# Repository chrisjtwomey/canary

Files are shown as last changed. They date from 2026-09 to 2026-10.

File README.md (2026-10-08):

# CANARY

CANARY shows the air in a room on a 5.2" e-paper display. It measures CO₂, particulates, gas (VOC),
temperature, humidity and pressure.

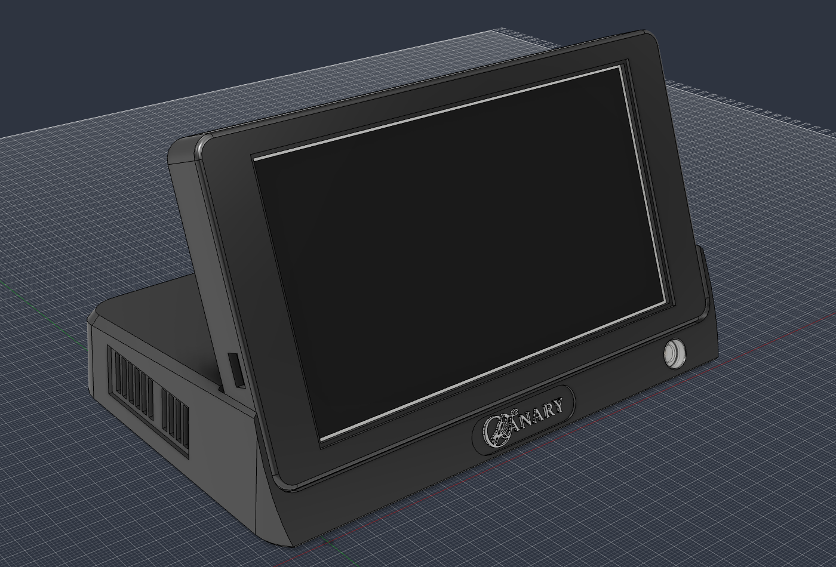
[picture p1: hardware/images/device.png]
CANARY on a desk


It has two halves and a server:

- The **dock** holds the sensors. It takes a reading every 5 minutes, and every 30 minutes from 01:00 to 07:00,
  and sends it to the server.
- The **display** stands on the dock. Every 5 minutes it shows the next page that the server draws from the
  readings.
- The **server** runs on a computer of yours. It keeps the readings, draws the pages, and can update the firmware
  on both boards. Its config sets the times above.

One USB-C cable powers the dock and the display.

| What | Part |
|---|---|
| CO₂ | Sensirion SCD41 (Adafruit breakout) |
| Particulates: PM1.0, PM2.5, PM10 | Plantower PMSA003I (Adafruit breakout) |
| Gas (VOC) and pressure | Bosch BME688 (Soldered breakout) |
| Temperature and humidity | Sensirion SHTC3 (Soldered breakout) |
| Display | Soldered Inkplate 5 Gen2 |
| Dock controller | Unexpected Maker TinyS3 |

## Build one

**You build the firmware yourself.** The dock uses Bosch's BSEC2 library to calculate the air quality index.
BSEC2 is closed source, and Bosch's licence does not let this project give out firmware that contains it. The
build downloads BSEC2 from Bosch, and Bosch's terms then apply to you. Read them first: the
[library's LICENSE.md](https://github.com/boschsensortec/Bosch-BSEC2-Library) links to them.

You need:

- The parts in [hardware/bom.md](hardware/bom.md). They cost about €220.
- A 3D printer with a 0.4 mm and a 0.2 mm nozzle, and a soldering iron.
- A computer that is always on, with Docker, on the same network as the device.
- A computer with a USB port and Chrome, Edge, Opera or Firefox, for the first install on each board.

### 1. Run the server

On the computer that is always on:

```sh
git clone https://github.com/chrisjtwomey/canary.git
cd canary
./setup.sh
```

- `setup.sh` writes `server/config.yaml` for a real install: the pages show your readings, the boards take new
  firmware from the server, and the time zone and the server's address are this computer's. It asks nothing, and
  it keeps a config that exists, so you can run it again at any time. Then it starts the containers.
- The second container builds the firmware for both boards. Its first build takes some minutes.
  To build again, restart the server with `docker compose restart`. `docker compose logs -f firmware-builder`
  shows the build.
- `http://<server>:8080/web/` shows the pages, and `/web/config` is the Settings page. Set your altitude there, in
  the Server tab, so that the pages show the pressure at sea level. **It has no login: anyone on your network can
  change the settings.**
- The readings, board reports, board logs, calibration copies and the HTTPS certificate go in the `canary-data`
  volume. They stay when Docker recreates the container.
- The images follow this repo's `main` branch. Your boards take each new version.

### 2. Install each board's firmware

The first install puts the firmware and your network settings on a board, over USB. After that, each board takes
its firmware from the server.

Install both boards before you build the device. The dock's USB-C socket carries power only. To install the dock
later, you must open it and lift the TinyS3 off its strips.

1. On a computer with a USB port, open `https://<server>:8443/web/install` in Chrome, Edge, Opera or Firefox.
   `setup.sh` prints the address. Your browser warns about the certificate first: select Advanced, then continue.
2. Enter your Wi-Fi name and password. Each saves when you leave its field. Change the server address if the
   boards reach the server by another name.
3. Connect a board with a USB cable, then select Install beside it. After the install the page checks that the
   board joins your Wi-Fi and reaches the server.

- A board's Install button appears once the server has built its firmware.
- Firefox asks to install an add-on for the site first, and it cannot install from an IP address: open the page by
  the server's name.
- Safari cannot install firmware. From a terminal on macOS or Linux, the same install is
  `curl -O http://<server>:8080/install-firmware.sh`, then `sh install-firmware.sh dock` or
  `sh install-firmware.sh display`.
- Behind a reverse proxy that has its own certificate, set the HTTPS port to 0 in Settings and open the page
  through the proxy.

To build and flash the boards with PlatformIO instead, as for development, see [docs/boards.md](docs/boards.md).

### 3. Build it

[hardware/assembly.md](hardware/assembly.md) builds the device in 12 steps, with a picture for each. Set aside a
day. The last step is the first power-up.

## Documentation

| Doc | What it tells you |
|---|---|
| [hardware/](hardware/README.md) | What is in the hardware folder. |
| [hardware/bom.md](hardware/bom.md) | The parts to buy, and what else would do. |
| [hardware/assembly.md](hardware/assembly.md) | How to build the device, step by step. |
| [hardware/enclosure.md](hardware/enclosure.md) | The design of the printed parts, for changes to the model. |
| [docs/architecture.md](docs/architecture.md) | How the firmware and the server work. |
| [docs/readings.md](docs/readings.md) | The data that each board sends. |
| [CONTRIBUTING.md](CONTRIBUTING.md) | For developers: the setup, the tests, and where the other developer docs are. |

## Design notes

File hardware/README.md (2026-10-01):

# Hardware

CANARY has two halves in one desk enclosure:

- The **display** is an Inkplate 5 Gen2: a 5.2" e-paper panel, tilted 20° back. It shows the pages that the server
  draws.
- The **dock** is a TinyS3 with four sensors: CO₂, particulates, temperature and humidity, and gas. It reads the
  room and sends the readings to the server.

The display stands in the dock. An 8-pin magnetic connector carries 5 V up to it, and it is the only connection
between the two halves. One USB-C cable into the dock powers both.

On the desk, it is 150.7 mm wide, 87.3 mm deep and 89.8 mm tall.

The finished device

| Doc | What it tells you |
|---|---|
| [bom.md](bom.md) | The parts to buy, what else would do, and the cost. |
| [parts.md](parts.md) | The datasheet facts for each part, and the power and the I²C bus. For developers. |
| [assembly.md](assembly.md) | How to build it, step by step, with a picture for each step. |
| [enclosure.md](enclosure.md) | The design of the printed parts, for a person who changes the model. |

| In this folder | What it holds |
|---|---|
| `stl/`, `3mf/` | The five printed parts, in print orientation. |
| `step/` | The same parts as STEP, each upright in its own frame. |
| `enclosure.py` | The design: a Fusion script that places each board and builds each part from the numbers in `enclosure.md`. |
| `canary-logo.svg` | The logo's outline in millimetres. The script imports it. |
| `images/` | Views of the model, and the wiring drawings, for the guides. |
| `wiring/` | The circuit as YAML, one file for each run of wire ([wiring/README.md](wiring/README.md)). |
| `logo/` | The source picture, and the script that traced it. |

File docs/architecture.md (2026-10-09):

# Architecture

How CANARY's firmware and server work. This page is the overview, and each topic has a doc of its own. The
hardware is in [hardware/README.md](../hardware/README.md).

## The parts

- **The dock** (TinyS3, `src/dock/main.cpp`) reads the four sensors at the server's slots, queues each reading in
  PSRAM, and posts the queue to the server. It stays online, and light-sleeps between passes of its loop.
- **The display** (Inkplate 5 Gen2, `src/main.cpp`) wakes for each page. It fetches the page, draws it, posts its
  own status, and deep-sleeps. E-paper keeps its image with no power.
- **The server** (`server/`) keeps the readings, draws the pages, holds the schedules and the dock's settings, and
  offers firmware to both boards.

| | Dock | Display |
|---|---|---|
| Board | TinyS3 (ESP32-S3) | Inkplate 5 Gen2 (ESP32-WROVER-E) |
| Between tasks | Light sleep, with Wi-Fi kept | Deep sleep |
| By default | A reading every 5 minutes, and every 30 minutes from 01:00 to 07:00 | A page every 5 minutes, and a sync every 30 minutes |
| Asks the server | `POST /sensor-readings`, `GET /board-settings`, `POST` and `GET /calibration`, `GET /about` | `GET /<page>.png`, `POST /sensor-readings` |
| Power | 5 V from the USB-C socket | 5 V from the dock, through the pogo connector |

## Why two boards

The panel and the sensors are on two boards, in two halves of one enclosure. The display is the Inkplate and
nothing else: its I²C bus carries only its own expander, RTC and panel PMIC, and its regulator carries only itself.
The dock has the four sensors, on a regulator of their own. Three facts forced this
([hardware/parts.md](../hardware/parts.md)):

- **The bus.** With the sensors on the Inkplate's bus, a jammed sensor also stopped the panel refreshes and the
  panel's temperature read, because the expander, the RTC and the PMIC share that bus.
- **The rail.** The Inkplate's regulator gives 500 mA, and it also carries the ESP32 and the panel PMIC. The sensors
  alone peak at about 470 mA.
- **Heat and noise.** The SCD41 needs a supply free of Wi-Fi bursts, and the TinyS3's own regulator would reach
  thermal shutdown if it carried the sensors.

The only connection between the two halves is the pogo connector, which carries 5 V and ground to the display.

## What comes from epd

CANARY uses [epd](https://github.com/chrisjtwomey/epd) for the generic parts, and adds its sensors and its pages.
The kit is a library, not a framework: it does not need to know what a sensor is.

- **Firmware:** epd's Wi-Fi, time, download, `postJson`, back-off and log helpers. The display also uses the image
  helpers and `IBoard` (`EpdBoardInkplate`, built with `-DARDUINO_INKPLATE5V2`). The dock needs no board.
- **Not `run_app()`:** that is epd's deep-sleep program for a board that only draws pages. Each board here does
  more, so each has its own program.
- **Server:** `DisplayServer`, `Page`, `regenerate()`, `DataSource`, the config loader, the readings store and the
  MQTT log relay.
- **Rendering:** `GreyscaleQuantiser` at eight levels, for the panel's eight greys.
- **The wire contract:** `GET /<page>.png`, with the headers that say when to fetch next and what
  ([versions.md](versions.md)).

## Topics

| Doc | What it covers |
|---|---|
| [dock.md](dock.md) | The dock's loop, its clock, the readings queue, and the sensor code |
| [display.md](display.md) | The display's wakes, its notices and its splash screen |
| [schedules.md](schedules.md) | When the page changes, when the dock takes a reading, and when the display syncs |
| [led.md](led.md) | The dock's status LED |
| [versions.md](versions.md) | The headers, `/about`, which versions work together, and firmware updates |
| [dock-settings.md](dock-settings.md) | The dock's settings, which the server holds |
| [readings.md](readings.md) | The JSON that each board posts |
| [simulator.md](simulator.md) | The simulated room and the mock sensors |

## The repo

```
platformio.ini                 envs: esp32 (the display), dock (the TinyS3), dock-mock (-DUSE_MOCK_SENSORS), dock-validate, native, sim;
                               a -dev twin of each board env builds against an epd checkout
partitions.csv
src/main.cpp                   the display: fetch, draw, post its own state
src/dock/main.cpp              the dock's loop (dock.md)
src/defaults.example.cpp       copy to defaults.cpp: Wi-Fi, server URL, MQTT logging
include/sensors/  src/sensors/
  Readings.h  ReadingsJson.cpp                  what the sensors return, and the wire format in readings.md
  IShtc3.h  IScd41.h  IPmsa003i.h  IBme688.h    one interface per part, shaped by its datasheet
  IClock.h  II2cBus.h                           the clock and bus seams
  SensorSuite  SensorHealth                     the four sensors as one begin() and one sample(), and how they fare
  Shtc3Driver  Scd41Driver  Pmsa003iDriver  Bme688Driver  SensirionI2c  Pmsa003iFrame
  IBsec.h  BsecRunner  BsecLibrary              BSEC, in a task of its own
  SensorValidation                              the bench routine's checks
  mock/                                         EnvModel, LaggedValue and the four mocks
include/net/  src/net/         Backlog, BoardSettings, Calibration, ClientStatus, ResetReason, ServerClock, Stamp, Url
include/dock/                  StatusLed (led.md), FanWindow and PostTimer: when the fan runs and the next reading falls;
                               Trial: when a new image is rolled back (versions.md)
include/display/               when the display wakes, what it does after a fetch, and the notices it draws (display.md)
src/notice.cpp                 the notices, with the facts only the display knows at run time
src/splash.cpp                 the splash screen, and the update's progress bar under it
include/display/notices/       the notices, rendered by scripts/notices.py from server/pages/notice.py
include/display/splash.png     the splash screen, rendered by scripts/notices.py from server/pages/splash.py
include/display/fonts/         the pages' face as one-bit fonts, from scripts/gfxfont.py, for the lines the display writes
src/sim/main.cpp               the sensor loop as a host binary
src/validate/main.cpp          the bench routine
lib/bme68x/                    Bosch's BME68x API
scripts/                       bsec.py, dock_core.py, gfxfont.py, notices.py, version.py
test/                          host tests, native env
setup.sh                       the first start: runs docker-compose.yml's setup service, then starts the stack
server/
  server.py                    config, sources, pages, DisplayServer(...).run()
  setup.py                     the setup service: config.yaml from the example, set for a real install, and firmware/
  about.py  version.py         GET /about, and what this server calls itself
  web.py  html_doc.py          /web/: the pages in a browser, the explorer, and GET /history
  install_page.py              /web/install: epd's install page in this site's layout, with the boards' network
                               settings above the boards
  config_page.py               /web/config: config.yaml as a form in tabs and as text, checked, saved, and restarted on;
                               whether each board runs the saved settings
  config_form.py               the form's fields, and how a filled-in form edits config.yaml
  transfer.py                  a store out to a file and back in, and what it holds, for the Storage tab
  board_logs.py                what each board logs over MQTT, for the Logs view
  schedule.py                  the dock's reading slots (schedules.md)
  broker.py                    the MQTT broker the boards get when config.yaml names none for them
  off_hours.py                 the splash screen while the page schedule is off (schedules.md)
  after_reading.py             each page made after the dock's reading at its slot, and the display's wake after
                               that (schedules.md)
  dock_settings.py             the dock block and GET /board-settings (dock-settings.md)
  display_settings.py          whether the display runs the saved display and image blocks (schedules.md)
  sources/                     the mock room, readings ingest, calibration store, device status, the corrections
                               the pages see: sea-level pressure, and no IAQ below accuracy 2
  pages/                       Breathe, Comfort, Dust, Air, Day, the Diagnostics pages, the trace and delta pages, and
                               the splash screen with its logo
  metrics.py                   derived values and wording; the comfort edges, ISO 7730's PMV, and their words
  static/                      CSS, fonts, charts.js; web.css, browse.js, explore.js, config.js, sheet.js,
                               install-form.js and install-sketch.js for /web/
  config.example.yaml
hardware/                      the boards, the desk enclosure and how to build it (hardware/README.md)
docs/                          these docs, and the developer guides that CONTRIBUTING points to
```

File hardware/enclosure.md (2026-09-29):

# The enclosure

The design of the printed parts, for a person who changes the model. To print and build the enclosure, you need
only [bom.md](bom.md) and [assembly.md](assembly.md).

The enclosure holds the Inkplate 5 Gen2 and the four sensor boards: a thin display, tilted 20° back, stands in a
low sensor dock that extends behind it. It has rounded plan corners, drafted walls, a continuous shadow gap in
place of grilles, and no fixings that show from a normal angle.

The design is in Fusion (project **CANARY**, design **CANARY**). `enclosure.py` makes every part, every board
placement and the wiring layers again from the numbers in this file.

The four enclosure parts print in **PLA+ with a 0.4 mm nozzle**. The logo needs the **0.2 mm nozzle**, and prints
in white on its own plate.

On the desk: **150.7 wide × 87.3 deep × 89.8 tall mm**. The dock's top is one plane, 33.9 mm tall at the front
edge and 25 mm at the rear, 5.15°. The rear is set by the TinyS3's USB-C under the skin; over the PMSA003I's
header the Dupont housings and the wires arcing over them have 1.4 mm to spare, see
[assembly.md](assembly.md#8-wire-the-dock).

## Working on the model

`enclosure.py` is the design. The Fusion document is not in this repository: the script builds the whole thing in
an empty design, and downloads the Inkplate, Adafruit and pogo STEP models it places. Fusion's own copy holds the
saved milestones.

- Run it from **Fusion's script editor**: Utilities → Scripts and Add-Ins → the green **+** beside "My Scripts",
  pick the file, then Run. A full run takes a few minutes and needs a network connection the first time, for the
  STEP downloads.
- It is **re-runnable**. Every part is rebuilt from scratch each time, and components are reused by name, so
  nothing is duplicated. Edges rounded by Fusion features are found geometrically, not by index.
- The report it prints at the end is the check: `lumps_must_all_be_1` (each printed part is one solid),
  `inkplate_insertion_blocked_mm3` (the board can still go in), `cover_pullout_blocked_mm3` (the cover cannot
  drop out of the tray), `interference`, `printability` and `wiring`. The pull-out figure must be more than 0.
  All the others must be empty or 0: a part that touches another lands on it, it does not overlap it.
- **Exports** are made in a second step, never in the same run as the build: the transformed bodies first, the
  export calls after, or Fusion writes empty files.

## Shape

It is meant to sit on a desk without announcing itself, which drove the architecture:

- **The sensors live in the dock, not behind the display.** That keeps the centre of mass low (below) and lets the
  display be only 14 mm thick.
- **The dock is a chassis inside a shell.** The shell is one uninterrupted skin; all four of its screws come up
  from underneath through the chassis, so nothing breaks the top or the sides.
- **The front is one continuous 20° slab.** The display's bezel and the dock's front face lie in the same plane
  with only a parting line between them. At the sides the dock's walls frame the display, 1.3 mm outside it at the
  top. Two other shapes would work: side walls that stop behind the display, with a 2 mm shoulder round its bottom
  corners; or no side draft, so the display is flush with the dock's sides the full height, which looks boxier.
- **Nothing is square.** 10 mm plan radii on the dock and 5 mm on the display, a 1.5 mm chamfer round the top edge and
  a 1.2 mm round on the bezel, and 4.3° of draft on the side and rear walls so the dock reads as a foot, not a box.
- **The vents are hidden.** A 1.5 mm shadow gap under the whole shell replaces every grille; the only visible
  openings are the PMSA003I's, sunk in a recessed strip on the left wall.

## Stability

- Mass ≈ 280 g: 92 g Inkplate, 52 g display shells, 145 g dock and boards (PLA+ or PETG at ~1.24 g/cm³, printed
  near solid).
- The centre of mass is **≈ 27 mm above the desk and 32 mm back**. That was worked out for a dock 3.5 mm lower,
  and the difference moves it by less than a millimetre.
- Only the chassis touches the desk (X −7.1…132.4, D 3.5…82.5). So the device tips only at ≈ 46° forward, 62°
  backward or 68° sideways.
- The sensors in the dock give that margin. In the display, they would be 40 mm higher.

## Parts

| Part | Print orientation | Fixings |
|---|---|---|
| **Display tray** | face down | Bezel (2.4 mm lip) and four walls, 14.1 mm deep, 5 mm plan radii, 1.2 mm round on the bezel edge. Right wall 7.3 mm thick, carrying the USB-C, power-button and microSD pockets; left wall 2 mm with the wake-button hole. The rear edge of the walls carries what holds the cover: a 1 mm step all round as its seat, two tongue slots in the thin wall, and two ear pockets with heat-set inserts in the thick wall's corners. No vents. |
| **Display back cover** | flat, outside down | 2 mm plate resting on the Inkplate's four 7.2 mm SMT standoffs and screwed to them: 4 × M3 through clearance holes, counterbored 0.7 mm so the heads sit near flush in a 2 mm plate. It holds the tray with two 12 mm tongues on one side edge and two ears on the other, each ear screwed to an insert in the thick wall. It goes on tilted, tongues first, and swings down. One grille band over the ESP32 (8 capsule slots, X 74–94, Y 14–40) — the display's only opening, facing up and back. |
| **Dock chassis** | upright (desk face down) | Floor, the solid 20° cradle block with the display pocket, and every bay feature: board bosses, the SCD41 compartment, the SHTC3 baffle, the AMS1117 pocket. It also carries the pogo plinth standing in the trench. Nothing fastens the display: the connector's two Ø5 magnets hold it down and the cradle pocket locates it. It also carries the TinyS3's cradle, whose channel is the dock's wiring duct, the USB-C socket's holder by the rear wall, and the status LED's access pit. |
| **Dock shell** | upside down (top skin on the bed) | The visible skin: rounded, drafted walls, the sloped top and a 2 mm front wall under the display, in one piece with no top-side fixings. 4 × M3×8 countersunk up from underneath into heat-set inserts in its internal pillars, which stand on 1 mm bosses on the chassis floor (×10 bottoms out — the insert ends at 8.7 mm). A Ø4 post holds the AMS1117 module down, and the PMSA003I's seal rib is part of this wall. |

0.4 mm nozzle, 2 mm walls and skin, 2.2 mm slots on a 3.4 mm pitch where slots remain. The shell prints upside
down so its whole outer surface is either on the bed or a drafted wall — no supports; the STL is rotated 5.15° past
the flip so the whole skin lies flat on the bed. Everything is printed in **PLA+**: the only heat in the dock
is the AMS1117's few hundred milliwatts, so PETG is the fallback if its pocket or the shell post over it ever
softens.

**Nothing stands inside the display's cavity, and nothing may.** The Inkplate is 130.59 × 75.23 in a 134.6 × 77.2
opening: 2 mm a side in X, because SW2 and the wake switch stand 0.85 mm past the board's left and right edges,
and 1 mm at the top and bottom. The board goes in from the back, so its footprint sweeps the whole cavity on the
way to its seat. A boss in the cavity would stop it, however far behind the seated board the boss is. So the
cover screws to the Inkplate's own standoffs, and magnets hold the display.

SW2 and the wake switch sit 1.15 mm behind the walls' inner faces, so a finger cannot reach them. Press them
with a pin. If a switch must take a finger, fit a printed plunger in its hole before the Inkplate goes in, with a
flange inside the wall to hold it. SW2 is bypassed (R34 bridged), so the wake switch would get a plunger first.

The cover goes in from the back in a straight line. So only a feature that engages after the cover is in can
hold it:

- Two tongues on its thin-wall edge go into slots in that wall.
- Two ears at the other end sit in pockets in the thick wall, and screw into inserts.

All of it is cut into the walls, so the board still passes. With the panel facing up, the tongues and the two ear
screws carry the Inkplate. `enclosure.py` reports what stops the cover from dropping straight out as
`cover_pullout_blocked_mm3`, which must be **more than 0**.

- A step for the cover's edge alone holds nothing: it stops the cover in the same direction as the bezel lip.
- Clips are not used: PLA+ ridges wear.

The bezel lip stands 0.15 mm clear of the panel, and the tongues have the same play in their slots. A wall that
prints that much short therefore cannot make the ear screws press the lip on to the glass.

## Fasteners

Six brass heat-set inserts carry the screwed joints between printed parts: four hold the shell on the chassis,
and two hold the back cover's ears on the tray. The back cover also screws into the Inkplate's own standoffs. The
pogo connector's two magnets hold the display down. All other screws go straight into printed plastic.
[bom.md](bom.md) gives the quantities to buy.

| Fastener | Qty | Where | Hole |
|---|---|---|---|
| M3 heat-set insert (≈ 5.7 long, 4.6 OD) | 6 | Dock shell, internal pillars (4); display tray, thick wall corners (2) | Ø 4.0 × 6.0 deep |
| M3 × 8 countersunk, 90° | 4 | Shell → chassis, up from underneath | Ø 3.4 clearance, Ø 6.2 × 1.4 cone |
| M3 × 6 machine screw | 6 | Display back cover → the Inkplate's four SMT standoffs (4) and the tray's two inserts (2) | Ø 3.4 clearance; Ø 6.2 × 0.7 counterbore over the standoffs only |
| M2 × 4 self-tapping, pan head | 8 | PMSA003I and SCD41, 4 each | Ø 2.1 pilot, 3 mm deep |
| M2.5 × 4 self-tapping | 8 | BME688 and SHTC3, 4 each | Ø 2.6 pilot, 3 mm deep |

- Board pilots are blind, in 2 mm bosses on the chassis floor: 3 mm of engagement with 1 mm of floor left under
  them, so no screw breaks the desk face. Two screws per sensor board carry a few grams comfortably; all four holes
  are there if wanted.
- **Board screws are one nominal size under their pilot** *(measured on a PLA+ print)*, for two separate
  reasons. The PMSA003I's board holes are 2.5 mm, so an M2.5 screw cannot pass through one — M2 is the only option
  there, and the SCD41 takes the same screw for consistency though its 3.0 mm holes would also accept M2.5. The
  Soldered boards' 3.2 mm holes would pass M3 happily; what rules M3 out is the printed pilot, since Ø 2.6 nominal
  finishes nearer 2.4 on an FDM print and a thread-former that tight in PLA+ splits the boss. Do not re-cut the
  pilots to suit the smaller screws: they are sized for how the hole prints, not for how it reads in CAD.
- Every self-tapper is sized to stop **short of the blind end of its pilot**, not to fill the material: a tapered
  tip driven into the last millimetre wedges the boss open. A 1.57 mm board plus 3 mm of pilot leaves 4.6 mm,
  hence 4 mm screws and 2.4 mm of engagement — short of the usual 2 × diameter, but these are five-gram boards.
- The shell screw stops at 8 mm: it passes 3 mm of floor and boss and holds 5 mm of the insert, which ends at 8.7, so an M3 × 10 bottoms out.
- The cover's counterbore leaves 1.3 mm of plate under each screw head, so an M3 × 6 puts about 4.7 mm of thread
  into the 7.2 mm standoff.
- Self-tapping into PLA or PETG holds fine for a one-time build. If boards will come in and out repeatedly, those
  pilots strip after a handful of cycles and want inserts instead — which means taller, wider bosses.

## Frames

**Display frame**: X left → right seen from the front (the Inkplate PCB spans 0…130.59), Y up (PCB 0…75.23), Z
toward the viewer with Z = 0 at the panel's front face. In Fusion, X_f = X, Y_f = −Z, Z_f = Y. Z levels: bezel
front +2.4 · panel 0 · PCB back −2.45 · standoff tops / cover inner −9.67 · cover outer −11.67.

**Dock frame**: X as the display, D = depth from the front-bottom edge (0…86 nominal, 87.9 including the draft),
H = height above the desk. This is Fusion's world frame; the `Dock` component is untilted and the `Display`
component carries the 20° tilt. Bay interior X −8.6…133.9, D 25…84, H 2 up to the skin's underside (28.5 at D 25,
sloping to 23 at the rear). Board component faces at H 5.6 (Adafruit / Soldered) and 6.0 (AMS1117, raised so the
regulator on its underside hangs in free air).

Inside `Dock`, only the chassis and the shell sit at the top level. Every board, the pogo female and **Dock wiring
(toggle)** sit in **Dock electronics (toggle)**; switch its light bulb off to see the bare printed parts.

The display's front-bottom edge lands at D 4.91 / H 13.5, chosen so the **bezel plane passes through (D 0, H 0)** —
that is what makes the dock's front face and the bezel one plane. Change `DISPLAY_FRONT_H` and the front slab
follows automatically.

## Surfacing rules

- **Plan corners** are built into the solid, not filleted: the shell's outer prism is four truncated cones
  (r 10 mm at the top, growing with the draft) plus two tilted-plane slabs. The cavity uses r 8 and the chassis
  r 6.5 about *the same centres*, so the wall stays 2 mm and the chassis-to-shell gap stays 1.5 mm all the way
  round the corner.
- **Draft** 4.3° on the sides and rear, referenced to the top of the walls: 2.0 mm wider at the desk than at the
  top, where the shell stands 1.3 mm outside the display's sides. The front (bezel) plane and the cavity are not
  drafted. Flush with the display, the draft would carry the side walls out past its vertical sides to a knife edge;
  1.3 mm out, the wall beside the display is 0.8 mm at the top of the walls and thickens down the draft.
- **The top chamfer is also solid geometry.** A 2 mm skin cannot carry a fillet larger than 1.17 mm — the arc
  breaks through into the cavity at the corner — whereas a 45° chamfer of leg *c* only eats (4 − c)/√2, so 1.5 mm
  is comfortable. It is made by intersecting the shell with a 45°-drafted prism whose reference plane is rotated
  onto the sloped top, which also wraps it around the rounded corners. Fusion's own chamfer feature fails here
  (`ASM_BL_UNFIN_SHEET`) because the chain runs out onto the display opening's curved wall.
- Only two rounds are real features: the bezel's outer edge (1.2 mm, limited the same way by the 2 mm wall and
  2.4 mm lip) and the shell's bottom rim (0.8 mm chamfer). Both are picked geometrically, so the script re-runs.

## Ventilation

There are no grilles on the top, the right side, the rear or the display.

- **Shadow gap.** The shell's bottom rim floats 1.5 mm above the desk and the chassis is inset 1.5 mm from the
  shell's inner wall, so the gap is not decorative: room air passes under the rim, up the slot between chassis
  and shell, and into the bay. Open area ≈ 390 mm² along the bay's sides and rear.
- **PMSA003I.** The fan needs its own path and cannot use the gap: its inlet and outlet are both on the face
  against the left wall, 8 mm above the gap and up to 40 mm away. So that wall keeps two real slot groups
  (D 41.4–54.5 for the outlet, D 58.4–78 for the inlet), sunk in a 1 mm recessed strip so they read as one
  detail rather than a grille. A 4.6 mm rib on the shell's inner wall (D 54.8–58.1, H 1.5–19) crosses the 4.8 mm
  gap between that wall and the module's face, between the two slot groups, so exhaust cannot run along it into
  the inlet. It is on the shell, not the chassis: the chassis is inset 1.5 mm from this wall and could only reach
  it as a detached island. The 3.1 mm of rib that reaches over the chassis floor starts 0.2 mm above it, so the
  shell still drops on freely.
- **SCD41** breathes through its compartment's open front (≈ 500 mm² facing the bay) rather than a lid grille.
  If its response turns out sluggish, the fix is a slot row low in the compartment's left wall.
- **Display.** Sealed except for one grille band in the back cover: 8 stadium slots, 2.2 × 20 mm on the usual 3.4 mm
  pitch, X 74–94 and Y 14–40, ≈ 344 mm². They sit over the **ESP32-WROVER** (X 75–93, Y −0.2–31.8). It is the display's only real heat source, at
  80–150 mA while it is awake with Wi-Fi, and it sits directly behind the panel. It deep-sleeps between pages. The slots run
  **along X**: everything else about this object is horizontal — the shadow gap, the PM's vent strip — and vertical
  ticks cut across all of it. One band spanning low to high also vents better than two discrete ones, since the 20°
  tilt makes the bottom rows the intake and the top rows the exhaust. Y 14 is the lower limit: the display's five wires
  cross the board at Y 3–11 and would otherwise show through.

### Heat

| Source | Dissipation | Note |
|---|---|---|
| Whole dock, averaged | ~0.25 W | 48.9 mA at 5 V with light sleep and a reading every 5 minutes *(measured, [parts.md](parts.md#tinys3--the-dock))* |
| AMS1117, while the PM fan runs | ~0.19 W at 110 mA | 1.7 V dropped. A SOT-223 on the module's copper runs ~70 °C/W, so the tab sits about 13 °C above the room. Rated 125 °C. |
| PMSA003I, while its fan runs | ~0.3 W | 95 mA at 3.3 V *(measured)*. It vents straight out through the left wall. |
| Sensors | < 0.1 W | |

The PM fan runs only for the 35 s before each reading, so its rows are peaks, not averages.

There is no fan. Under a watt in a vented dock warms the air near the parts by a degree or two, and the far
corner not at all. A fan would blow over the SHTC3, stir the SCD41's compartment, and move the BME688's heat
about. So both heaters sit on the PM side, as far from the SHTC3 as the layout allows.

---

## Bay layout

Each board's place follows the placement rules in its section of [parts.md](parts.md):

- **SHTC3**: at a corner or edge, in the incoming airflow, slit-isolated from any mounting plate, nowhere near the
  Inkplate's LDO, PMIC or ESP32 or the PM fan's exhaust. It sets the reading everyone sees.
- **PMSA003I**: inlet and outlet against an enclosure wall or separated by a baffle; enclosure vent no smaller than
  the inlet; ≥ 20 cm off the floor; its exhaust pointed away from the SHTC3 and SCD41.
- **SCD41**: its own compartment with a large opening, small dead volume, out of the direct airflow, lowest point
  of the device, away from the fan and the Inkplate's warm parts. Membrane untouched.
- **BME688**: anywhere with air access; its heater is a heat source for the others, so not adjacent to the SHTC3.
- **Inkplate**: the ESP32, LDO and panel PMIC are the warmest parts; the sensors go on the opposite side or in a
  ventilated bay.
- Vent the sensor bay on two sides so air moves through rather than pooling.

| Board | X × D (mm) | Placement |
|---|---|---|
| PMSA003I | −3.8…31.8 × 27…77.8 | Left end, module face 4.8 mm from the left wall and its vents. X −3.8 puts the board edge and its two left bosses 3.3 mm inside the edge of the chassis floor (which is inset 1.5 mm from the wall). Header row along its **front** edge, so the tall Dupont housings stand behind the display where the dock is deepest. D 27 (not 30) keeps its rear corner clear of the cavity's 10 mm rounded corner. |
| SCD41 | 49.9…72.8 × 35…60.4, sockets facing front and rear | Middle, in its own compartment (walls X 47.3–48.8 and 74.3–75.8 from D 30, rear wall D 72–73.5, all to the skin). Both sockets in use; nothing else is connected to it. |
| SHTC3 | 82.8…120.8 × 26.5…48.5 | Front-right: coolest corner, against the solid cradle block, farthest from the fan and the LDO, behind a full-height baffle at D 50–51.5. End of the chain, only its right socket used. |
| BME688 | 82.8…120.8 × 53.5…75.5 | Rear-right, behind the baffle. Both sockets in use. |
| AMS1117-3.3 | 8…20.5 × 80.5…89, **across the bay, pins to the right** | Behind the PM board, its header end towards the TinyS3's channel. No mounting holes: it sits in a pocket 0.5 mm clear of the board on every side (0.3 mm a side would give a 9.1 mm slot, too tight to trust an FDM print with), with 1 mm locating walls and 2.5 mm corner tabs, so the underside is open. The board rests on a pad under its header's solder domes (they stand 1.2 mm proud) and on two solid corners at the far end either side of the SOT-223 (to H 6.0, the PCB's underside), so the regulator hangs in a 2.3 mm air passage — no floor slots, nothing to bridge. A Ø4 shell post at (15.5, 84.75), on the board's centreline, lands on it and stops it lifting (until the shell is on, the module is loose); a 3 mm cone at the post's root keeps it printable upside down. Dupont housings on its three pins run **right**, to X 35.8. |

The four shell pillars sit at (68, 30), (125, 30), (50, 77.5) and (125, 76) — plan positions clear of every board,
plug, ribbon and wire lane, **and far enough in from the chassis edge for the countersink on the underside to keep
a full wall outside it**. The corner is the trap: the chassis corner is r 6.5, so out there the edge curves away
on two sides at once and the *further into the corner the hole goes, the worse it gets*. The useful position is
near the corner arc's centre (125.9, 76), not near the corner itself. Each hole keeps **≥ 1.7 mm** of wall, and
each is limited by the thing it sits beside: 0.7 mm of drop-on clearance to the SHTC3, 0.5 mm to the SCD41
compartment's rear wall, 0.7 mm to the BME688. The countersink is Ø6.2 × 1.4 deep at 90°: an ISO 7046 M3 head is
5.5 across (5.6 max), so a Ø6.6 cone would give away 0.4 mm of wall for nothing, and the smaller cone leaves
0.6 mm rather than 0.4 of floor above it.

The left third of the shell has no pillar (the PM board leaves 6 mm at the rear and 2 mm at the front, and a
pillar needs 9); it is held by the skin and located by the cradle block.

### Cable lanes

The three Qwiic ribbons stay at board height (H 7.1), lie flat, and bend as a ribbon does, their conductors
1.1 mm apart and concentric round every corner. The PM ribbon runs down the lane at X 44.3 and along the bay's
front into the SCD41 compartment. The SCD41 → BME688 ribbon runs back to D 69.5, across, and slants through a
notch in the compartment's right wall (D 60.1–68.9). The BME688 → SHTC3 ribbon runs up the right-hand lane at
X 126, through a notch in the baffle (X 119.7–128.5); it has 3.2 mm to turn out of each plug, so its bends are
3.2 rather than 4.

Both notches are **8.8 × 6 mm**. A JST-SH plug is 6.8 × 2.7 and has to be threaded through them, so each notch
is the plug plus a millimetre a side. **Size them from the plug, not the ribbon.**

The right-hand lane sits at X 126, not hard against the chassis edge, with a **guide rib at X 128.5–132.4, 7 mm
tall, from D 35 to 67**. At 129.1 the ribbon would overhang the chassis edge with only the shell's inner wall to
hold it in: it would have to be stuffed in as the lid came down, and would spring out every time the lid came
off. The rib is that wall, and the shell drops on without touching the cable.

### Wire routes

The TinyS3's cradle channel is the dock's duct: it runs the length of the cradle, is open at both ends under the
board, and carries every wire that crosses behind the sensors. Wires stack in it by height, so they never cross —
the joints on the 5V row's legs lowest at **H 4.6**, then the pogo pair at **H 8.5**, the AMS1117 pair at **H 11.6**, and
the LED pair just under the board at **H 15.8**. The two splices sit in the channel's middle, X 60–68.

- **The strips.** One 12-way for the 9-8-7-6 row and one 11-way for the 5V row, cut from standard 20-way
  single-row female strips.
  They measure 11.6 mm from leg tip to socket face, 8.4 mm of it plastic, and 2.4 mm wide *(measured,
  calipers)*. The model uses 8.5 mm of plastic, 3 mm legs and 2.5 mm width. The TinyS3's own headers are
  soldered long pins down, and their plastic spacer is 2.5 mm *(measured)*.
- **The cradle.** Each strip sits in a pocket, its outer edge on a ledge along the pocket's outer wall and its
  two ends on end blocks. The ledge stops 0.6 mm from the row's centre and its underside is 1.2 mm below the
  strip, so a joint on the lower half of a leg passes under it. Nothing stands between the two strips, down to
  the floor. A rib inside the shell stands 1 mm above the TinyS3's USB-C, so with the shell on the board cannot
  lift off its strips.
- **The pogo pair.** Each wire meets its tail's tip end-on from below, in a chamber under the plinth, drops to
  the chamber's floor, runs back along it, and leaves under the plinth's back wall at **H 3.9** into the trench.
  In the trench the two become a bundle: left along it, up the strip between the PM board and the SCD41
  compartment — under the Qwiic ribbon, over the PM group — and along the channel to the splices' left ends.
- **The AMS1117 pair.** VBUS and GND leave the splices' left ends straight along the channel into the IN (rear)
  and GND (front) housings at pin height. **AMS OUT → PM VIN** leaves the middle housing over the GND wire, runs
  forward at **H 13.3** over the PM group's lanes, up to a lane under the skin, across the PM module and down
  into its VIN housing.
- **The PM group.** Cable 1's three conductors and SET leave their legs pointing into the channel, turn onto
  their lanes, and run as one bundle left along the channel, up the strip, over the ribbon at **H 10** and left
  along the front of the bay.
- **The LED pair.** Rearward over the SHTC3's right end, left of the shell pillar at (125, 30), onto the ribbon
  lane at X 126, up past the BME688 and across the bay behind it. At X 86 they part: IO6 into the channel's
  right end and down onto the TinyS3's pin 6; GND onto the GND splice's right end.

**Clearance above the PM header.** The PM board's **straight** 7-pin header is on its front edge at D 29.5, with
five housings on it whose tops reach **H 22.1**. A housing is entered from the top, and the display's back cover
leans over the row from the front, so wires must come over the housings from behind: SCL, SDA and GND climb
between the SET housing and the PM's socket B to lanes at **H 26.8**, 1.4 mm under the skin. A housing is 14 mm
tall and a wire needs about 3.7 mm above it to turn without strain, so the design keeps **17.7 mm clear above
the header block** *(measured on the real parts)*.

**In the display**, the back cover sits on the Inkplate's own 7.2 mm standoffs, and each of the two wires takes one
lane in that space.

**The AMS1117's pins** sit at D 87.3 (GND), 84.8 (OUT) and 82.2 (VIN), with their housings running right to
X 35.8 at H 11.6.

**The USB-C holder.** The left ear's seat stops 0.3 mm behind the B5 resistor, to leave room for it.

### The pogo junction

The pair is centred on the device at X 62.65. Both halves are panel-mount parts fixed by their lips, each fitted
from inside its own shell.

- **Male, in the display.** Its nose fills the 2 mm bottom wall and stands 0.30 mm proud of the underside. Its lip
  is glued to the cavity floor between two locating ribs; its back band and tails are in open cavity.
- **Female, in the dock.** It drops into a plinth standing in the trench, its lip landing on a ledge with a glue
  relief inside the rim. Only its 1 mm boss stands above the plinth's rim. The plinth is open at the front above
  the ledge, and the shell's front wall closes it, 0.9 mm off the lip.

The boss enters the male's pocket, so the halves nest: the mated bodies come to 9.3 mm, not 10.3. The key is the
contact block's own outline — a rounded rectangle with one semicircle cut into the middle of its S-end wall — so
a half turned end for end fouls it and will not close.

The trench is X 42–84, D 9.5–26, floor at H 3, open at the top once the display is off.

## Display window

The ED052TC4 STEP model carries the active area as a 0.04 mm recess on its front face: 114.56 × 64.44 mm, in the
rotated frame at X 5.35–119.91, Y 5.39–69.84. The window is that plus 0.8 mm, with a 1 × 1 mm step outside. The
Inkplate is mounted rotated 180° from the STEP model's own orientation so USB-C, the power button and microSD exit
the **left** wall; the thick wall is on that side, keeping the visible bezel symmetric (13.9 mm each side, 7.6 mm
top and bottom).

## Sensor board models

`enclosure.py` downloads three vendor models:

| Model | Source |
|---|---|
| Inkplate 5 Gen2 board | [Soldered's hardware repo](https://github.com/SolderedElectronics/Soldered-Inkplate-5-Gen2-hardware-design), `OUTPUTS/V1.1.0/Soldered Inkplate 5 Gen2 3D.step` (31 MB). In the export the panel model sits at the origin; move it after a manual import. |
| Adafruit PMSA003I (4632), with the Plantower module | [Adafruit_CAD_Parts, `4632 PMSA003I`](https://github.com/adafruit/Adafruit_CAD_Parts/tree/main/4632%20PMSA003I) |
| Adafruit SCD41 (5190) | [Adafruit_CAD_Parts, `5187 SCD-40 C02 Sensor`](https://github.com/adafruit/Adafruit_CAD_Parts/tree/main/5187%20SCD-40%20C02%20Sensor). The 5187 and 5190 share one PCB. |

Soldered publishes no model for its two boards, so the SHTC3 (333032) and BME688 (333203) are built from the
docs.soldered.com pinout drawings and checked with calipers: 38.0 × 22.0 mm, 2 mm corner
radius, four Ø3.2 holes inset 3.05 mm (32 × 16 mm pitch), JST-SH sockets 0.5–5.5 mm in from each short edge and
centred on it, a 4-pin 2.54 mm header 1.6 mm from one long edge, 1.6 mm PCB, 3.0 mm sockets, 1.1 mm regulator.
The AMS1117-3.3 module is from caliper measurements: PCB 12.5 × 8.5 × 1.4 mm, no mounting holes, SOT-223 on the
underside 1.7 mm tall, a 3-pin right-angle header on the other face with a 6.9 mm overall stack and pins reaching
7 mm past the short edge.

## Printing check

Every part is one connected solid — verified in Fusion (`lumps == 1`) and again from the exported STLs. This is
worth re-checking after any edit to `enclosure.py`: because the parts are built by unioning primitives, a boss or
rib whose position drifts clear of the body it should touch silently becomes a second lump in the same body, and
the slicer will just plate it as a loose part with no indication of where it goes.

The display has a second check for the same reason. `enclosure.py` sweeps the Inkplate's footprint from the cavity
mouth to its seated position, intersects that with the tray, and reports the result as
`inkplate_insertion_blocked_mm3`. It must be **0**.

`enclosure.py` also reports `printability` for the four printed parts, for a 0.4 mm nozzle:

- `knives`: edges where two faces meet at less than 30°. It must be empty.
- `fail`: walls or gaps under 0.45 mm, about one extruded line. It must be empty.
- `warn`: walls or gaps from 0.45 to 0.8 mm, under two lines. It is empty on all four parts, so anything there is new.

Each entry is the thinnest point in a 3 mm cell, in the part's own frame (see Frames).

It also reports `wiring`, for the two wiring layers:

- `overlaps`: every pair of wires that pass through each other, with the volume shared. It must be empty.
- `under_floor`: bends under 3 mm that are not at a solder joint. It must be empty.
- `forced`: bends that got at least 3 mm but less than four diameters, because the straights either side had no
  room for more. Each is a place a wire has to be bent harder than it would like.
- `joints`: the bends at the solder tails, which are made tight on purpose.

Positions are in the layer's own frame (see Frames).

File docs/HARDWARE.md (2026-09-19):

# Hardware reference — CANARY

Working shorthand for development, distilled from the datasheets. Every
section links its sources. Facts are from the datasheet unless marked
*(product page)*, *(schematic)*, *(derived)*, *(measured)*, *(bench)* or
*(unverified)*. Dates, and the history behind the text, are in the
[Decision Log](#decision-log).

- [0. At a glance](#0-at-a-glance)
- [1. Inkplate 5 Gen2](#1-inkplate-5-gen2)
- [2. SCD41 — CO₂](#2-scd41--co)
- [3. PMSA003I — particulates](#3-pmsa003i--particulates)
- [4. BME688 — VOC / gas, pressure](#4-bme688--voc--gas-pressure)
- [5. SHTC3 — temperature and humidity](#5-shtc3--temperature-and-humidity)
- [6. The I²C bus](#6-the-ic-bus)
- [7. Power](#7-power)
- [8. Wiring](#8-wiring)
- [9. The enclosure](#9-the-enclosure)
- [10. Open questions](#10-open-questions)
- [Decision Log](#decision-log)

---

## 0. At a glance

| Device | Board | I²C addr | Supply | Current, typical | Current, peak | Library |
|---|---|---|---|---|---|---|
| Inkplate 5 Gen2 | Soldered | head; 0x20 0x48 0x51 on its own bus | 5 V through the pogo connector | 18 µA deep sleep *(product page)* | not published | Inkplate-Arduino-library ≥ 11.1 |
| TinyS3 | Unexpected Maker | the sensors' host | 5 V on its 5V pin | ~100 mA awake *(typical ESP32-S3 figure)* | ~350 mA TX bursts | Arduino-ESP32 |
| SCD41 CO₂ | Adafruit 5190 | 0x62 | 2.4–5.5 V | 15 mA @ 5 s periodic; 0.45 mA single-shot every 5 min | **175 mA typ, 205 mA max** (3.3 V) | Sensirion I2C SCD4x |
| PMSA003I PM | Adafruit 4632 | 0x12 | 5 V module; board makes its own 5 V from 3–5 V | ≤ 100 mA @ 5 V → **~200 mA from 3.3 V** *(derived)* | 250 mA / 100 ms fan start *(charge pump rating)* | Adafruit PM25AQI |
| BME688 gas | Soldered 333203 | 0x76 (JP1 → 0x77) | 1.7–3.6 V (board takes 3.3–5 V) | 0.9 mA (BSEC LP), 0.09 mA (ULP) | 17 mA heater | Bosch BME68x + BSEC2 |
| SHTC3 T/RH | Soldered 333032 | 0x70 fixed | 1.62–3.6 V (board takes 3.3–5 V) | 430 µA measuring, 0.3 µA sleep | 0.9 mA | Adafruit_SHTC3 |

**Bus:** no address conflicts. The four sensor boards' 10 kΩ pull-ups in parallel
are 2.5 kΩ, within spec at 100 kHz. All four connector systems (easyC, Qwiic,
STEMMA QT) are the same JST-SH 4-pin in the same order.

**Power:** the sensors run from an AMS1117-3.3 module on the dock's 5 V rail,
and each processor board's own regulator carries only that board. Sensor peaks
alone reach ~470 mA, against 500 mA for the Inkplate's regulator and a 1 × 1 mm
package for the TinyS3's. Details in §7.

---

## 1. Inkplate 5 Gen2

Sources: [product page](https://soldered.com/products/inkplate-5-gen2) ·
[docs](https://docs.soldered.com/inkplate/5v2/overview/) ·
[hardware repo (KiCad, schematic PDF, BOM, STEP, STL)](https://github.com/SolderedElectronics/Soldered-Inkplate-5-Gen2-hardware-design) ·
[Arduino library](https://github.com/SolderedElectronics/Inkplate-Arduino-library) ·
[board definitions](https://github.com/SolderedElectronics/Inkplate-Board-Definitions-for-Arduino-IDE) ·
[free GPIO](https://docs.soldered.com/inkplate/5v2/hardware/free-gpio/) ·
[deep sleep](https://docs.soldered.com/inkplate/5v2/low-power/deep-sleep/) ·
[RTC alarm](https://docs.soldered.com/inkplate/5v2/rtc/alarm/)

### Core

| | |
|---|---|
| Panel | E Ink ED052TC4, 5.17", **1280 × 720**, **3-bit grey (8 levels)**. Full refresh 0.99 s, partial 0.22 s. |
| MCU | ESP32-WROVER-E. **8 MB PSRAM** *(derived)*: the board reports 4.0 MB, the most an ESP32 maps at a time, and a WROVER-E carries either 8 MB or 2 MB. Flash **at least 4 MB** *(unverified)*: the variant sets 4, 8 or 16 MB, the shield prints no suffix, and `partitions.csv` uses 4 MB. Library allocates ~921 kB PSRAM for framebuffers. |
| Radio | Wi-Fi, BT 4.0 BLE |
| USB | USB-C, CH340C UART, 500 mA fuse on VBUS *(schematic)* |
| Battery | 2-pin JST-PH 2.0 mm, 3.7 V Li-ion, MCP73831 charger at ~400 mA *(schematic, R32 = 2.49 k)* |
| RTC | PCF85063A, CR2032 backup holder |
| Storage | microSD (SPI on IO12–15, switched rail) |
| PMIC | TPS65186 (panel rails), TPS7A2633 3.3 V LDO |
| IO expander | PCAL6416A |
| No | touchscreen, frontlight, 5 V boost converter |

Gen2 vs Gen1: 960×540 → 1280×720 panel, I²S DMA panel driver, same 130.6 × 75.2 mm board.

### I²C and easyC

- SDA **GPIO21**, SCL **GPIO22** *(schematic)*. `Inkplate::begin()` calls `Wire.begin()` at the default 100 kHz.
- One easyC connector, K3. Pads 1 = SCL, 2 = SDA, 3 = 3V3, 4 = GND *(schematic)*. The same four signals are on the bottom header.
- Soldered states easyC is pin-compatible with Qwiic and STEMMA QT: black GND, red 3V3, blue SDA, yellow SCL.
- Host pull-ups: R1/R4 **10 kΩ** to 3V3 on SCL/SDA. No jumper to remove them *(schematic)*.
- easyC 3V3 is the main 3V3 net straight from the LDO. No current limit is stated.

### Onboard I²C addresses

| Device | Addr |
|---|---|
| PCAL6416A IO expander (ADDR = GND) | 0x20 |
| TPS65186 PMIC | 0x48 |
| PCF85063A RTC | 0x51 |

No conflict with 0x12, 0x62, 0x70, 0x76/0x77.

### Power

- Inputs: USB-C 5 V or battery, both at once allowed; USB takes over via a P-MOSFET when present *(schematic)*.
- **No 5 V boost.** The VIN pad is ≈5 V only with USB plugged in (VUSB through a Schottky), otherwise VBAT *(schematic)*.
- 3V3: TPS7A2633, **500 mA**, 2 µA quiescent, from VIN. Feeds ESP32, expander, RTC, panel PMIC 3.3 V input, microSD, and the easyC connector.
- Deep sleep 18 µA *(product page)*; 20–30 µA with peripherals asleep *(docs)*. Awake, Wi-Fi and refresh currents: not published.
- `readBattery()`: expander P1_1 enables a MOSFET, 100k/100k divider, `analogReadMilliVolts(35) × 2`.

### Deep sleep and wake

- RTC INT → JP2 (default INT) → **GPIO39** with 10 k pull-up *(schematic)*. Library example: `setAlarmEpoch(..., RTC_ALARM_MATCH_DHHMMSS); esp_sleep_enable_ext0_wakeup(GPIO_NUM_39, 0);` — the example carries the comment "GPIO39 is NOT guaranteed for Inkplate 5v2". Matches what `EpdBoardInkplate::enableWakeOnRtcAlarm()` does. **It works on this board** *(measured)*: the validation build sets a 10 s alarm and every wake logs `ESP_SLEEP_WAKEUP_EXT0` on time. Soldered's warning stands for the family, not for this unit.
- Wake button SW3 → GPIO36, active low. Expander INT → GPIO34.
- **easyC 3V3 stays on in deep sleep.** It is the unswitched LDO output the ESP32 itself runs from. Only microSD and RTC rails are switched.
- Free GPIO: expander P1_3–P1_7 on the bottom header; `gpioInit()` sets them OUTPUT LOW. Use `display.expander1.pinMode/digitalWrite(IO_PIN_B3..B7, ...)`. Do not use P0_x.

### Arduino / PlatformIO

- Board define **`ARDUINO_INKPLATE5V2`** (Arduino core `INKPLATE5V2`). Selects `Inkplate5V2Driver.h`, `MULTIPLE_DISPLAY_MODES`, `USES_I2S`.
- No PlatformIO board JSON exists. Community config: `board = esp32dev`, `build_flags = -DARDUINO_INKPLATE5V2 -DBOARD_HAS_PSRAM -mfix-esp32-psram-cache-issue`, `board_build.f_cpu = 240000000L` — the same shape as weather-cal's `platformio.ini`.
- `INKPLATE_1BIT 0`, `INKPLATE_3BIT 1`; `E_INK_WIDTH 1280`, `E_INK_HEIGHT 720`.
- RTC API as used by the kit: `setEpoch`, `getEpoch`, `getRtcData`, `setAlarmEpoch(epoch, match)`, `clearAlarmFlag`. Match modes `_SS`, `_MMSS`, `_HHMMSS`, `_DHHMMSS`, `_WHHMMSS`.
- Do a full update after a run of partial updates *(docs FAQ)*; `setFullUpdateThreshold(n)`.

### Physical *(KiCad PCB, component side, origin top-left, mm)*

- Outline **130.59 × 75.23**, 2.5 mm corner radius, 1.6 mm PCB.
- Mounting: 4 × SMT M3 standoffs at (3.40, 3.40), (127.19, 3.40), (3.40, 71.83), (127.19, 71.83) — pitch **123.79 × 68.43**.
- USB-C (3.00, 60.23) left edge · power button (2.00, 49.23) left · wake button (128.59, 49.23) right · battery JST (28.00, 15.23) · microSD (10.00, 31.23) · **easyC (100.00, 41.23)** · CR2032 (114.00, 41.23) · ESP32 (80.83, 15.80) · panel FPC (27.50, 46.43).
- Header: 1×1 pads on 2.54 mm along the bottom edge (y = 73.73), x = 19.57–111.01: panel group, ESP32 group (GND, 3V3, TXD, RXD, IO12–15, IO34, V_BAT, IO36, IO39), I²C group (GND, 3V3, SDA, SCL), expander group (GND, 3V3, P1_1–P1_7). The pads are 0.8 mm drills, so a header needs round machined pins.
- Panel 124.59 × 69.14 mm centred on the far side; active area 114.56 × 64.44 mm.
- Soldered enclosure: 145.24 × 84.23 × 13.5 mm, sold assembled (€19.95) and published as STL/STEP.

---

## 2. SCD41 — CO₂

Sources: [SCD4x datasheet v1.7](https://sensirion.com/media/documents/48C4B7FB/67FE0194/CD_DS_SCD4x_Datasheet_D1.pdf) ·
[low-power app note](https://sensirion.com/media/documents/077BC86F/62BF01B9/CD_AN_SCD4x_Low_Power_Operation_D1.pdf) ·
[design-in guide](https://sensirion.com/media/documents/0D0C9129/623B1183/Sensirion_CO2_Sensors_SCD4x_design-in_guide.pdf) ·
[Adafruit 5190](https://www.adafruit.com/product/5190) · [learn guide](https://learn.adafruit.com/adafruit-scd-40-and-scd-41) ·
[Sensirion library](https://github.com/Sensirion/arduino-i2c-scd4x) ·
[module STEP](https://sensirion.com/media/documents/260AFF2D/616531AE/Sensirion_CO2_Sensors_SCD4x_STEP_file.step)

### Measures

| | Range | Accuracy | τ63 |
|---|---|---|---|
| CO₂ | 400–5000 ppm (output 0–40 000) | ±(50 ppm + 2.5 %) to 1000; ±(50 + 3 %) to 2000; ±(40 + 5 %) to 5000 | 60 s |
| RH | 0–100 % | ±6 % (15–35 °C) | 90 s |
| T | −10–60 °C | ±0.8 °C (15–35 °C) | 120 s |

Repeatability ±10 ppm. Drift ±(5 ppm + 0.5 %)/year. RH/T specs hold only with the temperature offset set for the enclosure.

### Electrical

- VDD 2.4–5.5 V. **Peak 175 mA typ / 205 mA max at 3.3 V** (115/137 at 5 V), "sustained" during the measurement pulse. Supply ripple must be < 30 mV p-p unloaded; **Sensirion recommends a separate LDO.**
- Average: 15 mA (periodic 5 s), 3.2 mA (low-power periodic 30 s), 0.45 mA (single-shot every 5 min). Idle < 200 µA. Single shot costs 77 mC at 3.3 V.
- I²C 0x62, not changeable. 0–400 kHz. Power-up to idle 30 ms.

### Commands we will use

All words 16-bit MSB-first; each data word followed by CRC-8 (poly 0x31, init 0xFF, no reflect, no final XOR; CRC(0xBEEF) = 0x92).

| Command | Code | Wait | Notes |
|---|---|---|---|
| start_periodic_measurement | 0x21B1 | — | 5 s interval. Only read/data-ready/stop/pressure allowed while running. |
| start_low_power_periodic_measurement | 0x21AC | — | 30 s interval. |
| stop_periodic_measurement | 0x3F86 | 500 ms | |
| measure_single_shot | 0x219D | 5000 ms | Fastest interval 5 s. Datasheet v1.6 dropped the "discard first shot after power-up" note; the 2022 app note still says discard it. |
| read_measurement | 0xEC05 | 1 ms | 9 bytes: CO₂, T, RH words + CRCs. **NACKs if no data** — poll data-ready first. |
| get_data_ready_status | 0xE4B8 | 1 ms | low 11 bits == 0 → not ready |
| set_temperature_offset | 0x241D | 1 ms | word = °C × 65535/175. Default 4 °C. Idle only. |
| set_ambient_pressure | 0xE000 | 1 ms | word = Pa/100, 70 000–120 000 Pa. **Allowed during periodic measurement. Feed the BME688's pressure in.** |
| set_automatic_self_calibration_enabled | 0x2416 | 1 ms | default on |
| perform_forced_recalibration | 0x362F | 400 ms | run ≥ 3 min first, stop, wait 500 ms |
| persist_settings | 0x3615 | 800 ms | EEPROM, ≥ 2000 cycles |
| power_down / wake_up | 0x36E0 / 0x36F6 | 1 / 30 ms | wake_up is never ACKed; verify with get_serial_number |
| get_serial_number | 0x3682 | 1 ms | 48-bit |
| perform_self_test | 0x3639 | 10 000 ms | word 0 → OK |

T = −45 + 175 × word/65535; RH = 100 × word/65535.

### Operating mode for this device (mains)

Run **periodic measurement (5 s)**, or low-power periodic (30 s) if 15 mA average matters. ASC works in both and needs ≥ 3 min of ~400 ppm fresh air weekly. Set `set_ambient_pressure` from the BME688 each cycle. Determine the temperature offset in the finished enclosure after 15 min of thermal equilibrium: `offset_new = T_scd − T_shtc3 + offset_prev`. ASC is **not** available in power-cycled single-shot mode.

### Gotchas

- Self-heating: the default 4 °C offset is a guess; measure it in situ. Design-in guide sanity check: > 0.5 °C from the reference after 15 min, or > 20 ppm between consecutive readings, means the design-in is poor.
- Placement: large opening near the sensor, small dead volume, away from CPU, display, Wi-Fi, regulators, battery; lowest part of the device; out of sunlight and vibration.
- Do not touch or wet the white membrane.
- Settings are RAM-only until `persist_settings`.

### Library

`Sensirion I2C SCD4x` (class `SensirionI2cScd4x`, `begin(Wire, 0x62)`): `startPeriodicMeasurement()`, `getDataReadyStatus()`, `readMeasurement(co2, T, RH)`, `setAmbientPressure(Pa)`, `setTemperatureOffset()`, `persistSettings()`.

### Adafruit 5190 board

- 25.4 × 22.86 mm. Four 3.0 mm holes at (2.54, 2.54), (22.86, 2.54), (2.54, 20.32), (22.86, 20.32) — pitch 20.32 × 17.78.
- Two STEMMA QT connectors, one per side edge, plus a 5-pin header (VIN, 3Vo, GND, SCL, SDA).
- VIN 3–5 V; AP2112K regulator; BSS138 level shifter; **10 kΩ pull-ups on SDA/SCL, no jumper to disable**. Sensor is powered straight from VIN by default ("Sensor Power" jumper). Rev A silkscreen for the two back jumpers is reversed.

---

## 3. PMSA003I — particulates

Sources: [Plantower PMSA003I manual V2.6](https://cdn-shop.adafruit.com/product-files/4632/4505_PMSA003I_series_data_manual_English_V2.6.pdf) ·
[Adafruit 4632](https://www.adafruit.com/product/4632) · [learn guide](https://learn.adafruit.com/pmsa003i) ·
[schematic](https://cdn-learn.adafruit.com/assets/assets/000/092/990/original/sensors_PMSA300I_sch.png) ·
[Eagle files](https://github.com/adafruit/Adafruit-PMSA003I-PCB) ·
[Adafruit_PM25AQI](https://github.com/adafruit/Adafruit_PM25AQI) ·
[AP3602A charge pump](https://cdn-shop.adafruit.com/product-files/3661/AP3602A_B.pdf)

### Measures

- PM1.0 / PM2.5 / PM10 in µg/m³, two flavours: "CF=1, standard particle" (factory) and "atmospheric environment". Use the **atmospheric** ("env") values for indoor readings; the library's AQI uses them.
- Particle counts per 0.1 L for > 0.3 / 0.5 / 1.0 / 2.5 / 5.0 / 10 µm.
- Range 0–500 µg/m³ effective, ≥ 1000 max. Resolution 1 µg/m³. Consistency ±10 % (100–500) / ±10 µg/m³ (0–100). Counting efficiency 50 % @ 0.3 µm, 98 % @ ≥ 0.5 µm.
- Internal update every 2.3 s (stable) to 200–800 ms (fast). Total response ≤ 10 s.

### Electrical — the 5 V question

- Module: **DC 5.0 V (4.5–5.5)**, "needed because the FAN should be driven by 5V". Data pins are 3.3 V logic (L < 0.8 V, H > 2.7 V). Active ≤ 100 mA, standby ≤ 200 µA.
- Adafruit board: **makes its own 5 V** with an AP3602A charge pump from VIN 3–5 V, so it runs from a 3.3 V Qwiic chain. AP3602A: 100 mA continuous, 250 mA for 100 ms, input current ≈ 2 × output → **~200 mA from 3.3 V while the fan runs** *(derived)*.
- Board also has an AP2112K 3.3 V LDO (pull-ups, LED, level shifter) and a BSS138 level shifter. **10 kΩ pull-ups on both sides of the shifter; the connector side is pulled to VIN.** ⇒ a 5 V VIN pulls the shared bus to 5 V, past the SCD41's VDD + 0.3 V absolute maximum. **Keep VIN at 3.3 V**, though the module itself wants 5 V: the charge pump makes that.
- I²C **0x12**, fixed. 100 kHz-class timing. No UART on this variant (pins 6 and 8 NC).

### Interface

One plain 32-byte I²C read, big-endian words:

| Bytes | Field |
|---|---|
| 0–1 | 0x42 0x4D start |
| 2–3 | frame length = 28 |
| 4–9 | PM1.0 / PM2.5 / PM10, CF=1 |
| 10–15 | PM1.0 / PM2.5 / PM10, atmospheric |
| 16–27 | counts > 0.3 / 0.5 / 1.0 / 2.5 / 5.0 / 10 µm per 0.1 L |
| 28 | version |
| 29 | error code |
| 30–31 | checksum = sum of bytes 0–29 |

The sensor updates its registers itself; the host polls. **No I²C commands** for sleep/wake or passive mode. Fan control is the **SET pin** (high = run, low = sleep ≤ 200 µA; on the breakout SET low also shuts the charge pump). RST low resets. Both have 100 k pull-ups on the breakout; drive from a GPIO.

### Warm-up

- **≥ 30 s after wake** for stable data (fan spin-up). Library waits 3 s after power before `begin_I2C()`.
- Intermittent use reported to read high; 2–3 min to settle *(unverified, PMSA003 UART sibling)*.
- Endurance test: SET toggled at 0.5 Hz for 72 h — frequent duty-cycling is within spec.

### Operating mode for this device (mains)

The fan runs for the 35 s before each reading and stops after it: Plantower's 30 s warm-up and a margin. Each reading records how long the fan had run (`pm_warmup_s`), so the stored readings can show whether that is enough given the field reports above. SET is optional: the breakout's 100 k pull-up holds it high, so with no wire the fan runs from power-on and all the time. Wired to the TinyS3's J4 pin 7 (§8), it lets the firmware stop and start the fan.

### Gotchas

- Metal shell is GND. Inlet/outlet against the enclosure wall, or a baffle between them; enclosure vent ≥ inlet size; ≥ 20 cm above the floor; not in an air purifier's flow; indoor only; kitchen/bathroom mist needs protection.
- Overreads above ~80 % RH *(studies, unverified)*.
- Module screw holes Ø1.7 mm, thread depth max 3.4 / 1.9 mm.

### Library

`Adafruit_PM25AQI`: `begin_I2C(&Wire)`; `read(&data)` does the 32-byte read and checksum, returns false on a bad frame — retry. Fields `pm25_env`, `pm100_env`, `particles_03um` … plus US/China AQI.

### Adafruit 4632 board

- **35.56 × 50.80 mm**, 13.6 mm tall with the module, 28 g.
- Holes 2.5 mm at (2.54, 2.54), (33.02, 2.54), (2.754, 48.3), (32.754, 15.3).
- Two STEMMA QT connectors on the left/right edges near the bottom (y = 8.89). 7-pin header along the bottom: VIN, 3Vo, GND, SCL, SDA, RST, SET.
- Module 38 × 35 × 12 mm sits on top; fan face away from the PCB; inlet slots on the 12 mm side faces.

---

## 4. BME688 — VOC / gas, pressure

Sources: [Bosch datasheet rev 1.3](https://www.bosch-sensortec.com/media/boschsensortec/downloads/datasheets/bst-bme688-ds000.pdf) ·
[BSEC software](https://www.bosch-sensortec.com/software-tools/software/bme688-and-bme690-software/) ·
[BSEC2 Arduino](https://github.com/boschsensortec/Bosch-BSEC2-Library) ·
[BME68x API](https://github.com/boschsensortec/BME68x_SensorAPI) ·
[Soldered 333203](https://soldered.com/products/bme688-environmental-sensor) · [docs](https://docs.soldered.com/bme688/hardware/) ·
[Soldered library](https://github.com/SolderedElectronics/Soldered-BME688-Sensor-Arduino-Library)

### Measures

- **Gas resistance (Ω)** from a heated metal-oxide layer: lower = more reducing VOCs. Also moved by humidity. Sums VOCs; blind to CO₂.
- With **BSEC** (closed-source Bosch binary): IAQ 0–500 (auto-trimmed to recent history; ~50 good, ~200 polluted), **static IAQ** (recommended for a stationary device), CO₂-equivalent, breath-VOC-equivalent, accuracy 0–3.
- Pressure 300–1100 hPa, ±0.6 hPa absolute, ±0.12 relative. Humidity ±3 % (20–80 %). Temperature ±0.5 °C **"typically above ambient"** — self-heating, see below.
- BME688 over BME680: gas-scanner mode (10-step heater profile, AI-Studio classification). Not needed here.

### Electrical

- VDD 1.71–3.6 V, optimised for 1.8 V (the Soldered board runs it at 3.3 V; heat scales with supply).
- Sleep 0.15 µA. Forced T/P/H ~3.7 µA at 1 Hz. **Heater 12 mA typ, 17 mA peak.** BSEC averages: ULP 0.09 mA, LP 0.9 mA.
- I²C **0x76** (SDO low) default on Soldered; JP1 → 0x77. Up to 3.4 MHz.
- Soldered board: onboard regulator, VCC 3.3–5 V; JP3 regulator enable (NC); JP2 (NO) is not a bypass: Soldered's docs say "when connected, the voltage regulator is powered by 5V". What JP2 joins is unverified, because no schematic is published; check it with a meter before bridging it. **JP5 (NC) 3.3 V pull-ups, JP4 (NC) 5 V pull-ups — cut to disable.** 10 k, from the `103` marking on the board.

### Interface (forced mode, the sequence we need)

Chip ID 0xD0 = 0x61; variant 0xF0 = 0x01. Set osrs_h (0x72), then osrs_t/osrs_p (0x74), gas_wait_0 (0x64, e.g. 100 ms), res_heat_0 (0x5A, computed from calibration), run_gas (0x71 bit 5), then mode = forced (0x74 bits 1:0). Poll new_data (0x1D bit 7). Read P 0x1F–21, T 0x22–24, H 0x25–26, gas 0x2C–2D with **gas_valid (bit 5) and heat_stab (bit 4)** — both must be set. Heater reaches target in 20–30 ms; typical indoor profile **300–320 °C for 100–150 ms**. Rely on the Bosch API for compensation maths.

### BSEC on ESP32

- Runs on ESP32 Arduino (`boschsensortec/bsec2` on PlatformIO, precompiled `libalgobsec`). ROM ~37 kB, RAM ~4 kB. Clickthrough licence.
- Sample rates: **LP 3 s** (0.9 mA) or **ULP 300 s** (0.09 mA). Calibration: accuracy 0 for ~5 min (LP) / ~20 min (ULP), then hours to reach 3; needs both clean and polluted air exposure.
- **State blob 238 bytes** must be saved and restored or calibration restarts. Config blob (~1.9 kB, pick the 3.3 V / 3 s or 300 s / 4 d or 28 d variant) is re-applied each boot. BSEC needs a monotonic clock (`Bsec2::begin` takes a millis function).
- Mains-powered and always awake, LP mode with the state kept in RAM and checkpointed to NVS every few hours is the well-trodden path. Deep-sleep BSEC setups are where the forum failures live.
- The firmware links BSEC2 1.10.2610's `libalgobsec` without Bosch's Arduino wrapper, whose sources need a second copy of the BME68x API; `scripts/bsec.py` adds the headers, the config blobs and the binary. It uses `bme688_sel_33v_3s_4d`, subscribes to the IAQ outputs and to raw pressure at the LP rate, and runs in a FreeRTOS task of its own. Without an output that needs pressure, BSEC asks for no pressure conversion, the BME688 skips it, and the reading comes out near 659 hPa. The Arduino package has no BME688 configuration named for IAQ, but `sel` gives an index from the first sample and reached accuracy 1 in about 4 minutes and 3 in about 40 *(bench)*. Restarted from the state in NVS, it is back at accuracy 3 within 3 minutes *(bench)*.
- BSEC's header gives its pressure input in Pa, but Bosch's own BSEC2 wrapper passes hPa, and so does the firmware. BSEC took 1019 hPa without an error and kept giving an index *(bench)*.

### Self-heating

Die runs above ambient; heater 200–400 °C after the T/P/H read. Bosch offsets 1.33 °C (LP) / 0.47 °C (ULP); users report 1–3 °C. **Use the SHTC3 for T/RH; treat BME688 T/RH as BSEC-internal.**

### Library

Bosch `BME68x Sensor library` (`setTPH(2x,16x,1x)`, `setHeaterProf(300,100)`, `setOpMode(FORCED)`, `fetchData`, `getData`) plus `Bosch-BSEC2-Library` for IAQ. Soldered's library is a thin GPL wrapper of the Bosch one, `begin(0x76)`, no BSEC. Adafruit_BME680 also drives it (default 0x77 — pass 0x76).

### Soldered 333203 board

- **38.0 × 22.0 mm** *(measured)*, four M3 (3.2 mm) corner holes, 1.5 mm header holes. Two easyC connectors, one per short edge; 4-pin header GND/VCC/SDA/SCL on the long edge. Sensor near centre.
- No public hardware repo: Soldered's docs call it "not available yet" and send the files on request.

---

## 5. SHTC3 — temperature and humidity

Sources: [SHTC3 datasheet v4](https://sensirion.com/media/documents/643F9C8E/63A5A436/Datasheet_SHTC3.pdf) ·
[low-power app note](https://sensirion.com/media/documents/00887EF5/6164030A/Sensirion_AppNotes_Humidity_Sensors_SHTC3_Low_Power_Measurement_Mode.pdf) ·
[SHTxx design guide](https://media.digikey.com/pdf/Data%20Sheets/Sensirion%20PDFs/HT_AN_SHTxx_STSxx_Design%20Guide_V1.1_D1.pdf) ·
[Soldered 333032](https://soldered.com/products/temperature-and-humidity-sensor-shtc3-breakout) · [docs](https://docs.soldered.com/shtc3/hardware/) ·
[Adafruit_SHTC3](https://github.com/adafruit/Adafruit_SHTC3) · [Soldered library](https://github.com/SolderedElectronics/Soldered-SHTC3-Temperature-Humidity-Sensor-Arduino-Library)

### Measures (normal mode)

| | Range | Typ accuracy | Max | τ63 | Drift |
|---|---|---|---|---|---|
| RH | 0–100 % | ±2 % (20–80 %, 25 °C) | ±3.5 % | 8 s | < 0.25 %/yr |
| T | −40–125 °C | **±0.2 °C** (5–60 °C) | ±0.4 °C | 5–30 s | < 0.02 °C/yr |

Recommended operating range 5–60 °C, 20–80 % RH; long exposure > 80 % gives a temporary offset that self-recovers.

### Electrical

- VDD 1.62–3.6 V. Sleep **0.3 µA**, idle 45 µA, measuring 430 µA (normal) / 270 µA (low-power). 15.4 µJ per normal reading.
- I²C **0x70, fixed**. Up to 1 MHz. Clock stretching supported; prefer the no-stretch commands on ESP32.
- Soldered board: regulator, VCC 3.3–5 V; **JP2 (NC) 3.3 V pull-ups, JP1 (NC) 5 V pull-ups — cut to disable.** 10 kΩ, from the `103` marking on the board. Level shifter between the header and the easyC side. JP3 (NC) feeds the regulator and JP4 (NO) bypasses it; Soldered's docs say "Ensure JP3 is disconnected if JP4 is connected". The component side carries JP1–JP4 and no JP5.

### Commands

| | Code |
|---|---|
| Wakeup | 0x3517 |
| Sleep | 0xB098 |
| Soft reset | 0x805D |
| Read ID | 0xEFC8 (ID & 0x083F == 0x0807) |
| **Normal, no stretch, T first** | **0x7866** |
| Normal, stretch, T first | 0x7CA2 |
| Low-power, no stretch, T first | 0x609C |

Sequence from sleep: wakeup → ≥ 240 µs → measure → ≥ 12.1 ms (0.8 ms low-power) → read 6 bytes (T MSB, LSB, CRC, RH MSB, LSB, CRC) → sleep. ~13 ms total. CRC-8 poly 0x31 init 0xFF. T = −45 + 175 × S/2¹⁶; RH = 100 × S/2¹⁶. First reading after wakeup is valid.

**Trap:** the Soldered library's `sample()` defaults to **low-power mode** (±0.8 °C). Use `sample(SHTC3_READ)` or Adafruit_SHTC3, which defaults to normal mode and sleeps the part after each read.

### Placement (Sensirion design guide)

"External heat sources close to the sensor will cause increased temperature (and thus decreased RH) readings" — 1 °C error ≈ 5 % RH at 90 %. Conduction from "power electronics, microprocessors, displays" is the most common cause. Put it at the enclosure edge or corner, with airflow across it, isolated from the board by slits, shielded from heated air, out of sunlight. The Soldered board already has the sensor on a slotted thermal island. No polyamide near it; at most one membrane per aperture.

### Soldered 333032 board

- **38.0 × 22.0 mm** *(measured)*, 2 mm corner radius, four Ø3.2 mm (M3) holes inset 3.05 mm on a 32 × 16 mm pitch. Soldered's product page and docs give 22 × 22 mm with two holes, which does not match the board. Two easyC connectors on the short ends; unpopulated 4-pin header on one long edge.
- No public hardware repo: Soldered's docs call it "not available yet" and send the files on request.

---

## 6. The I²C bus

Sources: [NXP UM10204](https://www.nxp.com/docs/en/user-guide/UM10204.pdf) ·
[SparkFun Qwiic](https://www.sparkfun.com/qwiic) · [Adafruit STEMMA QT](https://learn.adafruit.com/introducing-adafruit-stemma-qt/technical-specs) ·
[Soldered Qwiic/easyC](https://docs.soldered.com/qwiic/) · [JST SH](https://www.jst-mfg.com/product/detail_e.php?series=231)

### Connectors

easyC, Qwiic and STEMMA QT are all **JST SH 1.0 mm 4-pin, same order: black GND, red 3V3, blue SDA, yellow SCL**. A stock cable chains a Soldered board to an Adafruit board. Every sensor board here has two connectors in parallel (pass-through); the Inkplate has one. Cable 28 AWG; SparkFun's conservative cable limit **226 mA**, JST contact rating 1 A. The 226 mA is a bundled, long-run derating for 28 AWG — a single short conductor in free air is good to ~1 A, which is also the contact limit. §8's cable 1 carries the whole chain's ground return, up to ~470 mA at peak, on that basis; it is the most heavily loaded Qwiic conductor in the build and the reason the second return (step 9) exists. STEMMA (non-QT, JST PH 2 mm) is a different thing.

### Addresses

0x12 PMSA003I · 0x62 SCD41 · 0x70 SHTC3 · 0x76 BME688 · plus 0x20 / 0x48 / 0x51 on the Inkplate. **No conflicts.**

### Pull-ups

| Where | Value | Removable? |
|---|---|---|
| TinyS3 host | none *(unverified: the board has no Qwiic socket and its schematic shows no pull-ups)* | — |
| Adafruit SCD41 | 10 k | no jumper |
| Adafruit PMSA003I | 10 k (connector side) | no jumper |
| Soldered BME688 | 10 k *(marked 103)* | JP5 |
| Soldered SHTC3 | 10 k *(marked 103)* | JP2 |

Parallel total **2.5 kΩ** per line; sink 1.3 mA at 3.3 V. Spec minimum 967 Ω (3 mA sink) — **within spec**. At 100 kHz the rise-time budget is comfortable. At 400 kHz, 2.5 kΩ allows only ~140 pF of bus, marginal with four cables. Recommendation: **stay at 100 kHz and cut nothing.** Cutting JP5 (BME688) and JP2 (SHTC3) would give 5 kΩ, which buys headroom only at 400 kHz.

### Length

400 pF bus limit; ~40–100 pF per metre of cable *(unverified)* plus ~10 pF per device pin. Four cables of 50–200 mm keep the chain under 0.8 m — fine.

---

## 7. Power

One 5 V rail enters the dock at its USB-C socket and feeds three loads. A 5 V / 2 A adaptor covers them.

| Load | Typical | Peak | Fed by |
|---|---|---|---|
| Head: Inkplate, no sensors | ≤ 170 mA *(measured: 162 mA mean was Inkplate **plus** sensors at 4.2 V)* | 525 mA for 10 ms per refresh; 1.66 A sub-millisecond at power-on *(measured)* | the pogo connector, into the VIN pads |
| Sensors, through the AMS1117 | ~215 mA | ~470 mA | the regulator's 3.3 V |
| TinyS3, awake with Wi-Fi | ~100 mA *(typical ESP32-S3 figure, not measured)* | ~350 mA TX bursts | its 5V header pin |
| **Total** | **~500 mA** | **~1.3 A** | |

### Budget on the sensors' 3.3 V rail

| Load | Typical | Peak |
|---|---|---|
| PMSA003I via its charge pump, fan running | ~200 mA *(derived)* | 250 mA / 100 ms |
| SCD41, periodic 5 s | 15 mA | **175–205 mA** during each measurement |
| BME688, BSEC LP | 0.9 mA | 17 mA |
| SHTC3 | 0.4 mA | 0.9 mA |
| **Total** | **~215 mA** | **~470 mA** |

### Why the sensors have a regulator of their own

The sensors run from an **AMS1117-3.3 module**, 800 mA maximum and about 1.1 V of dropout, fed straight from the
dock's 5 V. Neither processor board's own regulator carries them:

- **The Inkplate's TPS7A2633 is 500 mA** and must also carry the ESP32 and the panel PMIC. Sensor peaks plus a
  Wi-Fi burst exceed it, and the SCD41 wants a quiet supply: Sensirion asks for < 30 mV of ripple and recommends
  a regulator of its own.
- **The TinyS3's NCP167 is a 1 × 1 mm XDFN4** with 198 °C/W junction-to-air and thermal shutdown at 160 °C
  *(datasheet)*. On the dock's 5 V it would rise +60 °C at the sensors' typical load and +130 °C at their peak,
  which is the shutdown threshold. It carries the TinyS3 alone.

SparkFun's guidance for a high-current Qwiic chain is the same: inject power from a separate supply and cut the
chain's 3V3 wire, which is what cable 1 does (§8).

### Heat in the dock

| Source | Dissipation | Note |
|---|---|---|
| TinyS3, awake with Wi-Fi | ~0.5 W | ~100 mA at 5 V. The dock's largest heater. |
| AMS1117 | 0.37 W at 215 mA, ~0.2 W at 120 mA | 1.7 V dropped. A SOT-223 on the module's copper runs ~70 °C/W, so the tab sits 25–30 °C above the room, about 55 °C. Rated 125 °C. |
| PMSA003I | ≤ 0.5 W | vents straight out through the left wall |
| Sensors | < 0.1 W | |

There is no fan. Under a watt in a vented dock lifts the air near the parts by a degree or two and the far corner
by nothing. A fan would blow over the SHTC3, stir the SCD41's compartment and pull the BME688's heater about, so
both heaters instead sit on the PM side, as far from the SHTC3 as the layout allows.

---

## 8. Wiring

### Circuit

```
 USB-C socket (dock, rear wall)
    │
    ├─ VBUS ─┬─ splice ─┬─────────► TinyS3 5V        J3 pin 3
    │        │          ├─────────► AMS1117 IN
    │        │          └─────────► pogo, two contacts ──► Inkplate VIN pads   5 V for the head
    │        │                      AMS1117 OUT ─────────► PMSA003I header VIN   3.3 V for the whole chain
    │        │
    └─ GND ──┴─ splice ─┬─────────► TinyS3 GND       J3 pin 2
                        ├─────────► AMS1117 GND
                        ├─────────► pogo, two contacts ──► Inkplate GND pad
                        └─────────► status LED, through its resistor

 TinyS3
    ├─ J4 pins 5, 6, 10 ── cable 1: SCL · SDA · GND ─────► PMSA003I header SCL · SDA · GND   bus in, chain's ground return out
    ├─ J4 pin 7 ─────────────────────────────────────────► PMSA003I header SET   fan control
    └─ J4 pin 8 (IO6) ── 1 kΩ ───────────────────────────► status LED

   ┌─ PMSA003I  (Adafruit 4632)   0x12   heaviest load first: power enters at its header, ground leaves by cable 1
   │     cable 2: stock, from socket B
   │     ▼
   ├─ SCD41     (Adafruit 5190)   0x62   second heaviest; gets BME688 pressure each cycle
   │     cable 3: stock
   │     ▼
   ├─ BME688    (Soldered)        0x76   JP1 moves it to 0x77 if 0x76 is ever taken
   │     cable 4: stock
   │     ▼
   └─ SHTC3     (Soldered)        0x70   LAST — at the enclosure edge, upstream of the fan,
                                         away from the heater and the TinyS3. Second socket unused.
```

### What connects to what

| # | From | To | Wire |
|---|---|---|---|
| 1 | USB-C socket **V pad** | VBUS splice | 28 AWG, soldered |
| 2 | USB-C socket **G pad** | GND splice | 28 AWG, soldered |
| 3 | VBUS splice | TinyS3 **5V**, J3 pin 3 | 28 AWG, soldered to the leg |
| 4 | GND splice | TinyS3 **GND**, J3 pin 2 | 28 AWG, soldered to the leg |
| 5 | VBUS splice | AMS1117 **IN** | 28 AWG, Dupont at the AMS1117 |
| 6 | GND splice | AMS1117 **GND** | 28 AWG, Dupont at the AMS1117 |
| 7 | VBUS splice | pogo female, two contacts | 28 AWG, soldered; a bare bridge joins the pair |
| 8 | GND splice | pogo female, two contacts | 28 AWG, soldered; a bare bridge joins the pair |
| 9 | AMS1117 **OUT** | PMSA003I header **VIN** | 28 AWG, Dupont both ends |
| 10 | TinyS3 **J4 pins 5, 6, 10** | PMSA003I header **SCL, SDA, GND** | cable 1: a Qwiic cable with its plug kept at the PM end, the other end cut and soldered to the legs; **3V3 conductor removed** |
| 11 | TinyS3 **J4 pin 7** | PMSA003I header **SET** | 28 AWG, Dupont at the header |
| 12 | TinyS3 **J4 pin 8 (IO6)** | status LED, through a 1 kΩ resistor | 28 AWG, the resistor spliced in |
| 13 | GND splice | status LED, other leg | 28 AWG |
| 14 | PMSA003I **easyC socket B** | SCD41 either socket | cable 2: stock Qwiic |
| 15 | SCD41 other socket | BME688 either socket | cable 3: stock Qwiic |
| 16 | BME688 other socket | SHTC3 either socket | cable 4: stock Qwiic |
| 17 | pogo male, two contacts each net | Inkplate **VIN pad** and **GND pad** | 28 AWG, soldered to the 4 × 4 mm pads above the reset button |

Every sensor board has two easyC sockets wired in parallel, so "either" is literal. The SHTC3 is last, so one of
its sockets stays empty. The PM board's 7-pin header is VIN, 3Vo, GND, SCL, SDA, RST, SET: rows 9, 10 and 11 use
**VIN, GND, SCL, SDA and SET**, and 3Vo and RST stay empty. Cable 1 lands on that header, not on a socket: socket
B carries cable 2, and in the enclosure socket A faces a wall.

The [enclosure README](../hardware/README.md) has the routing: which lane each wire takes, and where the splices
and the resistor sit.

**One wire per joint.** Every pad, leg and Dupont crimp takes a single wire. Where one net feeds several places,
the wires are twisted, soldered end to end and covered with heat-shrink — the two splices in the middle of the
dock's wiring channel. The exceptions are the pogo's bare bridges, which are soldered across a pair of tails in
one go.

**5 V on the Inkplate's VIN pads** is Soldered's own answer for this circuit
([forum thread 1934](https://community.soldered.com/t/externally-powering-the-inkplate-5v2-with-5v/1934)). The
5 V reaches the charger's output through the source-select transistor; Soldered say that is harmless, and the
board's own USB-C is blocked by the dock's side wall while the head is docked.

**The SET wire is optional.** The PM breakout pulls SET high through 100 kΩ (§3), so without it the fan runs from
power-on and every reading is valid. With it, the firmware stops the fan between readings and the 30 s warm-up
counts from when it starts.

**Cable 1** keeps its JST-SH plug at the PM end only. Cut the other plug off, strip GND, SDA and SCL, and solder
each to its TinyS3 leg. The 3V3 conductor is cut back and insulated: leave it in and the chain is fed by both the
AMS1117 and the TinyS3's own regulator at once, which is the fault this section exists to avoid. On a standard
cable 3V3 is the **red** wire (black GND, red 3V3, blue SDA, yellow SCL); on a cable with other colours, find it
by position against the socket's silkscreen, or with a meter, before cutting.

### Ground

The chain has **one ground return**, cable 1's GND conductor. At worst the whole chain returns under 300 mA (the
PM fan about 100 mA, an SCD41 burst about 200 mA) through 28 AWG, which is a few millivolts of shift — below
anything I²C notices. The AMS1117's own GND wire carries only the regulator's few mA, and the head's ground
crosses the pogo on its own pair of contacts.

### Current in each wire

| Wire | typ / peak | Carrier | Margin |
|---|---|---|---|
| 1, 2 · socket to the splices | ~500 mA / ~1.3 A | 28 AWG, soldered | fine — 28 AWG is ~1.4 A in free air; the 1.3 A peak is sub-millisecond |
| 7, 8, 17 · the head's supply | ≤ 170 mA / 1.66 A | 28 AWG over two pogo contacts per net | fine — the pair is rated 1 A *(assumed: the connector is rated 1 A, per pin unstated)*; the spike is sub-millisecond |
| 5, 9 · the sensors' supply | 215 / 470 mA | 28 AWG, Dupont | fine — Dupont ≥ 1 A |
| 10 · cable 1 GND (chain return) | 215 / 470 mA | 28 AWG, JST-SH 1 A/contact | fine |
| 3, 4 · the TinyS3's supply | ~100 / ~350 mA | 28 AWG | fine |
| 11, 12, 13 · SET, IO6, the LED | < 2 mA | — | — |
| 14 · PM → SCD41 | 16 / 225 mA | 28 AWG, JST-SH | fine |
| 15, 16 · onward | 1.3 / 18 mA · 0.4 / 0.9 mA | — | — |

Ampacity is not the constraint anywhere; a Dupont jumper only *looks* heavier than a Qwiic conductor because its
insulation is thicker — the copper is the same 28 AWG.

**Voltage drop is mostly contacts.** The SCD41's own 175 mA measurement pulse goes out AMS OUT → PM header →
socket B → cable 2 → SCD41 and returns the same way to cable 1. Over runs of a few centimetres the copper is a
few tens of mΩ; the crimp and plug contacts at 10–20 mΩ each are what add up, to roughly 130–210 mΩ, or
**25–35 mV** at the sensor during its pulse. That is a ripple figure, not an operating limit — the part runs from
2.4–5.5 V — so it is margin, not a fault, and clean crimps matter more than cable length.

Chain order is chosen for **cable voltage drop** (heavy loads nearest the injection point) and **heat**
(the reference sensor farthest from everything warm).

### Bench bring-up on one board

Every sensor runs at 3.3 V on an ordinary Qwiic cable, so for bring-up the whole chain can hang off any 3.3 V
I²C host, the Inkplate's easyC socket included, with nothing to change on any board. What that arrangement cannot
do is run: the host's rail cannot carry the sensor peaks on top of its own processor and Wi-Fi bursts, and ~200 mA
for the PM board would cross every upstream board's connectors. The symptom is an intermittent brown-out when the
fan, an SCD41 measurement peak and a Wi-Fi transmit coincide, which is the hardest kind of fault to find later.

---

## 9. The enclosure

The desk enclosure is in [`hardware/`](../hardware/README.md): where each board
sits and why, the fasteners, the cable routing, the head-to-dock pogo connector, and the 3D models it is
built from. The placement rules it follows come from each part's section here: §2 (SCD41), §3 (PMSA003I),
§4 (BME688) and §5 (SHTC3).

---

## 10. Open questions

1. **PMSA003I input current at 3.3 V** is derived from the charge-pump datasheet, not measured. Measure; it sets the regulator's rating.
2. **TinyS3 awake current** is a typical ESP32-S3 figure. Measure the dock alone on the Power Profiler once it runs.
3. **5 V on the Inkplate's VIN pads**, on the bench, with no battery connected: measure VIN and the battery connector, and check that the charger chip stays cool through a few refreshes. Soldered say the path is harmless (§8); this confirms it on this board.
4. **Pull-ups on the TinyS3's bus.** §6 assumes the board adds none. Measure SDA and SCL to 3.3 V with the sensors unplugged.
5. **What the BME688 board's JP2 joins** (§4). Soldered's docs say only that it powers the regulator from 5 V, and no schematic is public. A continuity check across JP2, or the hardware files Soldered sends on request, would settle it.
6. **Pogo contact resistance.** The connector's listing gives none, so §8 assumes 30–100 mΩ. Measure across a mated pair with ~200 mA flowing.
7. **Flash size** of the Inkplate's ESP32-WROVER-E: 4, 8 or 16 MB by variant, and the module's shield prints no suffix. `esptool.py flash_id` over USB settles it; it resets the board.

---

## Decision Log

Dated findings and decisions behind the text above, oldest first.

- **2026-09-03**: distilled from the datasheets.
- **2026-09-03**: the first wiring plan chained Inkplate → BME688 → SHTC3 → SCD41 → PMSA003I and fed all four from the Inkplate's 3V3 through the chain. Order, connectors, addresses and pull-ups were fine. Power was not: the Inkplate's 500 mA LDO also carries the ESP32, the SCD41 wants a quiet supply, and the two heavy loads sat at the far end, where the drop is worst. Nor was the SHTC3's place: the reference sat between the BME688's heater and the SCD41. The PM fan's SET pin was unused. §8's circuit replaced the plan.
- **2026-09-09**: the RTC alarm wakes this board on GPIO39, though Soldered does not guarantee it on the 5 Gen2. `pio run -e esp32-validate` sleeps 10 s on the alarm and wakes on `ESP_SLEEP_WAKEUP_EXT0` every cycle; an ESP32 timer armed at 15 s as a backstop has never had to fire.
- **2026-09-09**: the SCD41 board is the Adafruit 5190. Soldered sells no SCD41; their CO₂ board is the SCD43.
- **2026-09-10**: the Soldered BME688 and SHTC3 boards carry `103` resistors beside their pull-up jumpers, so 10 kΩ, and the §6 total of 2.0 kΩ stands.
- **2026-09-12**: on the bench, BSEC with `bme688_sel_33v_3s_4d` reached accuracy 1 in about 4 minutes and 3 in about 40, and took 1019 hPa as its pressure input without an error.
- **2026-09-12**: with calipers, the Soldered SHTC3 and BME688 boards are both 38.0 × 22.0 mm with four Ø3.2 mm holes on a 32 × 16 mm pitch. For the SHTC3 this overrides Soldered's product page and docs, which give 22 × 22 mm and two holes.
- **2026-09-13**: on the bench, BSEC restarted from the state in NVS was back at accuracy 3 within 3 minutes.
- **2026-09-13**: the wiring became one wire per crimp, with ground starred at the Inkplate and cable 1 landing on the PM header. The draft before it chained ground Inkplate → AMS1117 → PM, which put two wires on the regulator's one GND pin.
- **2026-09-14**: Soldered's pages checked again. Neither Soldered sensor board has a public hardware repo, their docs describe the BME688's JP2 only as feeding the regulator from 5 V, and the Inkplate's BOM names its module only as "ESP32-WROVER", so the PSRAM size stays unverified.
- **2026-09-14**: the head-to-dock pogo connector is rated 1 A, with no per-pin figure and no contact resistance. §8 takes 1 A per pin and assumes 30–100 mΩ per contact.
- **2026-09-14**: the module is an ESP32-WROVER-E; its shield prints the name but no variant suffix. The board's Diagnostics report shows 4.0 MB of PSRAM, which rules out the 2 MB variants, so it carries 8 MB. The flash stays 4, 8 or 16 MB.
- **2026-09-15**: the sensors moved off the Inkplate onto a dock of their own, after the full chain jammed the I²C bus on the Inkplate's rail while each board alone was healthy. One bus carried the panel, the expander, the RTC and the chain, and one 500 mA rail carried the ESP32 and the chain; splitting the device gives each half its own bus and its own regulator.
- **2026-09-15**: the TinyS3 runs the sensors, with the AMS1117 for their 3.3 V. Its own NCP167 cannot carry the chain: 198 °C/W in a 1 × 1 mm package is +60 °C at the typical load and +130 °C at the peak, which is thermal shutdown. A ProS3, whose second regulator could be switched off, was the alternative; it would have put the SCD41 back on the processor's rail beside the Wi-Fi bursts, which is the fault this design exists to avoid. A 40 mAh cell in the head was ruled out: the Inkplate charges at ~400 mA (10 C) and draws 2.5–40 C from it.
- **2026-09-15**: no fan in the dock. Under a watt of dissipation does not need one, and moving air would disturb the SHTC3, the SCD41's compartment and the BME688's heater.
- **2026-09-17**: the head takes 5 V at its VIN pads, on Soldered's own advice for this circuit (forum thread 1934). The alternatives were the 0.8 mm VUSB test pad, too small to solder safely, and the battery connector, which is limited to 4.2 V. A Schottky against back-feed was dropped: the dock's side wall covers the head's USB-C socket while it is docked, so nothing can feed it from a computer.
- **2026-09-17**: the chain keeps one ground return, cable 1's GND conductor. A second return existed when seven loose wires crossed the pogo joint; with the sensors in the dock the whole chain returns under 300 mA through 28 AWG, a few millivolts.
- **2026-09-18**: the right-angle pins on the TinyS3's battery pads are not a fit constraint, so nothing in the enclosure accounts for them. They hang in the 2.5 mm between the board's underside and the tops of the female header strips, where the only things that can meet them are wires and resistors. Both flex, so neither stops the board seating. If the pins ever do get in the way, they come off the board.

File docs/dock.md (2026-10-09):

# The dock

How the dock's firmware works: its loop, its clock, the readings queue, and the sensor code. To run it on a board,
read [boards.md](boards.md).

## The loop

`src/dock/main.cpp`:

```
setup:  80 MHz; light sleep on; wifi; the settings from NVS; I2C; BSEC; sensors.begin(); the first reading in 35 s
loop:   once a second, light-sleeping between passes
        until known   GET /about           every 30 s, for the server's time
        before a slot GET /board-settings  the settings, applied (dock-settings.md); a recalibration; a stopped sensor started again
        each slot     queue a reading      the SCD41 and BME688 means, a fresh SHTC3 and PM sample, the dock's own status, into PSRAM
        every pass    the SCD41            its measurement, when one is ready, for the next reading's mean
                      POST /sensor-readings       the oldest 100 in the queue as one batch, once the time is known
                      POST /calibration    BSEC's newest copy of its state, after each batch
        continuous    the PM fan and the status LED
BSEC:   a FreeRTOS task of its own; its state goes to NVS when accuracy first reaches 3, and every six hours after
LED:    a FreeRTOS task of its own, so the booting pattern runs while setup() blocks
```

- **80 MHz, not 240.** Wi-Fi needs 80 MHz. Below it, the APB clock follows the processor, which would move the
  serial baud rate. So 80 MHz is both the floor and the choice.
- **Light sleep.** Power management holds the clock at 80 MHz, and light-sleeps the chip whenever every task waits.
  Between passes of the loop, the Wi-Fi driver wakes it for the access point's beacons, the BSEC task for its
  samples, and the LED task for each step of the pattern ([led.md](led.md)). The LED's PWM runs through the sleep on
  the RC_FAST clock. The chip stays awake while its USB port is connected to a computer.
- **The PM fan.** It runs for the 35 s before each reading, and stops after it: 12% of the time at 5-minute slots,
  and 2% overnight. It is the dock's largest load: about 95 mA of the sensors' 110 mA *(measured)*. The 35 s is Plantower's
  30 s warm-up and a margin, counted back from the next slot. Each reading records in `pm_warmup_s` how long the fan
  ran, so the stored readings can show whether 30 s is enough. `SensorSuite` counts no missed frame while the fan is
  off, so a stopped fan does not make the module look dead. The settings can lengthen the time, or keep the fan on.

## The clock

The dock has no clock, and does not ask NTP.

- Every response from the server carries its time and its time zone ([versions.md](versions.md)). The dock holds
  the time as an offset from its uptime, so the readings it stamps and the slots the server counts always agree.
- Its uptime runs fast while the chip light-sleeps: about +350 ppm against the server, 0.6 s in 30 minutes. Before
  light sleep it was +25 ppm. Each response sets the time again, so only the timer to the next slot sees it
  ([schedules.md](schedules.md#the-docks-schedule)).
- Until the first response, the dock asks `GET /about` every 30 s. It queues its readings with their uptime, and
  stamps them when the time arrives. So a dock that starts while the server is down keeps what it measured, with
  the correct times. The exception is a new image on trial: three asks in a row that bring no time roll it back
  ([versions.md](versions.md)).

## The readings queue

- Each slot puts one reading into the queue, in the layout of [readings.md](readings.md). The reading is kept before
  anything is sent, so one path covers a post that works and an outage.
- Each pass of the loop posts the oldest 100 readings to `/sensor-readings` as one batch. A queue that built up
  while the server was down empties one batch a pass, and no new reading waits for more than one request.
- The queue is 2 MB of PSRAM: about 1,500 readings, or five days at a reading every five minutes. A restart empties
  it.

On the server:

- epd's `DisplayServer(ingest=...)` gives each batch to `ReadingsIngest`. It keeps each document for the
  Diagnostics pages. With `source.kind: store`, it also adds the batch to epd's `ReadingsStore` (SQLite), in one
  transaction.
- The store's key is the device and `ts`. So the same document posted twice is stored once, however the requests
  were batched, and the route is safe to repeat.
- `IngestSource` gives the store to the pages as the datasets `latest`, `history_24h` and `history_72h`, and
  `CorrectedSource` reduces the pressure to sea level and holds back an IAQ below accuracy 2 ([pages.md](pages.md)).
  With `source.kind: mock`, `MockReadingsSource` gives the simulated room under the same names. The Diagnostics
  pages read `status`.
- The fields (`co2_ppm`, `pm2_5`, `iaq`, `temp_c` ...) are CANARY's own. The kit stores a timestamped JSON
  document, and does not read it.
- BSEC's learned state goes to `POST /calibration` after each batch: the newest of the copies that BSEC takes each
  minute. `CalibrationStore` keeps it, and `GET /calibration` gives it back after the dock restarts. The dock then
  uses the more accurate copy, or the newer one ([boards.md](boards.md#bsec)). So a restart costs BSEC at most the
  learning since the last batch, even before its first save to NVS.

## The sensor code

- **One place names the parts.** `src/dock/main.cpp` names a concrete sensor type only in one
  `#if defined(USE_MOCK_SENSORS)` block. That block makes either the mocks or the real drivers, and binds them to
  `IShtc3&`, `IScd41&`, `IPmsa003i&` and `IBme688&`. All other code, the whole sampling sequence included, is written
  against those interfaces in `SensorSuite`. So the mocks run the code that runs on the device, not a copy of it.
  The `dock` and `dock-mock` environments differ only in `-DUSE_MOCK_SENSORS`.
- **`SensorSuite::sample()`** follows the datasheets:
  1. Wake the SHTC3, measure, wait 13 ms, read, and put it back to sleep.
  2. Take the mean of the BME688's cycles since the last reading, then give its pressure to the SCD41, so that the
     CO₂ conversion is correct. With BSEC the cycles are BSEC's own; without it the suite runs one forced cycle.
  3. Take the SCD41's measurement if one is ready, and the mean of those `poll()` took since the last reading. The
     part makes one every 5 s and keeps only the last, so the dock calls `poll()` every second, and the part is never
     asked twice for the same measurement.
  4. Read a PM frame, only after the fan's 30 s warm-up. Read once more after a read that fails or is damaged.
  A failed poll loses no measurement: the part keeps it, and the next poll reads it. The suite keeps why the SCD41
  gave no CO₂, each run of polls that it did not answer, and what each PM read met with its 32 bytes, and the dock
  logs them ([boards.md](boards.md)).
- **A reading holds the means of the SCD41's and the BME688's samples since the last reading**, so that a value covers
  the whole 5 or 30 minutes, not one moment of them. Each value counts only its good samples: the SCD41's
  temperature and humidity after its warm-up, the gas resistance from a heater at its target, each index at accuracy
  3 (`Bme688Mean`). A value with no good sample is the newest one. `samples` in the reading gives the counts
  ([readings.md](readings.md)). The status light judges the newest samples (`SensorSuite::newest()`), so an alert
  does not wait for a mean.
- **A reading has no `scd41` temperature and humidity during the SCD41's warm-up after each start.** The warm-up is
  `dock.scd41.warmup_s`, 3 minutes by default; 0 keeps every value. A start is a dock start, a change to the part's
  settings, or a recalibration. After a start the part's temperature reads high by about half its offset, and its
  humidity reads low to match: 2.6 °C at 40 s with an offset of 4.5, 0.6 °C at 110 s, and nothing at 260 s. These
  figures come from the dock's stored readings, not from the datasheet. The first reading after a dock start comes
  inside the first minute, and a change to the settings restarts the part 35 s before a slot, so each start would
  store one wrong value. The CO₂ stays in the reading: at a start it was within 15 ppm of the readings on each
  side, which is inside the part's accuracy.
- **The clock is injected** (`IClock`), because the waits are real: `ArduinoClock` on the device, a fake in the
  tests. `ArduinoClock` waits until the millisecond clock has moved on, not for one `::delay()`. While the chip
  light-sleeps, a delay can return up to 51 ms early, and a read before a conversion ends fails.
- **A sample takes about 150 ms** without BSEC, nearly all of it the BME688's heater, once a slot. With BSEC the
  suite runs no cycle of its own, and `poll()` adds one short I²C read a second. `::delay()` yields on the ESP32, so
  Wi-Fi keeps running. The interfaces already return false when a part is not ready, so `sample()` can
  become a state machine without a change to the drivers.
- **The bus is injected too** (`II2cBus`). The command sequences, the CRCs and the conversions are where a driver
  goes wrong, and a host test cannot drive `Wire`. `ArduinoI2cBus` wraps the `Wire` instance that the dock starts on
  SDA IO8 and SCL IO9 at 100 kHz. `test/test_drivers` runs the same drivers against fake parts that answer as their
  datasheets say.
- **The BME688 uses Bosch's own code.** Its compensation reads twenty calibration values from the part, and a
  mistake gives a number that looks correct. So Bosch's C API does that arithmetic (`lib/bme68x`, v4.4.8,
  BSD-3-Clause). It reaches the bus through function pointers, so it sits behind `II2cBus` too, and it builds for
  the host tests.
- **BSEC** gives the two indexes, static and not. It drives the BME688 through the same driver, from a task of its
  own. `BsecBme688` gives `SensorSuite` the mean of the cycles that BSEC ran since the last reading, so the sampling
  sequence is the same with BSEC as without it.

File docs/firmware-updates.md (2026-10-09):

# Firmware updates on the bench

How to test the updates over the air with a server on your own computer. First get the boards running
([boards.md](boards.md)).

Each board takes new firmware from the server. The server offers each board the newest image of its product that
works with the server's version: the same major and minor version, while the major is 0. A server that runs from a
checkout reports what `git describe` gives, for example `v0.6.2-5-gab12cd4`, so it offers development builds.

1. Make the folders, and set `client.firmware.enabled: true` in `config.yaml`:

   ```sh
   mkdir -p server/firmware/canary-display server/firmware/canary-dock
   ```

2. Flash each board once over USB, so that it stores your Wi-Fi and the server's address: with PlatformIO and
   `src/defaults.cpp` ([boards.md](boards.md)), or from the server's install page
   ([README.md](../README.md#2-install-each-boards-firmware)).
3. Commit a change. Then build each board, and copy its image into the folder under its version:

   ```sh
   v=$(git describe --tags --match 'v*' --dirty)
   pio run -e esp32 && cp .pio/build/esp32/firmware.bin server/firmware/canary-display/$v.bin
   PLATFORMIO_CORE_DIR=~/.platformio-canary-dock pio run -e dock && cp .pio/build/dock/firmware.bin server/firmware/canary-dock/$v.bin
   ```

- The file name must be the `CLIENT_VERSION` that the build prints.
- The install page offers a version only with its merged image beside it. To install a build from the page, copy
  `.pio/build/<env>/firmware.factory.bin` in as `$v.merged.bin` too, as the firmware builder does.
- Commit before each build. A tree with uncommitted changes builds `...-dirty`. Two builds of one commit have the
  same version, and the server does not offer a board the version that it already has.
- The display takes the image after its next page. The dock takes it after a post that empties its queue, and its
  LED shows the progress.
- The log shows the offer, the progress, the restart and `trial boot of <version>`. Then it shows
  `firmware <version> confirmed`, when the display has drawn a page or the server has taken the dock's readings.
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

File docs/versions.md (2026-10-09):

# Headers and versions

The headers between the boards and the server, which versions work together, and how the server updates the
boards. To test an update on the bench, read [firmware-updates.md](firmware-updates.md).

## Headers

Each header on the wire starts with `Canary-`. The server's responses are CANARY's interface, and a person who
reads the traffic must not need to know which library built it. The kit makes the names from a prefix that each
product sets: the server takes `header_prefix="Canary"`, and the firmware takes `-DEPD_HEADER_PREFIX='"Canary"'`. A
mismatch gives no error, so both come from this repo.
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

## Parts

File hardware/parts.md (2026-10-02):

# Parts reference

The datasheet facts for each part, and the power and the I²C bus. It is for developers. To buy the parts, read
[bom.md](bom.md).

## Inkplate 5 Gen2 — the display

Sources: [product page](https://soldered.com/products/inkplate-5-gen2) ·
[docs](https://docs.soldered.com/inkplate/5v2/overview/) ·
[hardware repo (KiCad, schematic PDF, BOM, STEP, STL)](https://github.com/SolderedElectronics/Soldered-Inkplate-5-Gen2-hardware-design) ·
[Arduino library](https://github.com/SolderedElectronics/Inkplate-Arduino-library) ·
[board definitions](https://github.com/SolderedElectronics/Inkplate-Board-Definitions-for-Arduino-IDE) ·
[free GPIO](https://docs.soldered.com/inkplate/5v2/hardware/free-gpio/) ·
[deep sleep](https://docs.soldered.com/inkplate/5v2/low-power/deep-sleep/) ·
[RTC alarm](https://docs.soldered.com/inkplate/5v2/rtc/alarm/)

### Core

| | |
|---|---|
| Panel | E Ink ED052TC4, 5.17", **1280 × 720**, **3-bit grey (8 levels)**. Full refresh 0.99 s, partial 0.22 s. |
| MCU | ESP32-WROVER-E. **8 MB PSRAM** *(derived)*: the board reports 4.0 MB, the most an ESP32 maps at a time, and a WROVER-E carries either 8 MB or 2 MB. Flash **at least 4 MB** *(unverified)*: the variant sets 4, 8 or 16 MB, the shield prints no suffix, and `partitions.csv` uses 4 MB. Library allocates ~921 kB PSRAM for framebuffers. |
| Radio | Wi-Fi, BT 4.0 BLE |
| USB | USB-C, CH340C UART, 500 mA fuse on VBUS *(schematic)* |
| Battery | 2-pin JST-PH 2.0 mm, 3.7 V Li-ion, MCP73831 charger at ~400 mA *(schematic, R32 = 2.49 k)* |
| RTC | PCF85063A, CR2032 backup holder |
| Storage | microSD (SPI on IO12–15, switched rail) |
| PMIC | TPS65186 (panel rails), TPS7A2633 3.3 V LDO |
| IO expander | PCAL6416A |
| No | touchscreen, frontlight, 5 V boost converter |

Gen2 vs Gen1: 960×540 → 1280×720 panel, I²S DMA panel driver, same 130.6 × 75.2 mm board.

### I²C and easyC

- SDA **GPIO21**, SCL **GPIO22** *(schematic)*. `Inkplate::begin()` calls `Wire.begin()` at the default 100 kHz.
- One easyC connector, K3. Pads 1 = SCL, 2 = SDA, 3 = 3V3, 4 = GND *(schematic)*. The same four signals are on the bottom header.
- Soldered states easyC is pin-compatible with Qwiic and STEMMA QT: black GND, red 3V3, blue SDA, yellow SCL.
- Host pull-ups: R1/R4 **10 kΩ** to 3V3 on SCL/SDA. No jumper to remove them *(schematic)*.
- easyC 3V3 is the main 3V3 net straight from the LDO. No current limit is stated.

### Onboard I²C addresses

| Device | Addr |
|---|---|
| PCAL6416A IO expander (ADDR = GND) | 0x20 |
| TPS65186 PMIC | 0x48 |
| PCF85063A RTC | 0x51 |

No conflict with 0x12, 0x62, 0x70, 0x76/0x77.

### Power

- Inputs: USB-C 5 V or battery, both at once allowed; USB takes over via a P-MOSFET when present *(schematic)*.
- **No 5 V boost.** The VIN pad is ≈5 V only with USB plugged in (VUSB through a Schottky), otherwise VBAT *(schematic)*.
- 3V3: TPS7A2633, **500 mA**, 2 µA quiescent, from VIN. Feeds ESP32, expander, RTC, panel PMIC 3.3 V input, microSD, and the easyC connector.
- Deep sleep 18 µA *(product page)*; 20–30 µA with peripherals asleep *(docs)*. Soldered publish no awake, Wi-Fi or refresh currents. A refresh measured with the dock: see [Measured peaks](#measured-peaks).
- `readBattery()`: expander P1_1 enables a MOSFET, 100k/100k divider, `analogReadMilliVolts(35) × 2`.
- No cell in the display: the charger runs at about 400 mA, which is 10 C for a 40 mAh cell that would fit, and the board draws 2.5–40 C from it.

### Deep sleep and wake

- RTC INT → JP2 (default INT) → **GPIO39** with 10 k pull-up *(schematic)*. Library example: `setAlarmEpoch(..., RTC_ALARM_MATCH_DHHMMSS); esp_sleep_enable_ext0_wakeup(GPIO_NUM_39, 0);`, which is what `EpdBoardInkplate::enableWakeOnRtcAlarm()` does. Measured: every wake from a 10 s alarm logged `ESP_SLEEP_WAKEUP_EXT0` on time. The display's deep sleep uses it.
- Wake button SW3 → GPIO36, active low. Expander INT → GPIO34.
- **easyC 3V3 stays on in deep sleep.** It is the unswitched LDO output the ESP32 itself runs from. Only microSD and RTC rails are switched.
- Free GPIO: expander P1_3–P1_7 on the bottom header; `gpioInit()` sets them OUTPUT LOW. Use `display.expander1.pinMode/digitalWrite(IO_PIN_B3..B7, ...)`. Do not use P0_x.

### Arduino / PlatformIO

- Board define **`ARDUINO_INKPLATE5V2`** (Arduino core `INKPLATE5V2`). Selects `Inkplate5V2Driver.h`, `MULTIPLE_DISPLAY_MODES`, `USES_I2S`.
- No PlatformIO board JSON exists. The `esp32` environment uses `board = esp32dev`, `board_build.f_cpu = 240000000L` and `-DARDUINO_INKPLATE5V2 -DBOARD_HAS_PSRAM -mfix-esp32-psram-cache-issue`.
- `INKPLATE_1BIT 0`, `INKPLATE_3BIT 1`; `E_INK_WIDTH 1280`, `E_INK_HEIGHT 720`.
- RTC API as used by the kit: `setEpoch`, `getEpoch`, `getRtcData`, `setAlarmEpoch(epoch, match)`, `clearAlarmFlag`. Match modes `_SS`, `_MMSS`, `_HHMMSS`, `_DHHMMSS`, `_WHHMMSS`.
- Do a full update after a run of partial updates *(docs FAQ)*; `setFullUpdateThreshold(n)`.

### Physical *(KiCad PCB, component side, origin top-left, mm)*

- Outline **130.59 × 75.23**, 2.5 mm corner radius, 1.6 mm PCB.
- Mounting: 4 × SMT M3 standoffs at (3.40, 3.40), (127.19, 3.40), (3.40, 71.83), (127.19, 71.83) — pitch **123.79 × 68.43**.
- USB-C (3.00, 60.23) left edge · power button (2.00, 49.23) left · wake button (128.59, 49.23) right · battery JST (28.00, 15.23) · microSD (10.00, 31.23) · **easyC (100.00, 41.23)** · CR2032 (114.00, 41.23) · ESP32 (80.83, 15.80) · panel FPC (27.50, 46.43).
- Header: 1×1 pads on 2.54 mm along the bottom edge (y = 73.73), x = 19.57–111.01: panel group, ESP32 group (GND, 3V3, TXD, RXD, IO12–15, IO34, V_BAT, IO36, IO39), I²C group (GND, 3V3, SDA, SCL), expander group (GND, 3V3, P1_1–P1_7). The pads are 0.8 mm drills, so a header needs round machined pins.
- Panel 124.59 × 69.14 mm centred on the far side; active area 114.56 × 64.44 mm.
- Soldered enclosure: 145.24 × 84.23 × 13.5 mm, sold assembled (€19.95) and published as STL/STEP.

---

## TinyS3 — the dock

[Unexpected Maker's board](https://unexpectedmaker.com/tinys3): an ESP32-S3 with 8 MB of flash and 8 MB of
PSRAM, USB-C, and two 12-way header rows. It hosts the four sensors, keeps the reading queue in its PSRAM and
posts to the server.

- **Supply**: 5 V on its 5V pin, from the dock's USB-C socket. The whole dock at 5 V, light-sleeping *(measured,
  PPK2)*: 11.7 mA at its lowest, 36.8 mA idle, 48.9 mA on average at 5-minute readings, 140 mA while the PM fan
  runs. Kept awake, the chip draws about 40 mA more.
- **Pins used**, by the labels printed on the board: **9** SCL, **8** SDA, **7** the PM fan's SET line,
  **6** the status LED, both **GND** pins, and **5V** the 5 V in. Nothing else is wired.
- **Headers**: soldered long pins down, so the board drops into the female strips in its cradle and lifts out
  again for flashing.

## SCD41 — CO₂

Sources: [SCD4x datasheet v1.7](https://sensirion.com/media/documents/48C4B7FB/67FE0194/CD_DS_SCD4x_Datasheet_D1.pdf) ·
[low-power app note](https://sensirion.com/media/documents/077BC86F/62BF01B9/CD_AN_SCD4x_Low_Power_Operation_D1.pdf) ·
[design-in guide](https://sensirion.com/media/documents/0D0C9129/623B1183/Sensirion_CO2_Sensors_SCD4x_design-in_guide.pdf) ·
[Adafruit 5190](https://www.adafruit.com/product/5190) · [learn guide](https://learn.adafruit.com/adafruit-scd-40-and-scd-41) ·
[Sensirion library](https://github.com/Sensirion/arduino-i2c-scd4x) ·
[module STEP](https://sensirion.com/media/documents/260AFF2D/616531AE/Sensirion_CO2_Sensors_SCD4x_STEP_file.step)

### Measures

| | Range | Accuracy | τ63 |
|---|---|---|---|
| CO₂ | 400–5000 ppm (output 0–40 000) | ±(50 ppm + 2.5 %) to 1000; ±(50 + 3 %) to 2000; ±(40 + 5 %) to 5000 | 60 s |
| RH | 0–100 % | ±6 % (15–35 °C) | 90 s |
| T | −10–60 °C | ±0.8 °C (15–35 °C) | 120 s |

Repeatability ±10 ppm. Drift ±(5 ppm + 0.5 %)/year. RH/T specs hold only with the temperature offset set for the enclosure.

### Electrical

- VDD 2.4–5.5 V. **Peak 175 mA typ / 205 mA max at 3.3 V** (115/137 at 5 V), "sustained" during the measurement pulse. Supply ripple must be < 30 mV p-p unloaded; **Sensirion recommends a separate LDO.**
- Average: 15 mA (periodic 5 s), 3.2 mA (low-power periodic 30 s), 0.45 mA (single-shot every 5 min). Idle < 200 µA. Single shot costs 77 mC at 3.3 V.
- I²C 0x62, not changeable. 0–400 kHz. Power-up to idle 30 ms.

### Commands

All words 16-bit MSB-first; each data word followed by CRC-8 (poly 0x31, init 0xFF, no reflect, no final XOR; CRC(0xBEEF) = 0x92).

| Command | Code | Wait | Notes |
|---|---|---|---|
| start_periodic_measurement | 0x21B1 | — | 5 s interval. Only read/data-ready/stop/pressure allowed while running. |
| start_low_power_periodic_measurement | 0x21AC | — | 30 s interval. |
| stop_periodic_measurement | 0x3F86 | 500 ms | |
| measure_single_shot | 0x219D | 5000 ms | Fastest interval 5 s. Datasheet v1.6 dropped the "discard first shot after power-up" note; the 2022 app note still says discard it. |
| read_measurement | 0xEC05 | 1 ms | 9 bytes: CO₂, T, RH words + CRCs. **NACKs if no data** — poll data-ready first. |
| get_data_ready_status | 0xE4B8 | 1 ms | low 11 bits == 0 → not ready |
| set_temperature_offset | 0x241D | 1 ms | word = °C × 65535/175. Default 4 °C. Idle only. |
| set_ambient_pressure | 0xE000 | 1 ms | word = Pa/100, 70 000–120 000 Pa. **Allowed during periodic measurement. Feed the BME688's pressure in.** |
| set_automatic_self_calibration_enabled | 0x2416 | 1 ms | default on |
| perform_forced_recalibration | 0x362F | 400 ms | run ≥ 3 min first, stop, wait 500 ms |
| persist_settings | 0x3615 | 800 ms | EEPROM, ≥ 2000 cycles |
| power_down / wake_up | 0x36E0 / 0x36F6 | 1 / 30 ms | wake_up is never ACKed; verify with get_serial_number |
| get_serial_number | 0x3682 | 1 ms | 48-bit |
| perform_self_test | 0x3639 | 10 000 ms | word 0 → OK |

T = −45 + 175 × word/65535; RH = 100 × word/65535.

### How the dock runs it

- **Periodic measurement (5 s)**, 15 mA on average. The dock takes each measurement as it comes, and a reading holds their mean. Low-power periodic (30 s) would average 3.2 mA.
- ASC works in both periodic modes, and needs ≥ 3 min of ~400 ppm fresh air each week. It does **not** work in power-cycled single-shot mode. `dock.scd41.self_calibration` turns it on or off.
- The dock gives the SCD41 the BME688's pressure (`set_ambient_pressure`) at each reading.
- `dock.scd41.temperature_offset_c` sets the temperature offset. Find it in the finished enclosure after 15 min of thermal equilibrium: `offset_new = T_scd − T_shtc3 + offset_prev`.

### Gotchas

- After each start of the periodic measurement, the temperature reads high by about half the offset and the humidity low to match, for about 2 minutes. Measured on the dock (2.6 °C at 40 s with an offset of 4.5); not in the datasheet. The dock leaves both values out of a reading for its warm-up after a start (`dock.scd41.warmup_s`, 3 minutes by default).
- Self-heating: the default 4 °C offset is a guess; measure it in situ. Design-in guide sanity check: > 0.5 °C from the reference after 15 min, or > 20 ppm between consecutive readings, means the design-in is poor.
- Placement: large opening near the sensor, small dead volume, away from CPU, display, Wi-Fi, regulators, battery; lowest part of the device; out of sunlight and vibration.
- Do not touch or wet the white membrane.
- Settings are RAM-only until `persist_settings`.

### Driver

canary's own: `Scd41Driver` (`src/sensors/Scd41Driver.cpp`).

### Adafruit 5190 board

- 25.4 × 22.86 mm. Four 3.0 mm holes at (2.54, 2.54), (22.86, 2.54), (2.54, 20.32), (22.86, 20.32) — pitch 20.32 × 17.78.
- Two STEMMA QT connectors, one per side edge, plus a 5-pin header (VIN, 3Vo, GND, SCL, SDA).
- VIN 3–5 V; AP2112K regulator; BSS138 level shifter; **10 kΩ pull-ups on SDA/SCL, no jumper to disable**. Sensor is powered straight from VIN by default ("Sensor Power" jumper). Rev A silkscreen for the two back jumpers is reversed.

---

## PMSA003I — particulates

Sources: [Plantower PMSA003I manual V2.6](https://cdn-shop.adafruit.com/product-files/4632/4505_PMSA003I_series_data_manual_English_V2.6.pdf) ·
[Adafruit 4632](https://www.adafruit.com/product/4632) · [learn guide](https://learn.adafruit.com/pmsa003i) ·
[schematic](https://cdn-learn.adafruit.com/assets/assets/000/092/990/original/sensors_PMSA300I_sch.png) ·
[Eagle files](https://github.com/adafruit/Adafruit-PMSA003I-PCB) ·
[Adafruit_PM25AQI](https://github.com/adafruit/Adafruit_PM25AQI) ·
[AP3602A charge pump](https://cdn-shop.adafruit.com/product-files/3661/AP3602A_B.pdf)

### Measures

- PM1.0 / PM2.5 / PM10 in µg/m³, two flavours: "CF=1, standard particle" (factory) and "atmospheric environment". Use the **atmospheric** ("env") values for indoor readings; the library's AQI uses them.
- Particle counts per 0.1 L for > 0.3 / 0.5 / 1.0 / 2.5 / 5.0 / 10 µm.
- Range 0–500 µg/m³ effective, ≥ 1000 max. Resolution 1 µg/m³. Consistency ±10 % (100–500) / ±10 µg/m³ (0–100). Counting efficiency 50 % @ 0.3 µm, 98 % @ ≥ 0.5 µm.
- Internal update every 2.3 s (stable) to 200–800 ms (fast). Total response ≤ 10 s.

### Electrical — the 5 V question

- Module: **DC 5.0 V (4.5–5.5)**, "needed because the FAN should be driven by 5V". Data pins are 3.3 V logic (L < 0.8 V, H > 2.7 V). Active ≤ 100 mA, standby ≤ 200 µA.
- Adafruit board: **makes its own 5 V** with an AP3602A charge pump from VIN 3–5 V, so it runs from a 3.3 V Qwiic chain. AP3602A: 100 mA continuous, 250 mA for 100 ms, input current ≈ 2 × output. Measured: **about 95 mA from 3.3 V while the fan runs** *(PPK2: the dock's current with the fan on, less the current with it off)*.
- Board also has an AP2112K 3.3 V LDO (pull-ups, LED, level shifter) and a BSS138 level shifter. **10 kΩ pull-ups on both sides of the shifter; the connector side is pulled to VIN.** ⇒ a 5 V VIN pulls the shared bus to 5 V, past the SCD41's VDD + 0.3 V absolute maximum. **Keep VIN at 3.3 V**, though the module itself wants 5 V: the charge pump makes that.
- I²C **0x12**, fixed. 100 kHz-class timing. No UART on this variant (pins 6 and 8 NC).

### Interface

One plain 32-byte I²C read, big-endian words:

| Bytes | Field |
|---|---|
| 0–1 | 0x42 0x4D start |
| 2–3 | frame length = 28 |
| 4–9 | PM1.0 / PM2.5 / PM10, CF=1 |
| 10–15 | PM1.0 / PM2.5 / PM10, atmospheric |
| 16–27 | counts > 0.3 / 0.5 / 1.0 / 2.5 / 5.0 / 10 µm per 0.1 L |
| 28 | version |
| 29 | error code |
| 30–31 | checksum = sum of bytes 0–29 |

The sensor updates its registers itself; the host polls. **No I²C commands** for sleep/wake or passive mode. Fan control is the **SET pin** (high = run, low = sleep ≤ 200 µA; on the breakout SET low also shuts the charge pump). RST low resets. Both have 100 k pull-ups on the breakout; drive from a GPIO.

### Warm-up

- **≥ 30 s after wake** for stable data (fan spin-up). After power-on, the module needs 3 s before it answers.
- Intermittent use reported to read high; 2–3 min to settle *(unverified, PMSA003 UART sibling)*.
- Endurance test: SET toggled at 0.5 Hz for 72 h — frequent duty-cycling is within spec.

### How the dock runs it

The fan runs for the 35 s before each reading (`dock.pm.warmup_s`), and stops after it: Plantower's 30 s warm-up and a margin. Each reading records how long the fan had run (`pm_warmup_s`), so the stored readings can show whether that is enough given the field reports above. SET is optional: the breakout's 100 k pull-up holds it high, so with no wire the fan runs from power-on and all the time. Wired to the TinyS3's pin 7 ([assembly.md](assembly.md)), it lets the firmware stop and start the fan.

### Gotchas

- Metal shell is GND. Inlet/outlet against the enclosure wall, or a baffle between them; enclosure vent ≥ inlet size; ≥ 20 cm above the floor; not in an air purifier's flow; indoor only; kitchen/bathroom mist needs protection.
- Overreads above ~80 % RH *(studies, unverified)*.
- Module screw holes Ø1.7 mm, thread depth max 3.4 / 1.9 mm.

### Driver

canary's own: `Pmsa003iDriver` (`src/sensors/Pmsa003iDriver.cpp`). A read that fails, or a damaged frame, is read once more.

### Adafruit 4632 board

- **35.56 × 50.80 mm**, 13.6 mm tall with the module, 28 g.
- Holes 2.5 mm at (2.54, 2.54), (33.02, 2.54), (2.754, 48.3), (32.754, 15.3).
- Two STEMMA QT connectors on the left/right edges near the bottom (y = 8.89). 7-pin header along the bottom: VIN, 3Vo, GND, SCL, SDA, RST, SET.
- Module 38 × 35 × 12 mm sits on top; fan face away from the PCB; inlet slots on the 12 mm side faces.

---

## BME688 — VOC, gas and pressure

Sources: [Bosch datasheet rev 1.3](https://www.bosch-sensortec.com/media/boschsensortec/downloads/datasheets/bst-bme688-ds000.pdf) ·
[BSEC software](https://www.bosch-sensortec.com/software-tools/software/bme688-and-bme690-software/) ·
[BSEC2 Arduino](https://github.com/boschsensortec/Bosch-BSEC2-Library) ·
[BME68x API](https://github.com/boschsensortec/BME68x_SensorAPI) ·
[Soldered 333203](https://soldered.com/products/bme688-environmental-sensor) · [docs](https://docs.soldered.com/bme688/hardware/) ·
[Soldered library](https://github.com/SolderedElectronics/Soldered-BME688-Sensor-Arduino-Library)

### Measures

- **Gas resistance (Ω)** from a heated metal-oxide layer: lower = more reducing VOCs. Also moved by humidity. Sums VOCs; blind to CO₂.
- With **BSEC** (closed-source Bosch binary): IAQ 0–500 (auto-trimmed to recent history; ~50 good, ~200 polluted), **static IAQ** (recommended for a stationary device), CO₂-equivalent, breath-VOC-equivalent, accuracy 0–3.
- Pressure 300–1100 hPa, ±0.6 hPa absolute, ±0.12 relative. Humidity ±3 % (20–80 %). Temperature ±0.5 °C **"typically above ambient"** — self-heating, see below.
- BME688 over BME680: gas-scanner mode (10-step heater profile, AI-Studio classification). Not needed here.

### Electrical

- VDD 1.71–3.6 V, optimised for 1.8 V (the Soldered board runs it at 3.3 V; heat scales with supply).
- Sleep 0.15 µA. Forced T/P/H ~3.7 µA at 1 Hz. **Heater 12 mA typ, 17 mA peak.** BSEC averages: ULP 0.09 mA, LP 0.9 mA.
- I²C **0x76** (SDO low) default on Soldered; JP1 → 0x77. Up to 3.4 MHz.
- Soldered board: onboard regulator, VCC 3.3–5 V; JP3 regulator enable (NC); JP2 (NO) is not a bypass: Soldered's docs say "when connected, the voltage regulator is powered by 5V". What JP2 joins is unverified, because no schematic is published; check it with a meter before bridging it. **JP5 (NC) 3.3 V pull-ups, JP4 (NC) 5 V pull-ups — cut to disable.** 10 k, from the `103` marking on the board.

### Interface (forced mode)

Chip ID 0xD0 = 0x61; variant 0xF0 = 0x01. Set osrs_h (0x72), then osrs_t/osrs_p (0x74), gas_wait_0 (0x64, e.g. 100 ms), res_heat_0 (0x5A, computed from calibration), run_gas (0x71 bit 5), then mode = forced (0x74 bits 1:0). Poll new_data (0x1D bit 7). Read P 0x1F–21, T 0x22–24, H 0x25–26, gas 0x2C–2D with **gas_valid (bit 5) and heat_stab (bit 4)** — both must be set. Heater reaches target in 20–30 ms; typical indoor profile **300–320 °C for 100–150 ms**. Rely on the Bosch API for compensation maths.

### BSEC on ESP32

- Runs on ESP32 Arduino (`boschsensortec/bsec2` on PlatformIO, precompiled `libalgobsec`). ROM ~37 kB, RAM ~4 kB. Clickthrough licence.
- Sample rates: **LP 3 s** (0.9 mA) or **ULP 300 s** (0.09 mA). Calibration: accuracy 0 for ~5 min (LP) / ~20 min (ULP), then hours to reach 3; needs both clean and polluted air exposure.
- **State blob 238 bytes** must be saved and restored or calibration restarts. Config blob (~1.9 kB, pick the 3.3 V / 3 s or 300 s / 4 d or 28 d variant) is re-applied each boot. BSEC needs a monotonic clock (`Bsec2::begin` takes a millis function).
- The dock keeps BSEC's state in RAM, and saves it to NVS every 6 hours ([docs/boards.md](../docs/boards.md#bsec)). Most BSEC failures reported on forums are in deep-sleep setups. The dock uses light sleep, which keeps RAM.
- The firmware links BSEC2 1.10.2610's `libalgobsec` without Bosch's Arduino wrapper, whose sources need a second copy of the BME68x API; `scripts/bsec.py` adds the headers, the config blobs and the binary. It uses `bme688_sel_33v_3s_28d` or `bme688_sel_33v_300s_28d`, to match `dock.bsec.sample_s`, subscribes to the IAQ outputs and to raw pressure at that rate, posts the IAQ and the static IAQ, and runs in a FreeRTOS task of its own. Without an output that needs pressure, BSEC asks for no pressure conversion, the BME688 skips it, and the reading comes out near 659 hPa. The Arduino package has no BME688 configuration named for IAQ, but `sel` gives an index from the first sample. At 3 s with the 4-day configuration, it reached accuracy 1 in about 4 minutes and 3 in about 40 *(bench)*. The 4-day and 28-day blobs differ only in a few time values (86,400 s against 604,800 s; at 3 s also two of 3,600 s against 172,800 s) and their checksum, so the heater profile and the outputs are the same. Restarted from the state in NVS, it is back at accuracy 3 within 3 minutes *(bench)*.
- BSEC's header gives its pressure input in Pa, but Bosch's own BSEC2 wrapper passes hPa, and so does the firmware. BSEC took 1019 hPa without an error and kept giving an index *(bench)*.

### Self-heating

Die runs above ambient; heater 200–400 °C after the T/P/H read. Bosch offsets 1.33 °C (LP) / 0.47 °C (ULP); users report 1–3 °C. **Use the SHTC3 for T/RH; treat BME688 T/RH as BSEC-internal.**

### Driver

`Bme688Driver` (`src/sensors/Bme688Driver.cpp`) over Bosch's BME68x API in `lib/bme68x`, and BSEC for the IAQ.

### Soldered 333203 board

- **38.0 × 22.0 mm** *(measured)*, four M3 (3.2 mm) corner holes, 1.5 mm header holes. Two easyC connectors, one per short edge; 4-pin header GND/VCC/SDA/SCL on the long edge. Sensor near centre.
- No public hardware repo: Soldered's docs call it "not available yet" and send the files on request.

---

## SHTC3 — temperature and humidity

Sources: [SHTC3 datasheet v4](https://sensirion.com/media/documents/643F9C8E/63A5A436/Datasheet_SHTC3.pdf) ·
[low-power app note](https://sensirion.com/media/documents/00887EF5/6164030A/Sensirion_AppNotes_Humidity_Sensors_SHTC3_Low_Power_Measurement_Mode.pdf) ·
[SHTxx design guide](https://media.digikey.com/pdf/Data%20Sheets/Sensirion%20PDFs/HT_AN_SHTxx_STSxx_Design%20Guide_V1.1_D1.pdf) ·
[Soldered 333032](https://soldered.com/products/temperature-and-humidity-sensor-shtc3-breakout) · [docs](https://docs.soldered.com/shtc3/hardware/) ·
[Adafruit_SHTC3](https://github.com/adafruit/Adafruit_SHTC3) · [Soldered library](https://github.com/SolderedElectronics/Soldered-SHTC3-Temperature-Humidity-Sensor-Arduino-Library)

### Measures (normal mode)

| | Range | Typ accuracy | Max | τ63 | Drift |
|---|---|---|---|---|---|
| RH | 0–100 % | ±2 % (20–80 %, 25 °C) | ±3.5 % | 8 s | < 0.25 %/yr |
| T | −40–125 °C | **±0.2 °C** (5–60 °C) | ±0.4 °C | 5–30 s | < 0.02 °C/yr |

Recommended operating range 5–60 °C, 20–80 % RH; long exposure > 80 % gives a temporary offset that self-recovers.

### Electrical

- VDD 1.62–3.6 V. Sleep **0.3 µA**, idle 45 µA, measuring 430 µA (normal) / 270 µA (low-power). 15.4 µJ per normal reading.
- I²C **0x70, fixed**. Up to 1 MHz. Clock stretching supported; prefer the no-stretch commands on ESP32.
- Soldered board: regulator, VCC 3.3–5 V; **JP2 (NC) 3.3 V pull-ups, JP1 (NC) 5 V pull-ups — cut to disable.** 10 kΩ, from the `103` marking on the board. Level shifter between the header and the easyC side. JP3 (NC) feeds the regulator and JP4 (NO) bypasses it; Soldered's docs say "Ensure JP3 is disconnected if JP4 is connected". The component side carries JP1–JP4 and no JP5.

### Commands

| | Code |
|---|---|
| Wakeup | 0x3517 |
| Sleep | 0xB098 |
| Soft reset | 0x805D |
| Read ID | 0xEFC8 (ID & 0x083F == 0x0807) |
| **Normal, no stretch, T first** | **0x7866** |
| Normal, stretch, T first | 0x7CA2 |
| Low-power, no stretch, T first | 0x609C |

Sequence from sleep: wakeup → ≥ 240 µs → measure → ≥ 12.1 ms (0.8 ms low-power) → read 6 bytes (T MSB, LSB, CRC, RH MSB, LSB, CRC) → sleep. ~13 ms total. CRC-8 poly 0x31 init 0xFF. T = −45 + 175 × S/2¹⁶; RH = 100 × S/2¹⁶. First reading after wakeup is valid.

Low-power mode is ±0.8 °C. The dock measures in normal mode unless `dock.shtc3.low_power` is true. Its driver is `Shtc3Driver` (`src/sensors/Shtc3Driver.cpp`).

### Placement (Sensirion design guide)

"External heat sources close to the sensor will cause increased temperature (and thus decreased RH) readings" — 1 °C error ≈ 5 % RH at 90 %. Conduction from "power electronics, microprocessors, displays" is the most common cause. Put it at the enclosure edge or corner, with airflow across it, isolated from the board by slits, shielded from heated air, out of sunlight. The Soldered board already has the sensor on a slotted thermal island. No polyamide near it; at most one membrane per aperture.

### Soldered 333032 board

- **38.0 × 22.0 mm** *(measured)*, 2 mm corner radius, four Ø3.2 mm (M3) holes inset 3.05 mm on a 32 × 16 mm pitch. Soldered's product page and docs give 22 × 22 mm with two holes, which does not match the board. Two easyC connectors on the short ends; unpopulated 4-pin header on one long edge.
- No public hardware repo: Soldered's docs call it "not available yet" and send the files on request.

---

## AMS1117-3.3 — the sensors' 3.3 V

- The sensors' 3.3 V comes from this module, not from the TinyS3's own regulator. That regulator is an NCP167 at
  198 °C/W in a 1 × 1 mm package. At the sensors' peak it would heat by about 130 °C, past its thermal shutdown.
- It is an LDO, so it drops 1.7 V and turns about 0.19 W into heat at 110 mA, while the PM fan runs.
  [enclosure.md](enclosure.md#ventilation) has the air passage under it.
- The plain 3-pin module is 12.5 × 8.5 mm, with its pins in the order GND, OUT, VIN. [bom.md](bom.md#the-small-parts)
  has the pin trap.

## Power and the bus

### Budget on the sensors' 3.3 V rail

| Load | Typical | Peak |
|---|---|---|
| PMSA003I via its charge pump, fan running | ~95 mA *(measured)* | 250 mA / 100 ms (the charge pump's limit) |
| SCD41, periodic 5 s | 15 mA | **175–205 mA** during each measurement |
| BME688, BSEC at 300 s (at 3 s: 0.9 mA) | 0.09 mA | 17 mA |
| SHTC3 | 0.4 mA | 0.9 mA |
| **Total** | **~110 mA** | **~470 mA** |

The dock is fed 5 V over USB-C. The TinyS3 takes it on its 5V pin, the AMS1117 turns it into the sensors'
3.3 V, and two pogo contacts carry it up to the display's VIN pads. [assembly.md](assembly.md) has the circuit
and every joint.

### Measured peaks

PPK2 at 5.0 V into the dock's USB-C socket, the display and the dock together, 2026-09-24:

| When | Peak |
|---|---|
| Power-on inrush | 1.07 A for 0.06 ms |
| Boot | 507 mA over 10 ms, single samples to 751 mA |
| Display refresh, about 1.4 s | 485 mA over 10 ms, single samples to 631 mA |

The dock's own currents with light sleep are under [TinyS3](#tinys3--the-dock).

### One ground return

The chain returns through a single conductor, cable 1's GND. At worst the whole chain returns under 300 mA — the
PM fan about 100 mA, an SCD41 burst about 200 mA — through 28 AWG, which is a few millivolts of shift. That is
below anything I²C notices. The AMS1117's own GND wire carries only the regulator's few mA, and the display's
ground crosses the pogo pair on its own two contacts.

### 5 V on the Inkplate's VIN pads

This is Soldered's own answer for this circuit
([forum thread 1934](https://community.soldered.com/t/externally-powering-the-inkplate-5v2-with-5v/1934)). The
5 V reaches the charger's output through the source-select transistor; Soldered say that is harmless. No diode
guards against back-feed, because the dock's side wall covers the board's own USB-C while the display is docked
([assembly.md §9](assembly.md#9-the-display)).

### Why the sensors do not hang off the display

Every sensor runs at 3.3 V on an ordinary Qwiic cable, so for bring-up the whole chain can hang off any 3.3 V
I²C host, the Inkplate's own easyC socket included, with nothing to change on any board. What that arrangement
cannot do is *run*. The host's rail cannot carry the sensor peaks on top of its own processor and Wi-Fi bursts,
and the PM board's ~100 mA would cross every upstream board's connectors. The symptom is an intermittent
brown-out when the fan, an SCD41 measurement peak and a Wi-Fi transmit coincide — the hardest kind of fault to
find later. That is why the dock has its own regulator.

## The I²C bus

Sources: [NXP UM10204](https://www.nxp.com/docs/en/user-guide/UM10204.pdf) ·
[SparkFun Qwiic](https://www.sparkfun.com/qwiic) · [Adafruit STEMMA QT](https://learn.adafruit.com/introducing-adafruit-stemma-qt/technical-specs) ·
[Soldered Qwiic/easyC](https://docs.soldered.com/qwiic/) · [JST SH](https://www.jst-mfg.com/product/detail_e.php?series=231)

### Connectors

easyC, Qwiic and STEMMA QT are all **JST SH 1.0 mm 4-pin, same order: black GND, red 3V3, blue SDA, yellow SCL**. A stock cable chains a Soldered board to an Adafruit board. Every sensor board here has two connectors in parallel (pass-through); the Inkplate has one. Cable 28 AWG; SparkFun's conservative cable limit **226 mA**, JST contact rating 1 A. The 226 mA is a bundled, long-run derating for 28 AWG — a single short conductor in free air is good to ~1 A, which is also the contact limit. [assembly.md](assembly.md)'s cable 1 carries the whole chain's ground return, up to ~470 mA at peak, on that basis; it is the most heavily loaded Qwiic conductor in the build and the reason the display's ground crosses the pogo pair on its own contacts. STEMMA (non-QT, JST PH 2 mm) is a different thing.

### Addresses

0x12 PMSA003I · 0x62 SCD41 · 0x70 SHTC3 · 0x76 BME688 · plus 0x20 / 0x48 / 0x51 on the Inkplate. **No conflicts.**
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

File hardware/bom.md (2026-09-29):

# Bill of materials

What to buy for one CANARY. The parts cost about €220, and two thirds of that is the panel and the two Adafruit
sensors. The prices are what the makers asked in September 2026, before tax and delivery. Use them to plan, not to
order.

- [enclosure.md](enclosure.md) has the printed parts and the fasteners.
- [assembly.md](assembly.md) builds the device.
- [parts.md](parts.md) has the datasheet facts for each part.

## What to buy

| Part | Qty | Where | Rough cost |
|---|---|---|---|
| Soldered Inkplate 5 Gen2 (333333) | 1 | [soldered.com](https://soldered.com/products/inkplate-5-gen2) | €75 |
| Unexpected Maker TinyS3 (ESP32-S3, 8 MB PSRAM) | 1 | [unexpectedmaker.com](https://unexpectedmaker.com/shop.html), Adafruit 5398, Pimoroni | €20–35 |
| Adafruit PMSA003I (4632) | 1 | [adafruit.com](https://www.adafruit.com/product/4632) | $45 |
| Adafruit SCD-41 (5190) | 1 | [adafruit.com](https://www.adafruit.com/product/5190) | $50 |
| Soldered BME688 (333203) | 1 | [soldered.com](https://soldered.com/products/bme688-environmental-sensor) | €21 |
| Soldered SHTC3 (333032) | 1 | [soldered.com](https://soldered.com/products/temperature-and-humidity-sensor-shtc3-breakout) | €6 |
| AMS1117-3.3 module | 1 | any marketplace, sold in tens | under €1 each |
| USB-C female breakout, 24-pin, 15 × 14.5 mm | 1 | any marketplace, sold in fives or tens | about €1 each |
| 8-pin magnetic pogo pair, 2.3 mm pitch, panel mount | 1 | any marketplace | €3–6 |
| Qwiic / easyC cable: 45 mm, 30 mm, 40–45 mm, plus one to cut up | 4 | Soldered, Adafruit, SparkFun | €1–2 each |
| Single-row female header strip, 20-way, standard height | 2 | any marketplace | pennies |
| Dupont housing, 1-pin, with crimp contact | 8 | any marketplace, sold in kits | pennies |
| 3 mm diffused yellow LED | 1 | any marketplace | pennies |
| Resistor, ¼ W: 1 kΩ ×1, 5.1 kΩ ×2 | 3 | any marketplace | pennies |
| LEGO 1×1 round tile, clear (35380 / 98138) | 1 | BrickLink, or a spare brick | pennies |
| 28 AWG stranded wire, heat-shrink, glue | — | — | — |
| 5 V USB power supply, 2 A, and its cable | 1 | any | €10 |
| M3 brass heat-set insert, about 5.7 mm long, 4.6 mm outside diameter | 6 | any marketplace | pennies |
| M3 × 8 countersunk screw, 90° | 4 | any marketplace | pennies |
| M3 × 6 machine screw | 6 | any marketplace | pennies |
| M2 × 4 self-tapping screw, pan head | 4 (8 fills every hole) | any marketplace | pennies |
| M2.5 × 4 self-tapping screw | 4 (8 fills every hole) | any marketplace | pennies |
| Filament: PLA+, and a little white for the logo | — | — | — |

- **Buy these exact boards.** The printed parts are drawn around them, the pogo pair and the USB-C module. A
  different board needs its pocket, bosses or opening changed in `enclosure.py`. The wire, headers, resistors, LED
  and supply are ordinary stock.
- **Use a 2 A supply.** A computer's USB-A port gives 0.5–0.9 A. At power-on the device takes 1.07 A for 0.06 ms,
  and at boot up to 750 mA.
- **The two 5.1 kΩ resistors** make a USB-C to USB-C cable or a USB-C charger turn on its 5 V. A USB-A to USB-C
  cable does not need them: its plug has the resistor, and a USB-A port always gives 5 V.

## The small parts

- **AMS1117-3.3 module.** It gives the sensors their 3.3 V. The TinyS3's own regulator cannot carry them
  ([parts.md](parts.md#ams1117-33--the-sensors-33-v)).
  - Buy the plain 3-pin module with no mounting holes, 12.5 × 8.5 mm. Its pocket is drawn to that size.
  - Its pins are **GND, OUT, VIN** along the header. OUT is the middle pin on every one of these boards, so the
    silkscreen on the board in your hand tells the two ends apart. Do not trust a drawing.
  - **5 V on the GND pin destroys the part in seconds.** Nothing protects it.
- **USB-C female breakout, 24-pin.** The dock's only power input, and its only opening in the rear wall. The
  dock uses only two pads: V, and the wide end pad as ground. [assembly.md](assembly.md#4-the-usb-c-socket) tells
  you to check the ground pad with a meter.
- **8-pin magnetic pogo pair.** It connects the display to the dock. Four contacts carry power, and four are not
  used. Each 0.5 mm pin carries about 1 A *(measured)*. The magnets hold the display down, and the shape of the
  contact block stops a display that is turned end for end.
- **Status LED.** A 3 mm diffused yellow LED, through a 1 kΩ resistor, behind a clear LEGO 1×1 round tile in the
  front of the shell.
- **Headers, housings and wire.** Two 20-way female strips, cut to 12 and 11 ways, hold the TinyS3 in its cradle.
  Eight 1-pin Dupont housings go on the PM board's 7-pin header and the AMS1117's pins. All other connections are
  28 AWG stranded wire, twisted and soldered into two splices under heat-shrink.

## Alternatives

| Part | What else would do |
|---|---|
| Inkplate 5 Gen2 | No drop-in. A different panel changes the display tray, the window and the frames, and the firmware needs an `IBoard` for it. |
| TinyS3 | An ESP32-S3 board with PSRAM and USB-C. Not the ProS3: its second regulator would put the SCD41 on the processor's rail. A different board changes the cradle and the pin table. |
| SCD41 | A Sensirion SCD4x breakout, or the SCD40, which costs less and is less accurate. Soldered sell an SCD43, which is a drop-in chip and more accurate, but its holes and sockets are in different places, so the chassis must change. |
| PMSA003I | The Plantower PMS5003 is the same sensor with a UART, not I²C, so it needs a serial port and its own driver. The Sensirion SPS30 is a better sensor. |
| BME688 | Adafruit 5046 is the same sensor on a STEMMA QT board. A BME680 fits the sockets and gives the same chip ID, but BSEC's gas index is different, so check the variant byte. |
| SHTC3 | Adafruit 4636, or an SHT4x breakout: a better part, which needs its own driver. |
| AMS1117-3.3 module | A 3.3 V regulator that takes 5 V in and carries 500 mA. A small buck module would not make the 0.19 W of heat that this LDO makes while the fan runs, but it needs its own pocket. |
| Magnetic pogo pair | An 8-pin pair with the same outline and pitch. The tray, the plinth and the key shape are drawn to this one. |
| LEGO tile | A clear 8 mm disc, or a drop of clear resin, sanded on the front. |

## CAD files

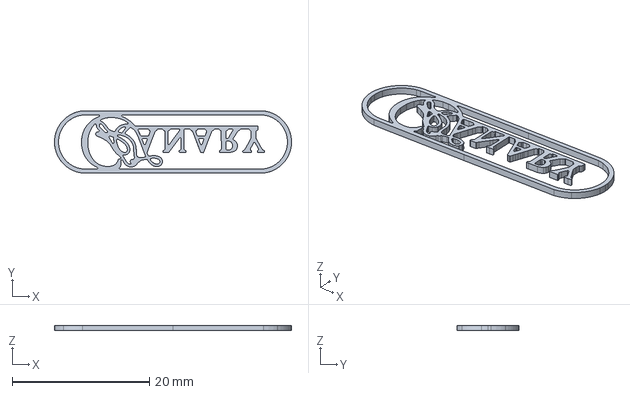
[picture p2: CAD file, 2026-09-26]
hardware/step/logo.step
34.5 x 9.09 x 0.8 mm

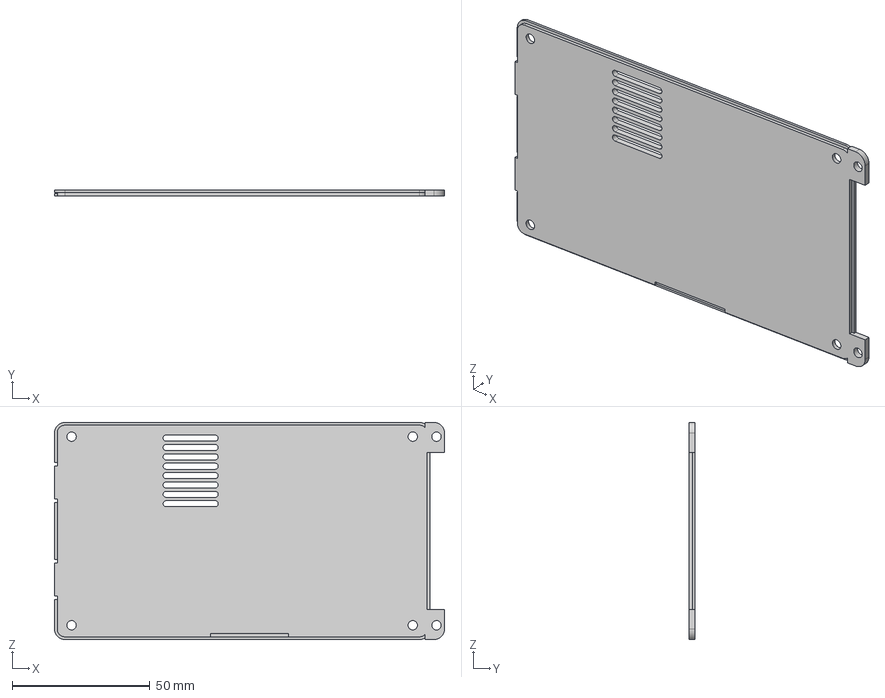
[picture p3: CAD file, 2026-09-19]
hardware/step/display-back-cover.step
141.5 x 2.00 x 78.8 mm

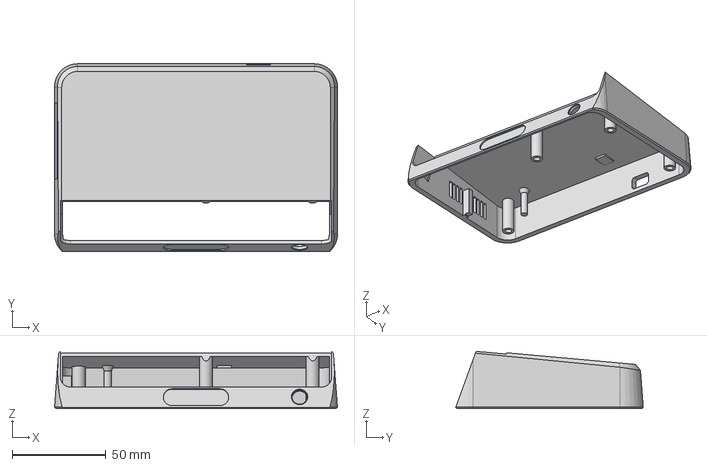
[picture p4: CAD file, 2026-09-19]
hardware/step/dock-shell.step
151.3 x 100.3 x 30.6 mm

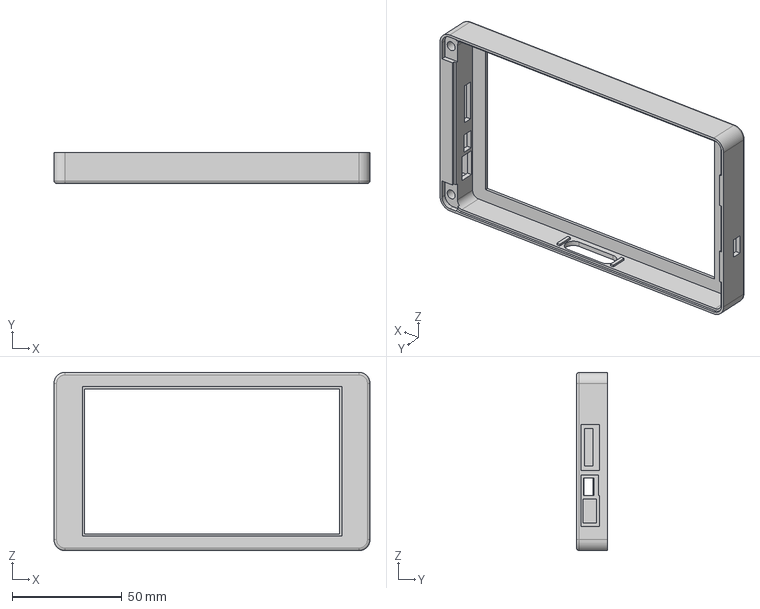
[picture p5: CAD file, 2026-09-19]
hardware/step/display-tray.step
143.9 x 14.1 x 81.2 mm

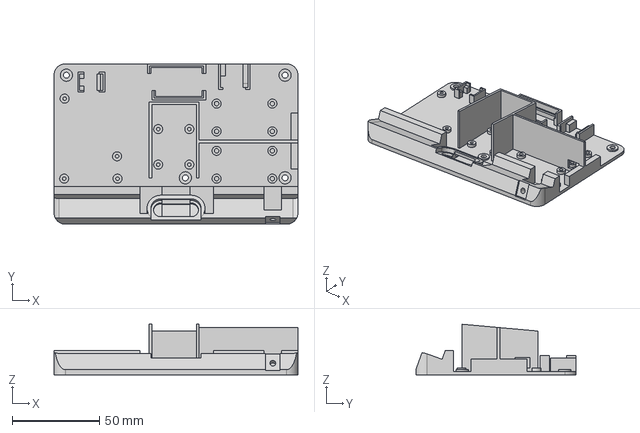
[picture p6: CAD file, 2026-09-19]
hardware/step/dock-chassis.step
139.5 x 91.7 x 28.9 mm

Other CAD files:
hardware/3mf/display-back-cover.3mf
hardware/3mf/display-tray.3mf
hardware/3mf/dock-chassis.3mf
hardware/3mf/dock-shell.3mf
hardware/3mf/logo.3mf
hardware/stl/display-back-cover.stl
hardware/stl/display-tray.stl
hardware/stl/dock-chassis.stl
hardware/stl/dock-shell.stl
hardware/stl/logo.stl

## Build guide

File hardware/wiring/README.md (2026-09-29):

# The wiring diagrams

This folder holds the circuit as YAML, one file for each run of wire. [WireViz](https://github.com/wireviz/WireViz)
makes the drawings in `hardware/images/` from it. Edit the YAML, never the PNG.

```sh
pip install wireviz          # and graphviz: brew install graphviz
hardware/wiring/render.sh    # writes the drawings in hardware/images/ again
```

- `render.sh` turns WireViz's layout top to bottom, and runs `dot` itself. WireViz's own left-to-right layout is too
  wide and too short to read on a page.
- **Keep each drawing near 1200 px.** That size stays legible at page width. One run of wire per file does this. Do
  not draw a chain of identical cables: say it in a sentence.
- **Give every wire a colour, and never `WH`.** A white line on a white page looks like no wire. Red is a supply,
  black is ground, blue is SDA and yellow is SCL. For other wires, use a colour that stands out.
- [assembly.md](../assembly.md) lists the same joints, under "Appendix: every joint". When you change one, change
  the other.

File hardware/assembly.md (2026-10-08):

# Building a CANARY

CANARY is two boards in one desk enclosure: a **dock** that reads the room, and a **display** that shows it. This
guide builds both, in the order the parts go in.

The finished device

## Before you start

[bom.md](bom.md) lists every part and where to buy it. Have them all on the bench, and the printed parts in
front of you, before step 1.

**Tools**

- A soldering iron with a fine tip. It also sets the heat-set inserts.
- Solder, 28 AWG stranded wire and heat-shrink.
- Wire strippers, side cutters and a small flat file.
- A crimp tool and eight 1-pin Dupont housings.
- A multimeter.
- Superglue, fine sandpaper, and screwdrivers for M2, M2.5 and M3.
- A 3D printer with a 0.4 mm and a 0.2 mm nozzle.

Every joint is soldered by hand to a header leg, a 1 mm pad or another wire. Nothing is surface-mount work. Set
aside a full day, and expect step 8 to take half of it.

**Reading the drawings.** Red is 5 V or 3.3 V, and black is ground. Blue is SDA and yellow is SCL, as on a Qwiic
cable. Any other colour only tells two wires apart: use what you have.

**Work in this order.** Each step leaves the next one reachable. Going back means taking the dock apart, and the
TinyS3's strips are glued in. Each step draws its own wires, so the circuit comes together as you do.

1. [Print the parts](#1-print-the-parts)
2. [Set the heat-set inserts](#2-set-the-heat-set-inserts)
3. [The TinyS3 on its strips](#3-the-tinys3-on-its-strips)
4. [The USB-C socket](#4-the-usb-c-socket)
5. [The status LED](#5-the-status-led)
6. [The sensor boards](#6-the-sensor-boards)
7. [The pogo connector](#7-the-pogo-connector)
8. [Wire the dock](#8-wire-the-dock)
9. [The display](#9-the-display)
10. [Close the dock](#10-close-the-dock)
11. [The logo](#11-the-logo)
12. [First power-up](#12-first-power-up)

## 1. Print the parts

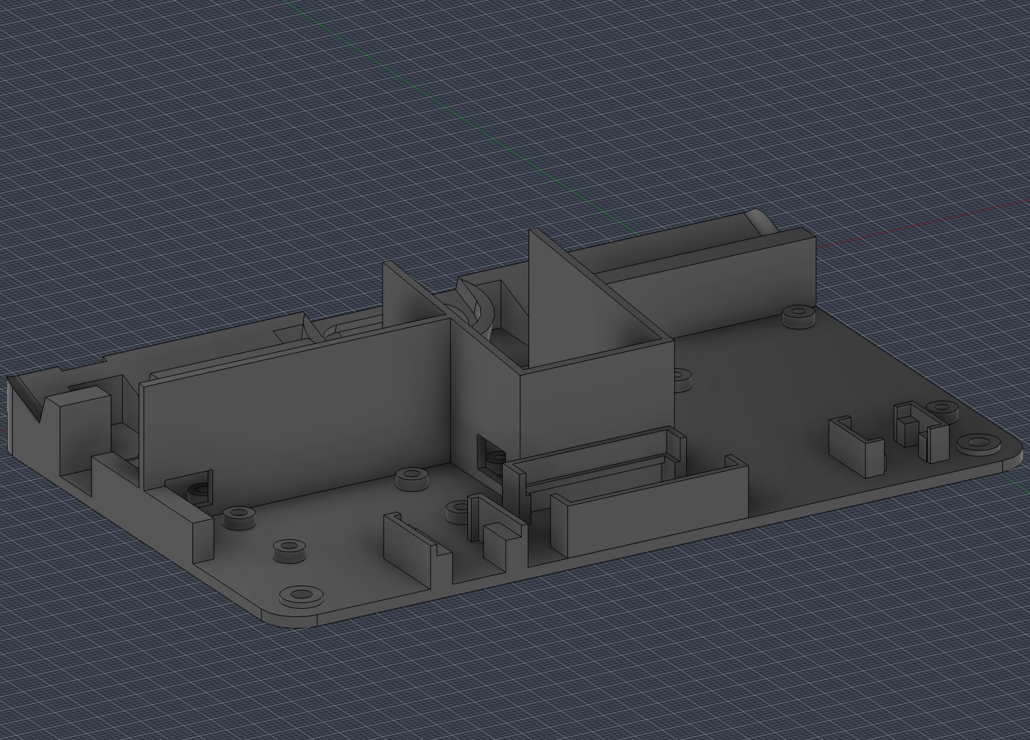
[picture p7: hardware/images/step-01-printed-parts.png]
The dock chassis, straight off the printer


Five parts, in `3mf/` or `stl/`. The files are already in print orientation, and no part needs supports. Print
each part only in that orientation.

1. Print the display tray, the display back cover, the dock chassis and the dock shell in PLA+ with a 0.4 mm nozzle.
2. Print the logo in white with a 0.2 mm nozzle, on its own plate.

## 2. Set the heat-set inserts

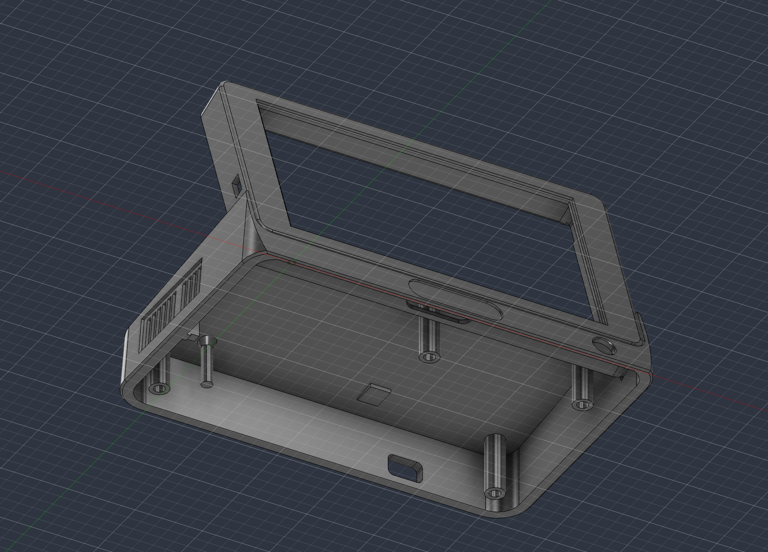
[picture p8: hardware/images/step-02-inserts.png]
The shell from below: the four pillars that take the inserts


Six M3 inserts in Ø 4.0 × 6.0 mm holes: four in the dock shell's internal pillars, two in the display tray's thick
wall at the corners.

1. Push each one in square, with the iron at about 200 °C.
2. Stop when its top is flush.

**Square matters.** A crooked insert pulls its screw out of line and splits the boss.

## 3. The TinyS3 on its strips

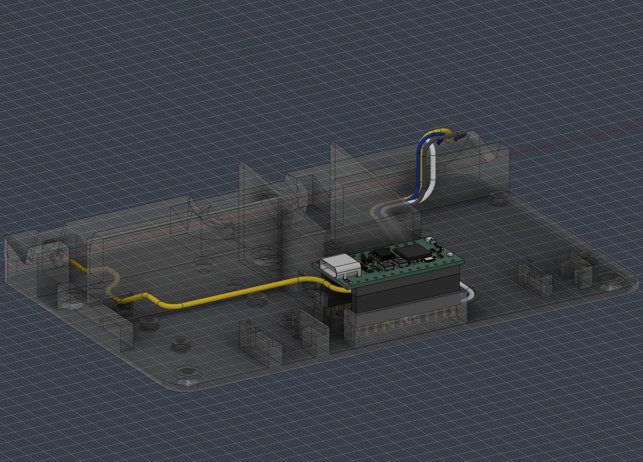
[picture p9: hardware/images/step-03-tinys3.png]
The strips, the TinyS3 and its seven wires, in the empty chassis


*The chassis is drawn see-through, so you can follow the wires. Everything else in the dock hangs off these seven.*

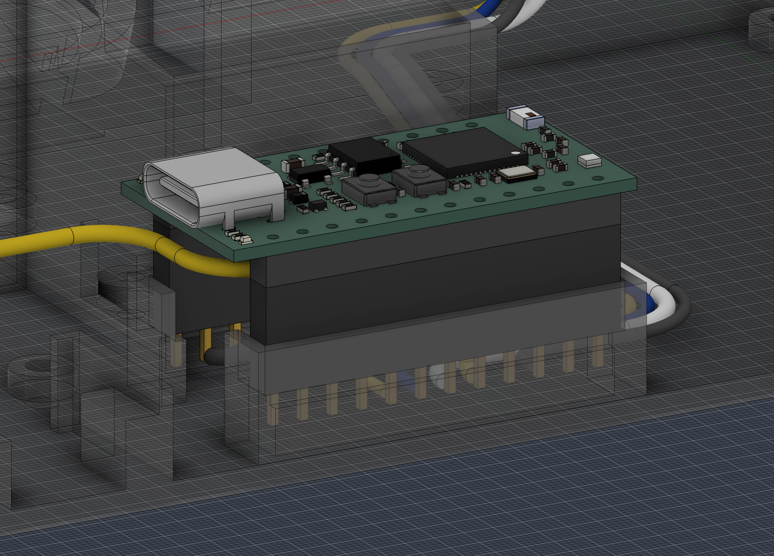
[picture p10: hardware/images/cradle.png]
The cradle close up: the board on its strips, the legs and the channel below


The TinyS3 plugs into two female header strips, and every dock wire is soldered to a leg of a strip. The strips
are then glued into the cradle on the chassis floor. **Solder and test every wire before any glue goes on** — to
change one afterwards, print a new chassis and wire it again.

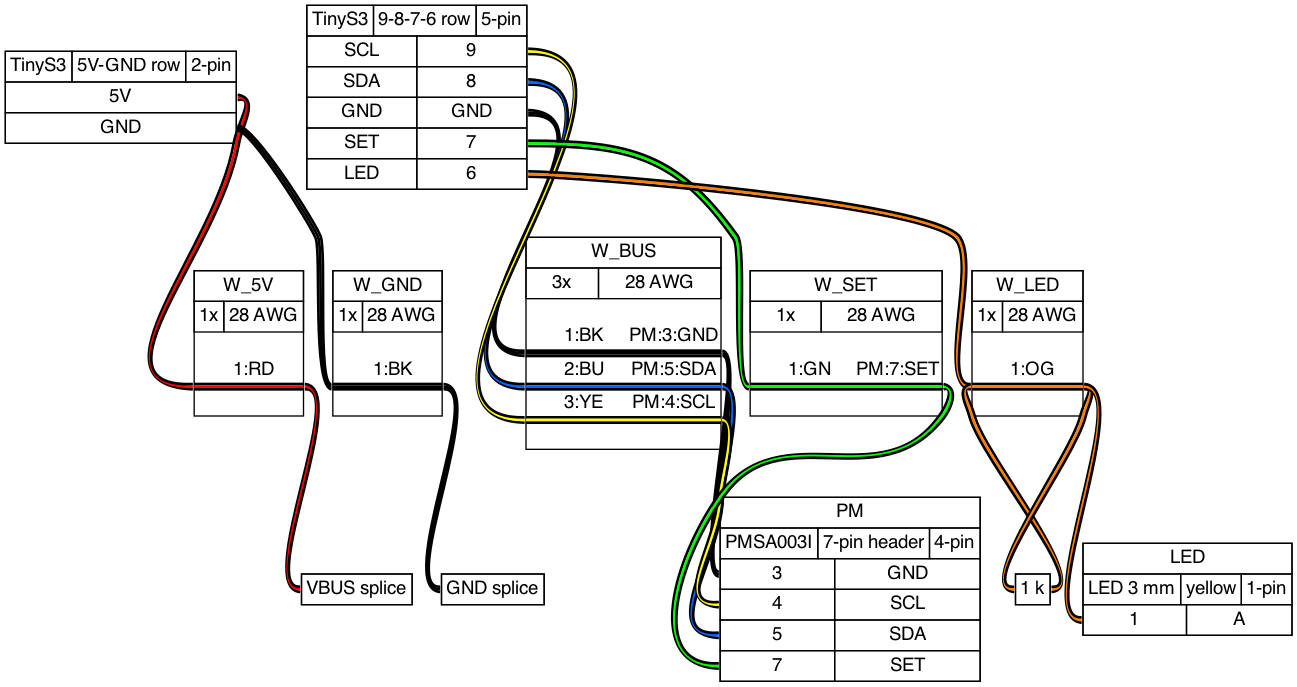
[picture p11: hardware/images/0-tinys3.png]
Every wire on the TinyS3, and where each one ends


Seven wires. Two come off the row marked **BAT · GND · 5V · 3V3**, and five off the row marked **9 · 8 · 7 · 6**.
You solder the TinyS3 end now; the far ends land in steps 4 to 8.

Do all of it on the bench, away from the printed parts.

1. Cut a 12-way strip for the 9-8-7-6 row and an 11-way for the other, from standard 20-way strips. Cut through
   the next way, then file the cut end flat.
2. Push both strips fully onto the TinyS3's pins, and leave the board in them until the glue has set. The board
   is what holds the two strips parallel and the right distance apart.
3. Tin only the seven legs in the drawing, and the ends of the wires.
4. Solder each wire to the **lower half** of its leg, with the wire pointing into the channel between the strips.
5. Bend each wire along the channel, towards the end of the cradle nearer the board it feeds.
6. Look at every joint. No solder may touch the next leg, 2.54 mm away, and nothing may stand past a strip's
   outer face.
7. Meter each wire against its pin on the top of the board.
8. Dry-fit: lower board, strips and wires into the cradle, legs first. Each strip rests on its ledge and its two
   end blocks, with the joints hanging in the channel. Lead the wires out at the cradle's ends.
9. Lift it out, glue the ledges and end blocks — away from the legs — put it back and press it down.
10. Leave slack in every wire, so the board still lifts straight off the strips for an install over USB.

**Leave the four end legs bare.** They clear the cradle's end blocks by 0.28 mm.

## 4. The USB-C socket

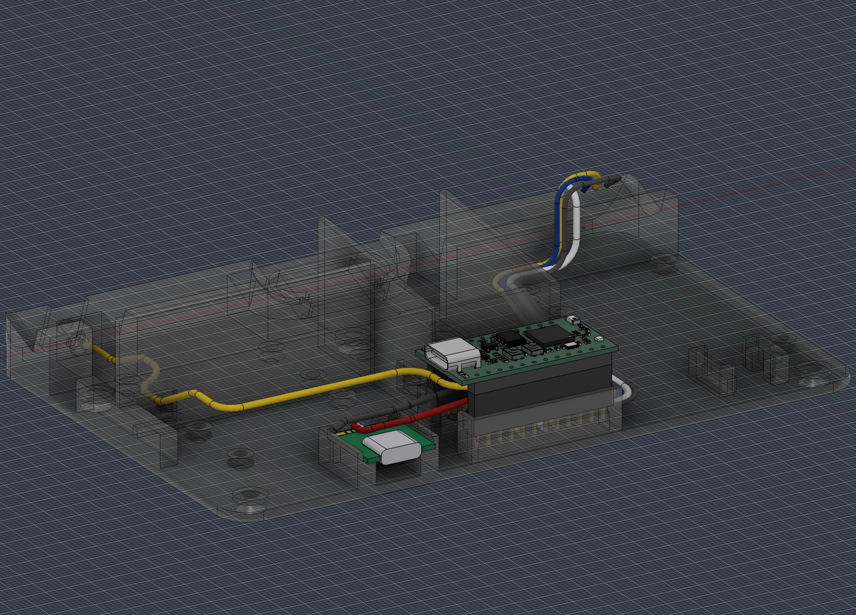
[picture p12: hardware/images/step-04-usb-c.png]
The socket added, with its two stubs reaching the channel


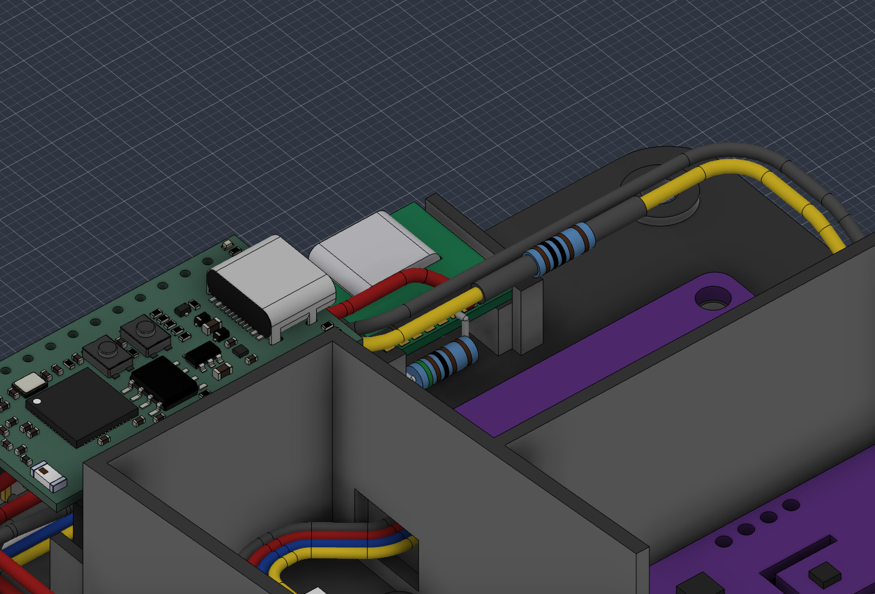
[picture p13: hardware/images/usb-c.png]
The holder close up, with the CC resistors


The breakout lies flat by the rear wall, its receptacle in the wall's only opening. Its two 5.1 kΩ resistors are
what make a USB-C to USB-C cable or charger supply any power at all.

1. Solder the two resistors first, on the bench. B5's lies under the board in front of the left ear's pad, its
   leads bent onto B5 and the underside's G pad. A5's hangs in front of the board's edge: one lead up round the
   edge onto A5, the other back under the board onto that same G pad, soldered with the first in one go.
2. **Meter the wide end pad on the top face before you use it as ground.** If it is not ground, take the GND
   stub to the G pad underneath instead, and cut a slot in the holder for it.
3. Solder the VBUS stub to the V pad and the GND stub to the wide end pad.
4. Lower the module into its holder, ears on their seats between the side guides and against the corner stops.
5. Glue each ear to its seat and its side guide.

## 5. The status LED

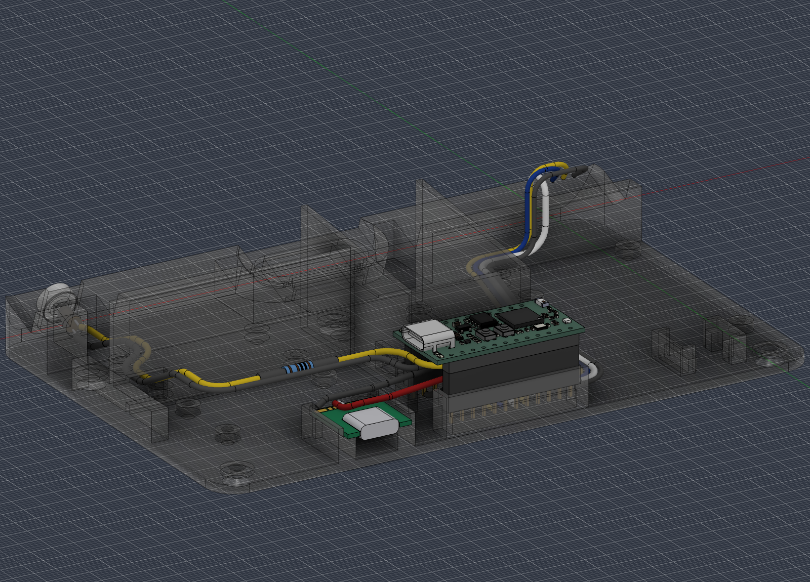
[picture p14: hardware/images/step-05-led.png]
The LED and its tile added, at the front of the shell


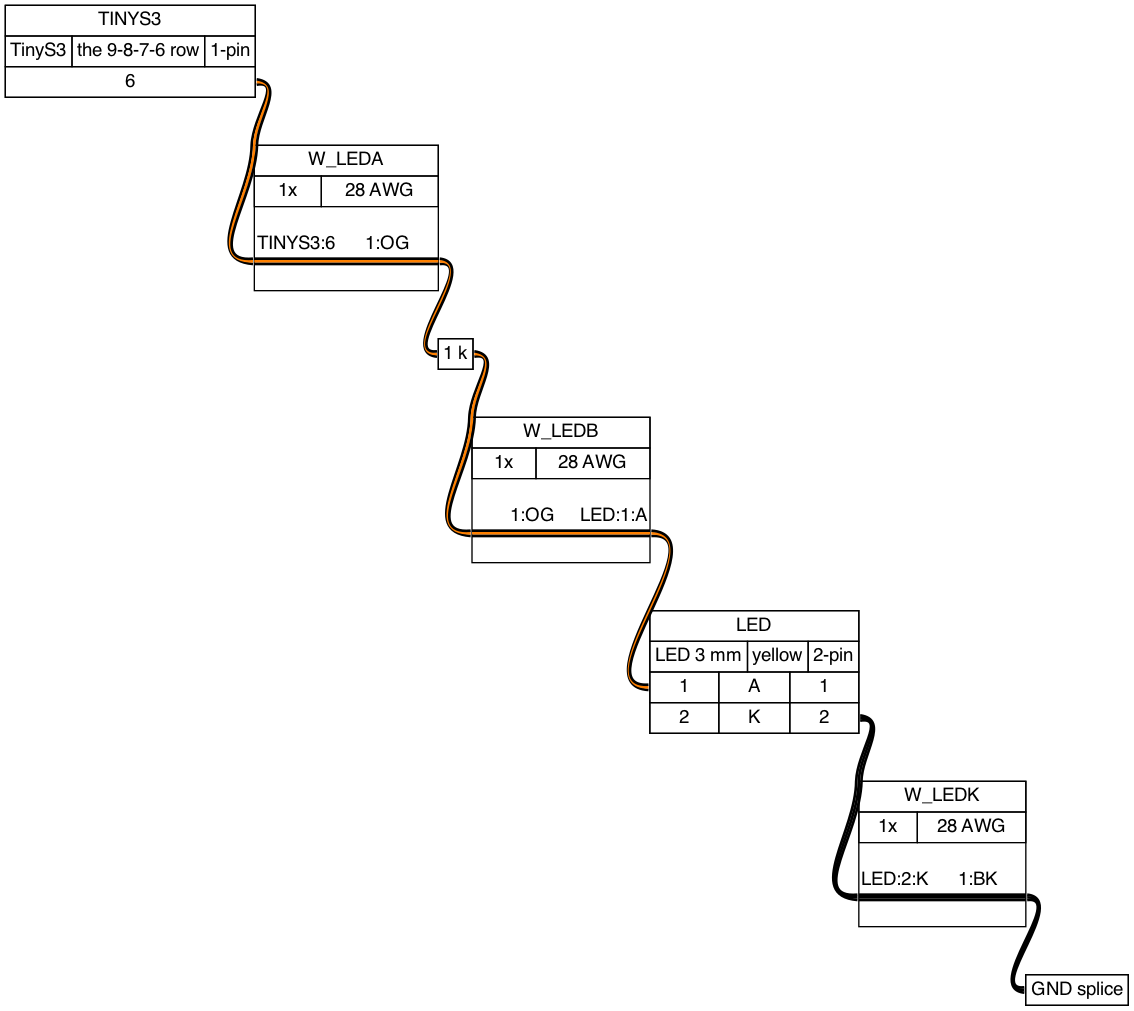
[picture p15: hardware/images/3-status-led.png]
The status LED


It goes in now because it is reached from a pit under the display. Once the display is on, you cannot get at it.

1. Sand the tile's front, so it glows evenly instead of showing the LED as a dot.
2. Press the tile into the shell's front face, flush.
3. Solder the LED's two wires, with the 1 kΩ resistor spliced into the anode's and heat-shrink over each joint.
4. With the display off, lower the LED into the pit, push it forward until its rim stops on the step, and glue it.
5. Run its wires back along the pit's floor into the bay.

## 6. The sensor boards

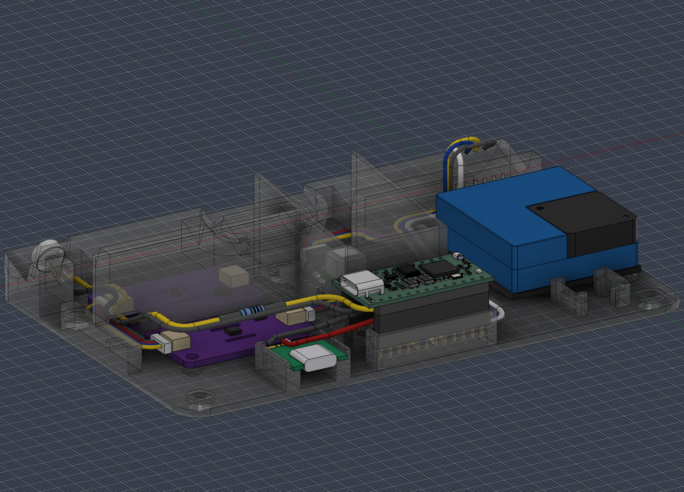
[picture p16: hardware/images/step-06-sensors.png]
All four boards in the bay, chained


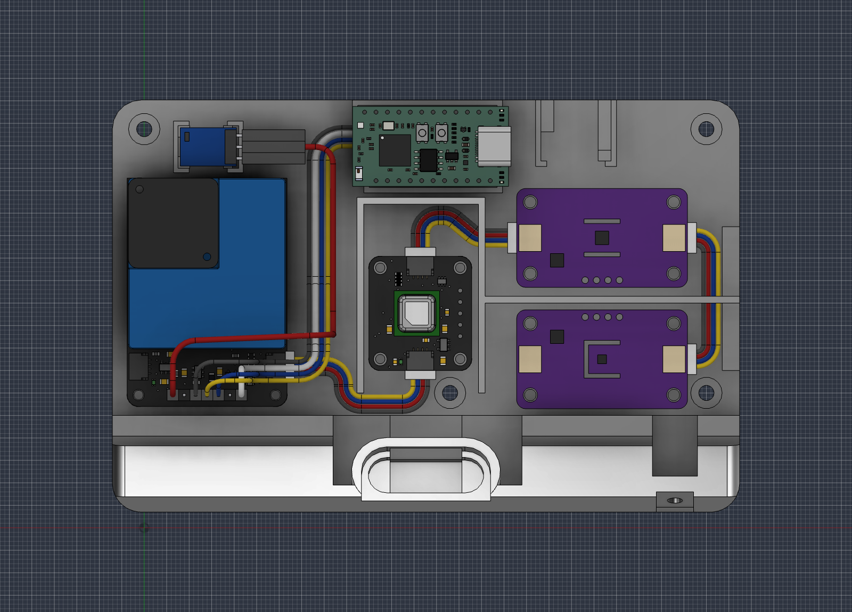
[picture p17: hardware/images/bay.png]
The bay from above: the chain board to board, and the run back to the TinyS3


The PM board comes first in the chain: it draws the most, and the whole chain's ground returns through its
header. The SHTC3 comes last, at the open right-hand corner, farthest from the fan, the BME688's heater and the
TinyS3 — it is the temperature reference.

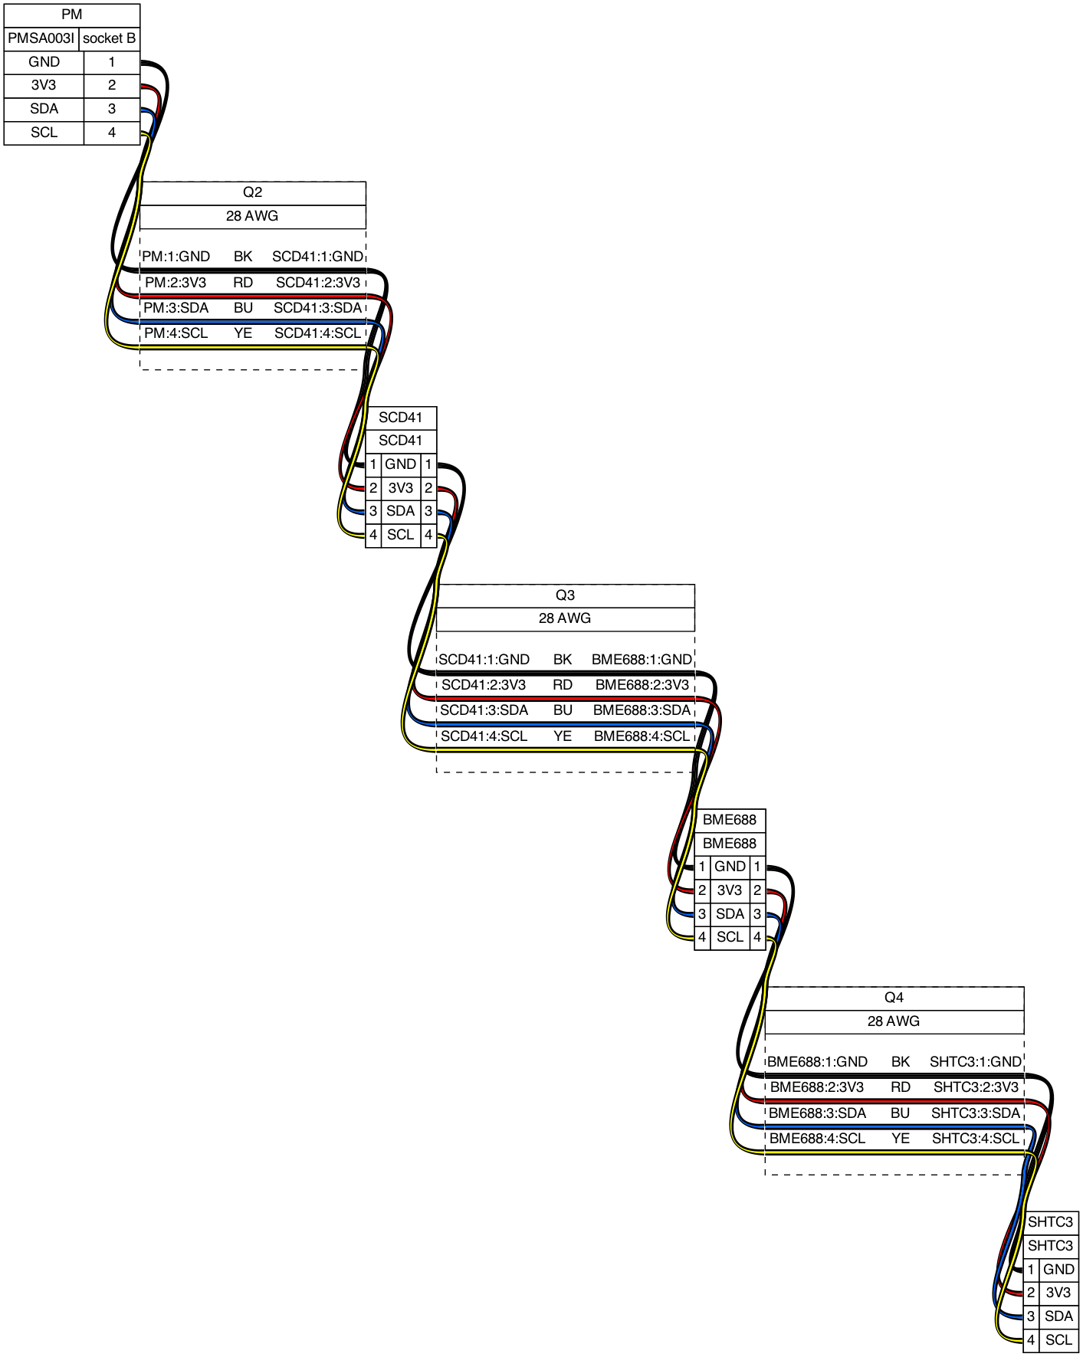
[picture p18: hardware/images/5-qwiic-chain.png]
The Qwiic chain, in order


1. Screw each board to its bosses, two screws each: M2 × 4 for the PMSA003I and the SCD41, M2.5 × 4 for the
   BME688 and the SHTC3. Stop as soon as the board is held; a self-tapper that bottoms out splits its boss.
2. Join the boards with three stock Qwiic cables: **PM socket B → SCD41 → BME688 → SHTC3**. Every board has two
   sockets wired in parallel, so either one will do.
3. Use a 45 mm cable, then a 30 mm, then a 40–45 mm.
4. Lay each ribbon flat in its lane in the chassis floor. Let it bend as a ribbon does, and do not twist it.
5. Thread the last plug down the right-hand lane **inboard of the guide rib**, then let the ribbon settle against
   the rib. The shell then drops on without touching it.

**Leave the PM board's socket A empty.** It faces a wall 5 mm away, where no plug fits. The bus reaches that
board on its header instead, in [step 8](#8-wire-the-dock).

## 7. The pogo connector

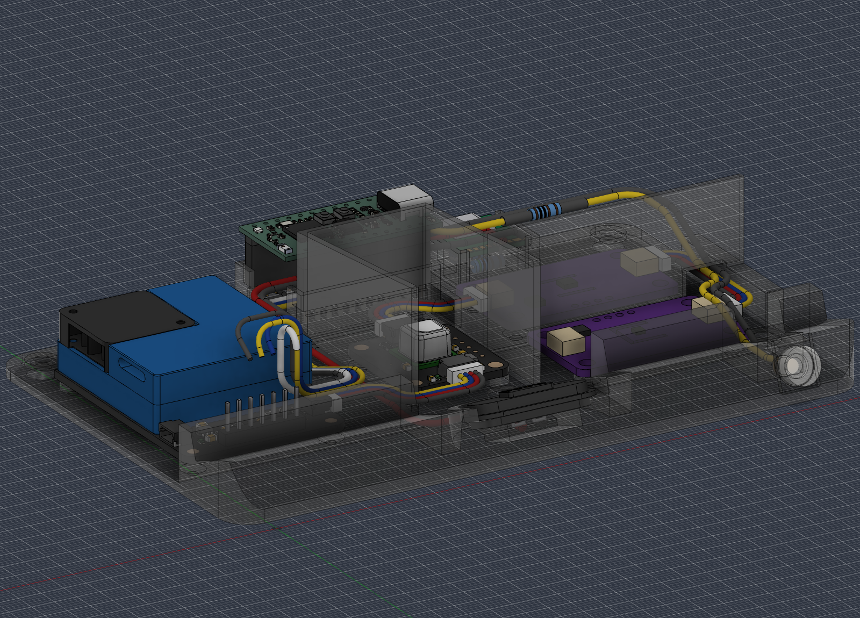
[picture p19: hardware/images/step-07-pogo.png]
The pogo female in its plinth at the front, and its two wires back to the splices


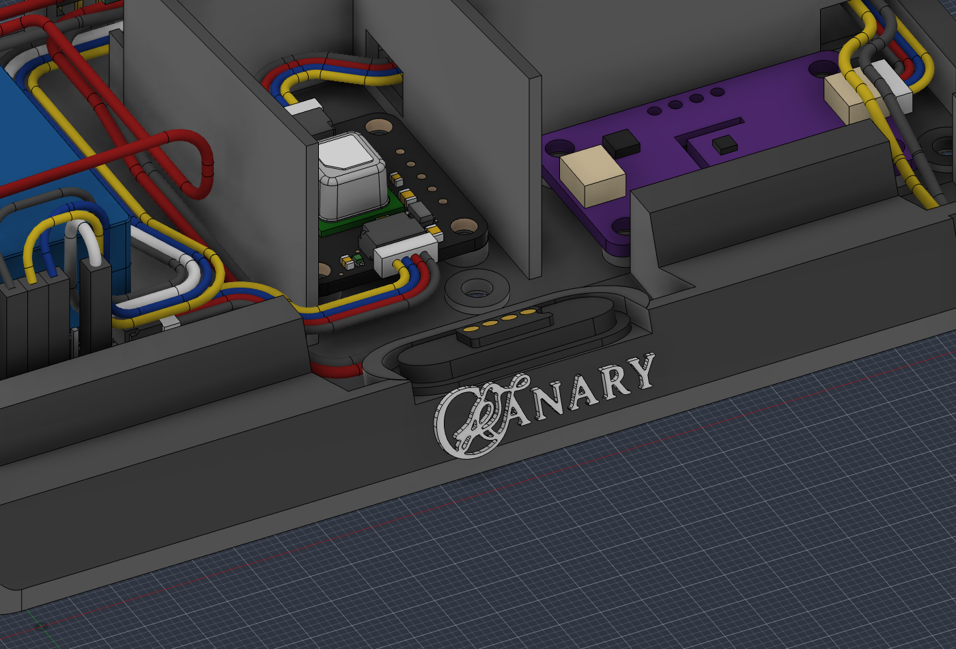
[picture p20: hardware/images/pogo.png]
The trench and the plinth, close up


An 8-pin magnetic pair joins the display to the dock, and carries only power. The pins are 0.5 mm across
*(measured)*, so each carries about 1 A. At power-on the device takes 1.07 A
([parts.md](parts.md#measured-peaks)). So each net crosses on two contacts, joined by a bare bridge, and four
contacts are not used.

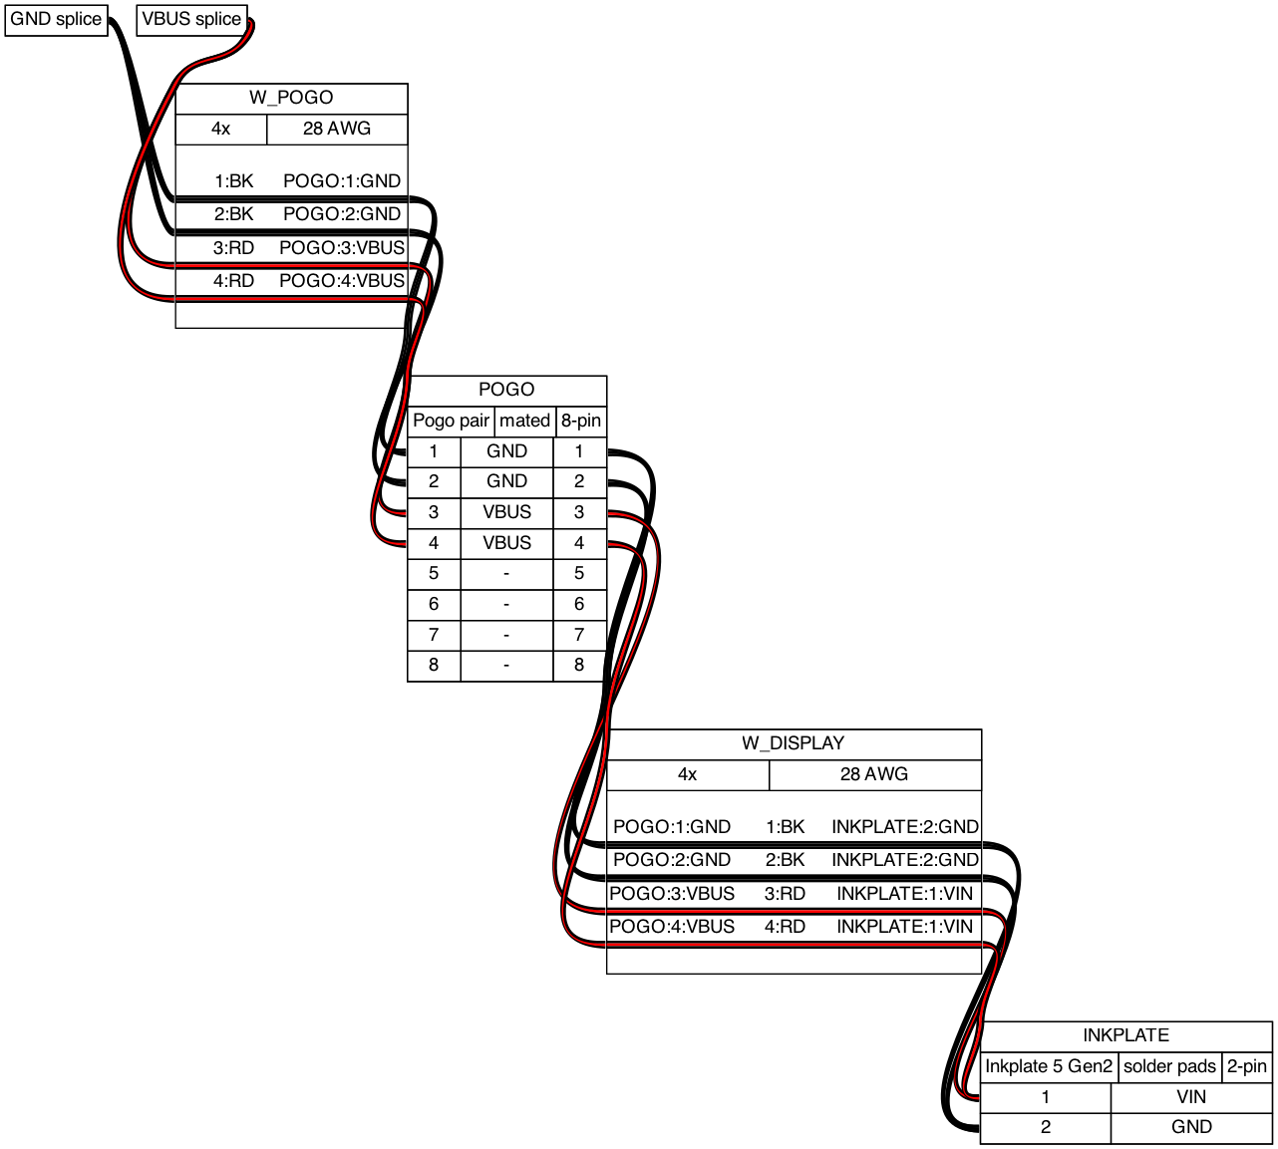
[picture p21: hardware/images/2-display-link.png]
The splices, the pogo pair and the display


1. Solder both halves on the bench, before either goes into its shell. GND goes on the two contacts nearest the
   display's USB-C end, VBUS on the other two.
2. Lay each stripped wire end across its pair of tails, and solder the bridge across the pair in one go.
3. **Fit the Inkplate before the male half.** The male's back band sits at the board's bottom edge, and with the
   connector in place the board cannot pass it.
4. Glue the male's lip to the display's cavity floor, between the two locating ribs.
5. Drop the female into the dock's plinth, its lip on the ledge, and glue it.

The halves nest, and the contact block's outline keys them, so a display turned end for end will not close.

## 8. Wire the dock

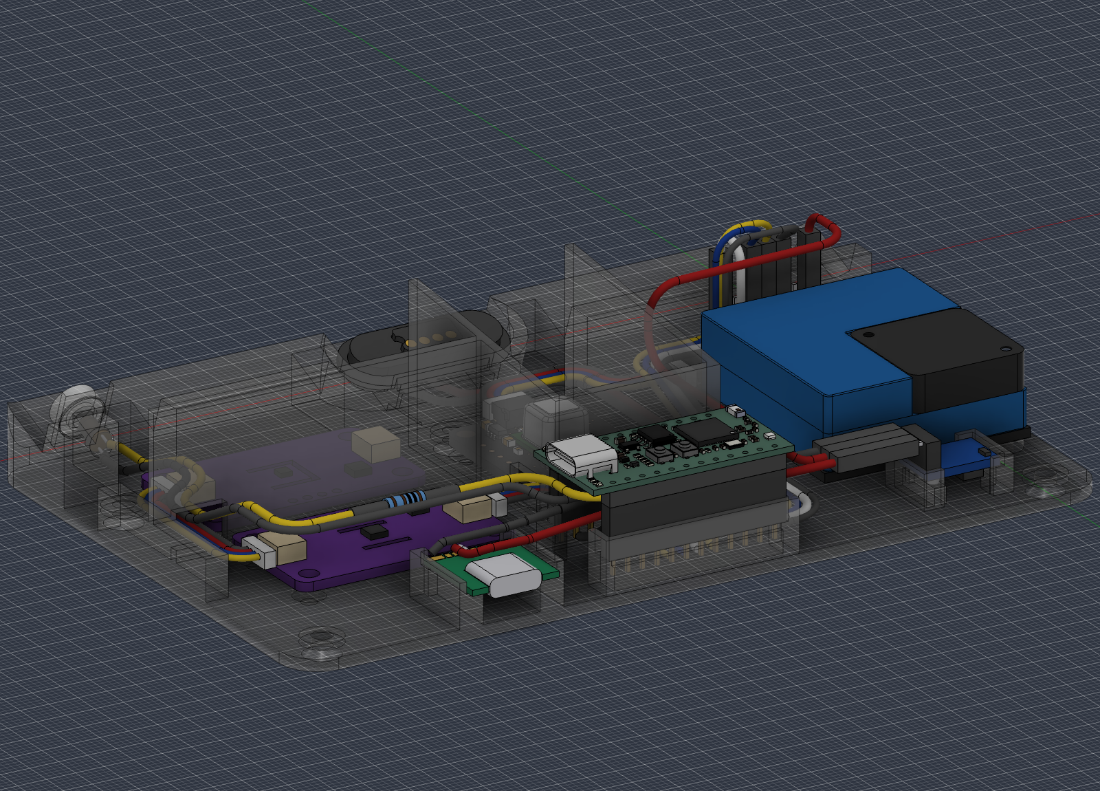
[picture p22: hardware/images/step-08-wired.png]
The dock fully wired: splices, regulator and every remaining wire


*This is what the dock looks like when the step is done.*

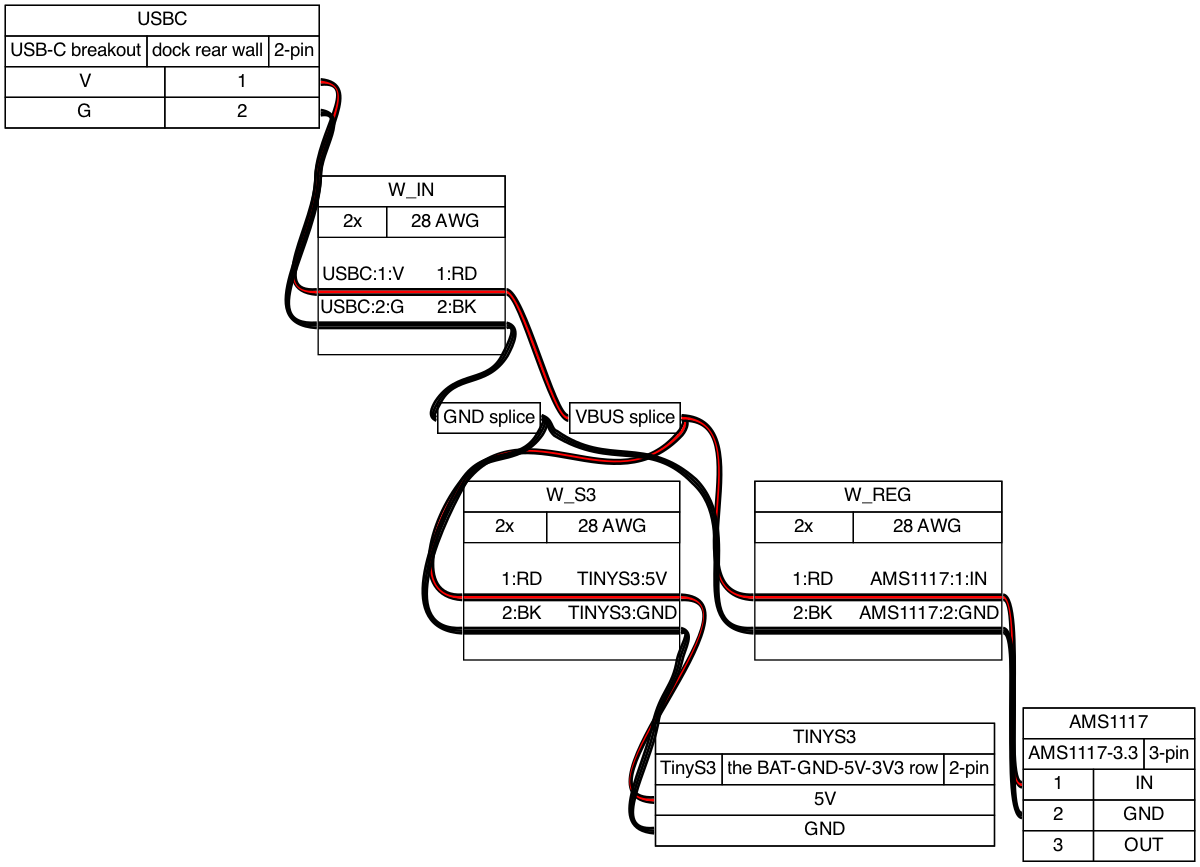
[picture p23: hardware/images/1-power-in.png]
Power in, from the socket to the two splices


5 V comes in at the USB-C socket and goes three ways: to the TinyS3, to the AMS1117 that makes the sensors'
3.3 V, and up two pogo contacts to the display. Each pad, leg and crimp takes only one wire. So each net meets at
**one splice** in the middle of the TinyS3's channel: twisted end to end, soldered and heat-shrunk. The branches
leave from both ends of it.

The channel is the dock's duct. Every wire that crosses behind the sensors runs through it, in layers, so that no
wire crosses another. Wires that go the same way are bundled, so that their bends stay concentric.

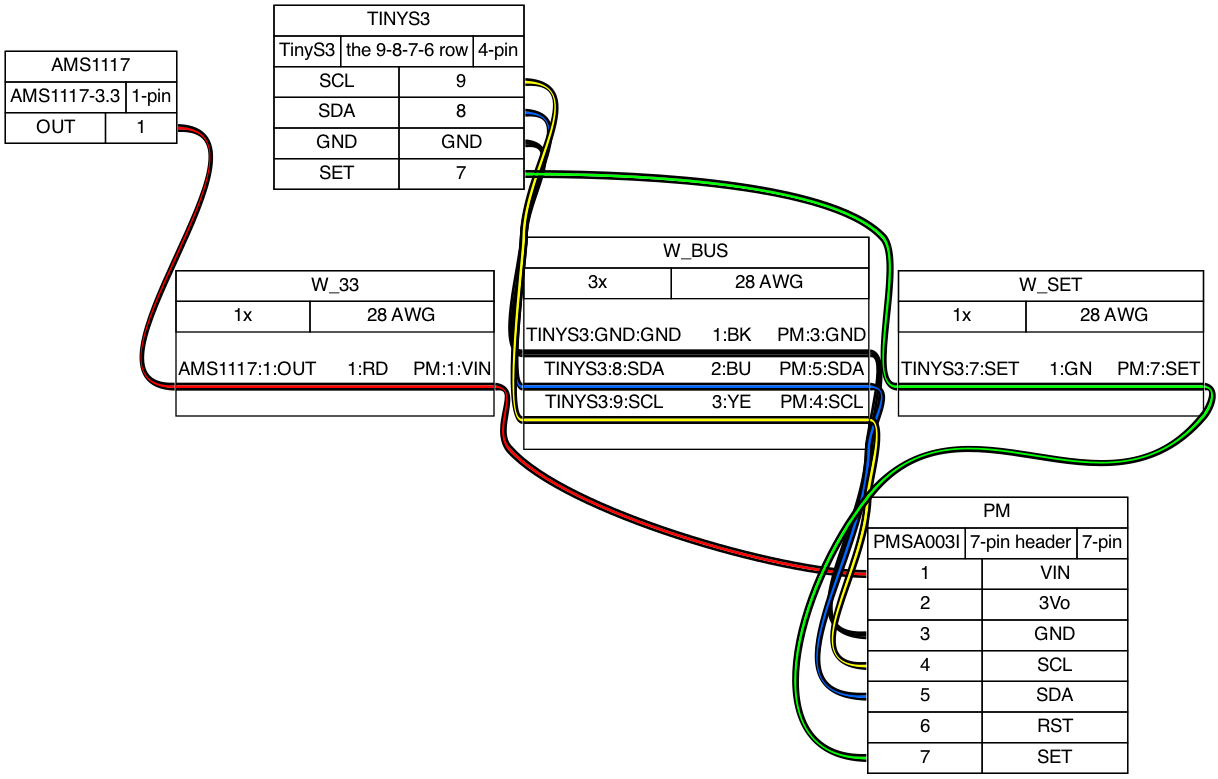
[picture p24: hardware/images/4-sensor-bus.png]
The TinyS3 and the regulator to the PM header


1. **Make the two splices** in the middle of the channel, and bring the USB-C socket's two stubs into the channel
   to reach them.
2. **From the VBUS splice**, run wires to the TinyS3's 5V leg, the AMS1117's VIN and the pogo pair. **From the GND
   splice**, run wires to the TinyS3's GND leg, the AMS1117's GND, the LED and the pogo pair.
3. **The pogo pair.** Each wire meets its tail end-on from below, in the chamber under the plinth, and leaves into
   the trench. There the two become one bundle: left along the trench, up between the PM board and the SCD41
   compartment, and along the channel to the splices.
4. **The AMS1117.** Its silkscreen reads **GND, OUT, VIN** along the header. The middle pin is OUT on every one
   of these modules, so use it to tell the two ends apart, and check each end before you push a wire on. **5 V on
   the GND pin destroys the part.** Its VIN and GND wires run straight along the channel into their housings, the
   shortest wires in the dock. **AMS OUT → PM VIN** leaves the middle housing, crosses the module under the skin,
   and drops into the PM header's VIN housing.
5. **The PM group.** The three conductors of cable 1, and SET, leave their legs, become one bundle along the
   channel, and run up and along the front of the bay.
6. **Enter every housing from the top, coming over the row from behind.** The display's back cover leans over the
   header from the front, so no wire can turn into a housing from that side. SET's housing is last in the row, so
   its wire hairpins over it — the tightest bends in the dock.
7. **The LED pair.** Back over the SHTC3, up the right-hand ribbon lane, past the BME688 and across the bay. At
   the far side they part: the signal into the channel and onto the TinyS3's leg, the ground onto the GND splice.

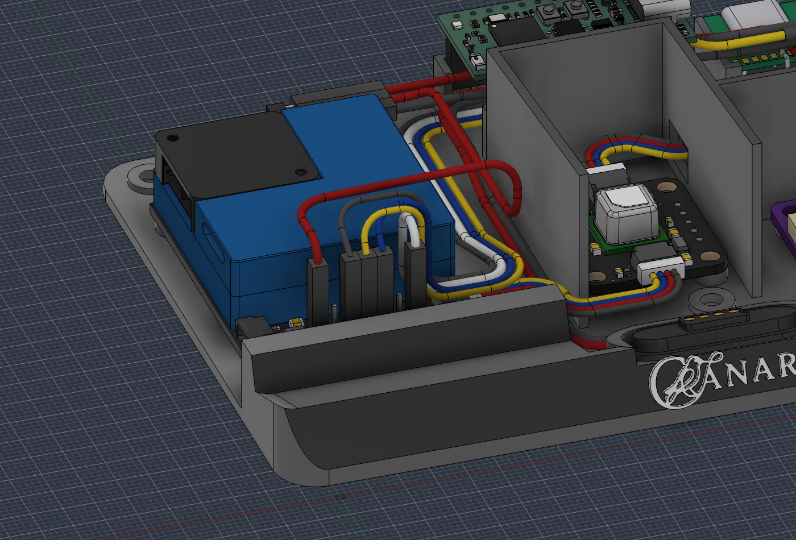
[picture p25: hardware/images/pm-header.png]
The PM board's header, where four wires arrive over the housings


**Cable 1 is a Qwiic cable used for its conductors.** Cut both plugs off, solder GND, SDA and SCL to their TinyS3
legs at one end, and crimp them into Dupont housings at the other. **Cut the 3V3 conductor back and insulate both
ends** — connected, it would feed the chain from the TinyS3's regulator as well as the AMS1117. On a standard
cable 3V3 is the red wire; find it in a plug before you cut the plugs off.

[Appendix: every joint](#appendix-every-joint) lists all seventeen in one table, to tick off as you go.

## 9. The display

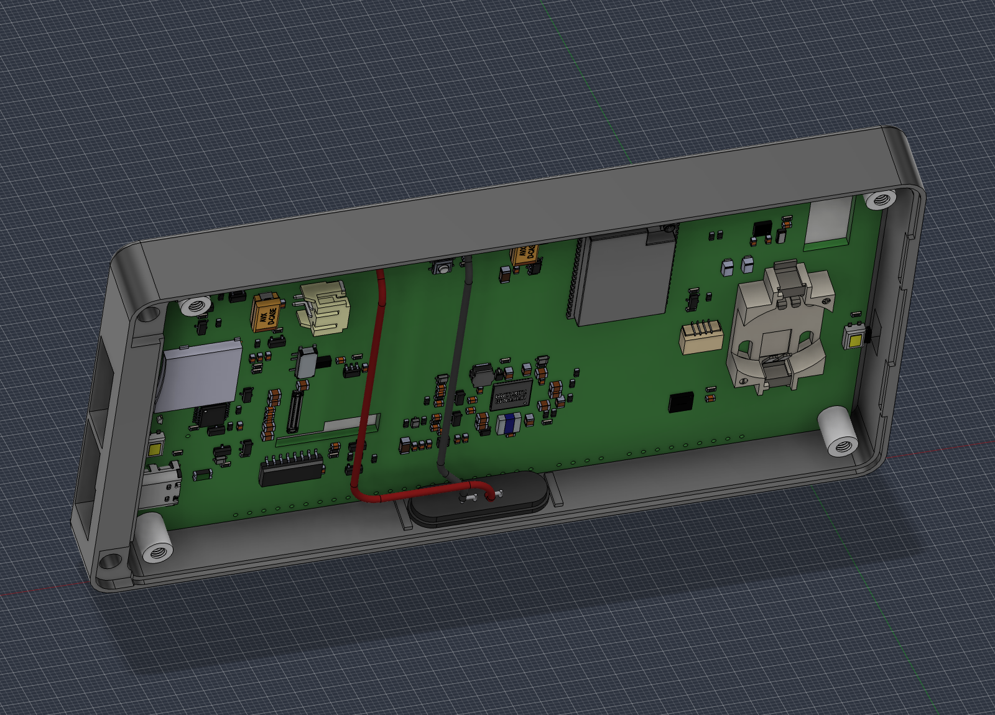
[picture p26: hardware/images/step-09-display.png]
The Inkplate in its tray, both wires run to the pogo male


Two wires and nothing else. 5 V on the Inkplate's VIN pads is Soldered's own answer for this circuit
([forum thread 1934](https://community.soldered.com/t/externally-powering-the-inkplate-5v2-with-5v/1934)), and
the board's own USB-C sits behind the dock's side wall while the display is docked. So no diode guards against
back-feed: nothing can feed the display from a computer while it is docked. An enclosure that opens the socket
needs one.

1. Solder VBUS to PAD3 (VIN) and GND to PAD5, the 4 × 4 mm pads on the top edge above the reset button. Both are
   on the component side, which faces the cover.
2. Run each wire down the board in its own column, behind it: the ground's between the bulk capacitor and the
   reset button, the other clear of everything.
3. Take both along the bottom edge to the pogo male's tails. Use the **tail row nearer the cover** and leave the
   other row empty. GND reaches the outermost tail in line; VBUS runs under the two GND tails and rises onto its
   own.
4. Put the Inkplate in from the back, enter the cover's two tongues into the slots in the thin wall, and swing
   the cover down onto the board's four standoffs.
5. Drive four M3 × 6 into the standoffs, and two more through the cover's ears into the tray's inserts.

## 10. Close the dock

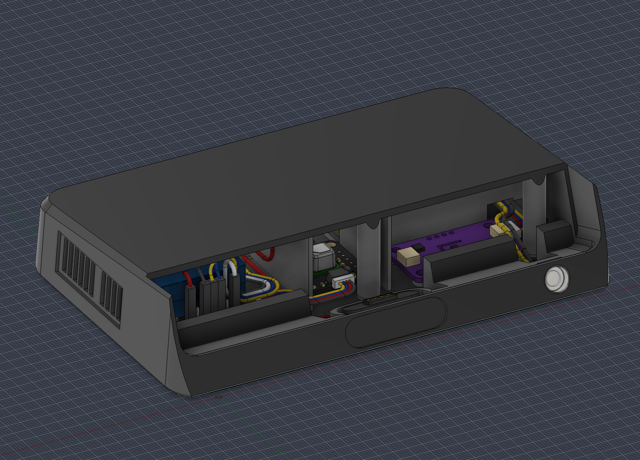
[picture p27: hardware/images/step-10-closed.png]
The shell on, the dock shut


1. Lay every wire down into its lane, so nothing stands above the skin's underside.
2. Drop the shell on.
3. Drive four M3 × 8 countersunk screws up from underneath into the inserts.

**A screw that meets no thread means the shell is not seated.** Lift it and look for a wire over a pillar.

## 11. The logo

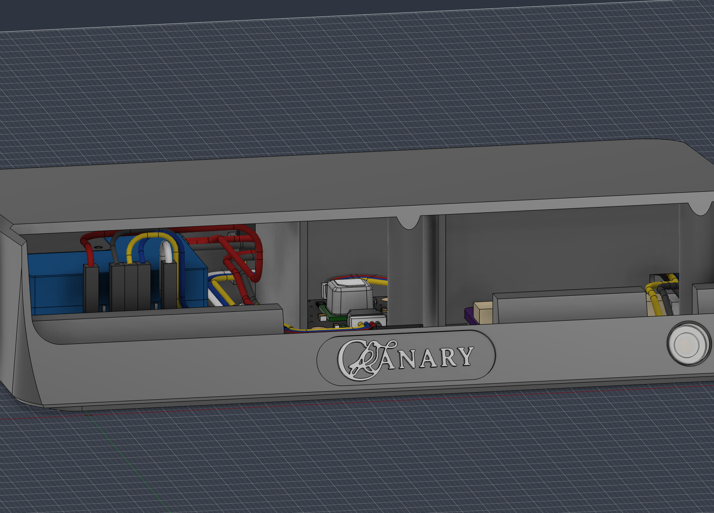
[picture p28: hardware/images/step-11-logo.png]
The logo in the recess in the front face


One white piece, 0.8 mm thick, in the pill recess in the shell's front face: a border, the emblem and the
letters, and a line under the letters that holds them together.

1. Put a thin layer of glue on the back of the logo.
2. Set it into the recess, the right way up.
3. Press it flush with the face, and hold it until the glue takes.

## 12. First power-up

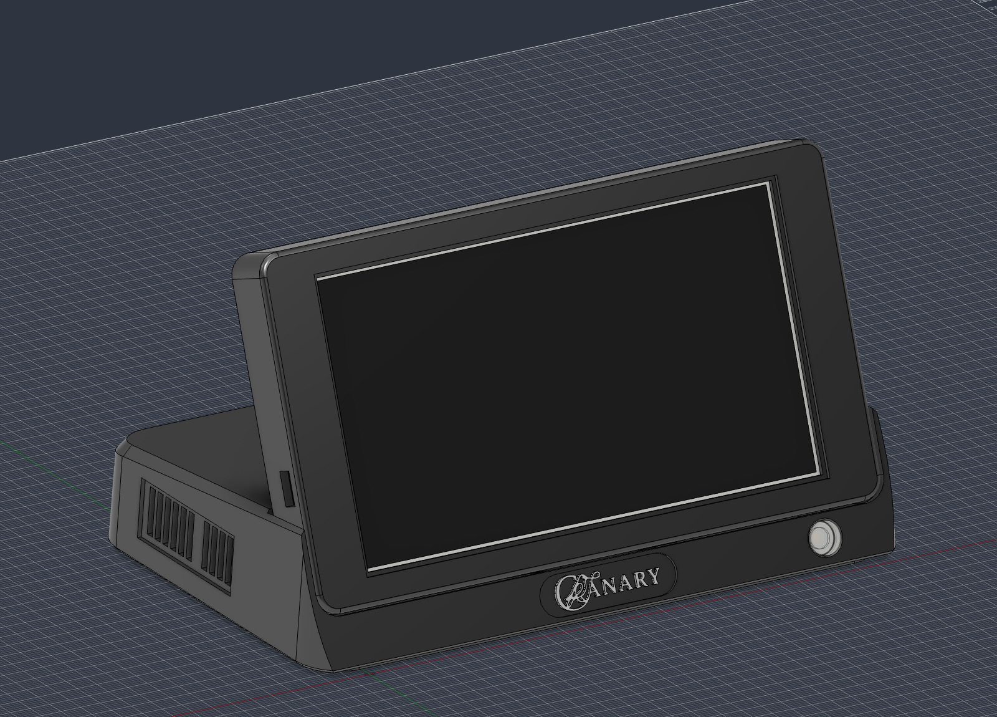
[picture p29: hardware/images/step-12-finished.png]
Built


The server must run, and both boards must have their first install:
[README.md, steps 1 and 2](../README.md#build-one). Every page and every later firmware then comes from the server.

1. Plug one USB-C cable into the dock. It powers both halves.

The LED then shows the dock's state. By default:

| LED | State |
|---|---|
| Fast pulse | Booting |
| Slow pulse | Running |
| Flash every second | Something is wrong. The Boards page says what. |
| Double flash | The air is poor |
| Slow swell | A sensor calibrates |

The Dock tab of the server's Settings page sets these patterns.

## Appendix: every joint

| # | From | To | Wire |
|---|---|---|---|
| 1 | USB-C socket **V pad** | VBUS splice | 28 AWG, soldered |
| 2 | USB-C socket **G pad** | GND splice | 28 AWG, soldered |
| 3 | VBUS splice | TinyS3 **5V** | 28 AWG, soldered to the leg |
| 4 | GND splice | TinyS3 **GND**, the 5V row | 28 AWG, soldered to the leg |
| 5 | VBUS splice | AMS1117 **VIN** | 28 AWG, Dupont at the AMS1117. Read the silkscreen: **GND, OUT, VIN** |
| 6 | GND splice | AMS1117 **GND** | 28 AWG, Dupont at the AMS1117. The opposite end from VIN |
| 7 | VBUS splice | pogo female, two contacts | 28 AWG, soldered; a bare bridge joins the pair |
| 8 | GND splice | pogo female, two contacts | 28 AWG, soldered; a bare bridge joins the pair |
| 9 | AMS1117 **OUT** | PMSA003I header **VIN** | 28 AWG, Dupont both ends |
| 10 | TinyS3 **9, 8** and the **GND** on that row | PMSA003I header **SCL, SDA, GND** | cable 1, **3V3 conductor removed** |
| 11 | TinyS3 **7** | PMSA003I header **SET** | 28 AWG, Dupont at the header |
| 12 | TinyS3 **6** | status LED, through a 1 kΩ resistor | 28 AWG, the resistor spliced in |
| 13 | GND splice | status LED, other leg | 28 AWG |
| 14 | PMSA003I **easyC socket B** | SCD41 either socket | cable 2: stock Qwiic |
| 15 | SCD41 other socket | BME688 either socket | cable 3: stock Qwiic |
| 16 | BME688 other socket | SHTC3 either socket | cable 4: stock Qwiic |
| 17 | pogo male, two contacts each net | Inkplate **VIN pad** and **GND pad** | 28 AWG, soldered to the 4 × 4 mm pads |

The PM board's 7-pin header is VIN, 3Vo, GND, SCL, SDA, RST, SET. Rows 9, 10 and 11 use **VIN, GND, SCL, SDA and
SET**; 3Vo and RST stay empty.

**The SET wire is optional.** The PM breakout pulls SET high through 100 kΩ
([parts.md](parts.md#pmsa003i--particulates)), so without it the fan runs from power-on and every reading is still
valid. With it, the firmware stops the fan between readings and the 30 s warm-up counts from when it starts.

[parts.md](parts.md#power-and-the-bus) has the current budget, the single ground return and the bus.

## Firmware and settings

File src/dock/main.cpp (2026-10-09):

// The dock's loop.
//
// A TinyS3 with the four sensors on their own regulator. Mains powered and
// always online: it connects once, and on each of the server's slots takes a
// reading and queues it, with its own status beside it. Between passes of its
// loop, once a second, it light-sleeps with Wi-Fi kept. Each pass also takes
// the SCD41's measurement when one is ready, so a reading holds their mean; it
// reads the other sensors at no other time. Before each slot it gets ready for
// it: it asks the server for its settings and applies any change, runs a
// recalibration the server asks for, and starts again a sensor that gave
// nothing at the last slot, so it has settled by this one. The server names the slots, every five minutes
// and every half hour overnight, and the time: the dock has no clock and asks
// for none elsewhere. The queue is in PSRAM, and each pass of the loop posts
// the oldest hundred of it to the server's /sensor-readings as one batch.
// BSEC's latest state goes to /calibration after each batch. The server
// offers the image its own version calls for on any answer, and the dock takes
// it once its queue is empty, then keeps it only if it posts. The display fetches
// the pages the server renders from the readings and knows nothing about any
// of this. The status LED under the display's right end shows the dock's state
// in the look the server sets for it: by default a slow pulse while the dock
// works and a flash while something is wrong. The PM module's fan, the dock's largest load, runs only for the
// window before each post, unless the settings keep it on.
#include <Arduino.h>
#include <Preferences.h>
#include <WiFi.h>
#include <Wire.h>
#include <driver/ledc.h>
#include <esp_pm.h>

#include "log_utils.h"
#include "mqtt_topic.h"
#include "network_utils.h"
#include "ota.h"
#include "ota_offer.h"
#include "settings.h"
#include "time_utils.h"
#include "user_agent.h"
#include "version.h"

#include "dock/FanWindow.h"
#include "dock/LightTriggers.h"
#include "dock/PostTimer.h"
#include "dock/StatusLed.h"
#include "dock/Trial.h"
#include "net/Backlog.h"
#include "net/BoardSettings.h"
#include "net/Calibration.h"
#include "net/ClientStatus.h"
#include "net/ResetReason.h"
#include "net/ServerClock.h"
#include "net/Stamp.h"
#include "net/Url.h"
#include "sensors/II2cBus.h"
#include "sensors/IClock.h"
#include "sensors/Readings.h"
#include "sensors/SensorSuite.h"

// The settings this image was built with, from src/defaults.cpp.
ClientConfig builtInSettings();

// hardware/assembly.md, "The TinyS3 on its strips", which names the same lines by
// their header pin: SCL on J4.5, SDA on J4.6, SET on J4.7, the LED on J4.8.
static const uint8_t kSdaPin = 8;
static const uint8_t kSclPin = 9;
static const uint8_t kPmSetPin = 7;
// Through a 1 kOhm resistor to the LED's anode, so a duty of 0 is dark.
static const uint8_t kLedPin = 6;

static ArduinoClock wallClock;

// The server's time, from the last response that carried it. Until the
// first, a reading is queued with its uptime and stamped later, and the BSEC
// task saves no time with its state. The BSEC task reads it too, so every
// use takes the lock.
static ServerClock serverClock;
static portMUX_TYPE clockLock = portMUX_INITIALIZER_UNLOCKED;
// UTC seconds at boot, from the first response; 0 until then.
static uint32_t bootEpoch = 0;

static uint32_t epochAt(uint32_t ms) {
    portENTER_CRITICAL(&clockLock);
    const uint32_t epoch = serverClock.epochAt(ms);
    portEXIT_CRITICAL(&clockLock);
    return epoch;
}
static uint32_t syncedEpoch() { return epochAt(millis()); }

static char calibrationURL[310];   // the server's /calibration; empty when there is no server
static char aboutURL[310];         // the server's /about, asked for the time until it is known
static char settingsURL[340];      // the server's /board-settings, with this board's name

// ─── The only part that knows which sensor implementation is in use ───────

#if defined(USE_MOCK_SENSORS)
#include "sensors/mock/EnvModel.h"
#include "sensors/mock/MockBme688.h"
#include "sensors/mock/MockPmsa003i.h"
#include "sensors/mock/MockScd41.h"
#include "sensors/mock/MockShtc3.h"

static EnvModel     room(7);
static MockShtc3    shtc3Impl(room);
static MockScd41    scd41Impl(room);
static MockPmsa003i pmImpl(room);
static MockBme688   bmeImpl(room);

// The simulated room only moves when it is told to. The first call settles
// it over the three hours before now; walking from epoch 0 would take
// minutes, so it waits for the server's time.
static void advanceSimulation(uint32_t epoch) {
    static bool started = false;
    if (!epoch) return;
    if (!started) {
        room.reset(epoch - 3 * 3600);
        started = true;
    }
    room.advanceTo(epoch);
}
static void startI2c() {}
static void logSensorBanner() { log(LOG_INFO, "mock sensors up; PM fan warming up for 30 s"); }
static const bool kMockSensors = true;
// The mock models BSEC's output itself, and has no state to keep.
static void startBsec() {}
static void fillBsecStatus(ClientStatus&) {}
static size_t calibrationBlock(char*, size_t, uint32_t&) { return 0; }
static void restoreFromServer() {}
static void setBsecSampleS(uint16_t) {}

#else
#include "sensors/Bme688Driver.h"
#include "sensors/BsecLibrary.h"
#include "sensors/BsecRunner.h"
#include "sensors/Pmsa003iDriver.h"
#include "sensors/Scd41Driver.h"
#include "sensors/Shtc3Driver.h"

static void setPmFanLine(bool high) { digitalWrite(kPmSetPin, high ? HIGH : LOW); }

static ArduinoI2cBus  i2cBus;
static Shtc3Driver    shtc3Impl(i2cBus, wallClock);
static Scd41Driver    scd41Impl(i2cBus, wallClock);
static Bme688Driver   bmeDriver(i2cBus, wallClock);
static Pmsa003iDriver pmImpl(i2cBus, wallClock, setPmFanLine);

static void startI2c() {
    pinMode(kPmSetPin, OUTPUT);
    digitalWrite(kPmSetPin, LOW);        // the fan stays off until the suite starts it
    Wire.begin(kSdaPin, kSclPin);
    Wire.setClock(100000);               // hardware/parts.md, the I2C bus: 100 kHz, and nothing cut
    // A sensor that drops off the bus would otherwise slow every sample.
    Wire.setTimeOut(ArduinoI2cBus::kTimeoutMs);
}

// BSEC's state in NVS, which keeps it across power cuts, OTA updates and USB
// uploads.
static const char kBsecNamespace[] = "bsec";
class NvsBsecStore : public IBsecStateStore {
public:
    bool load(BsecState& out) override {
        Preferences prefs;
        if (!prefs.begin(kBsecNamespace, true)) return false;
        out = BsecState();
        out.len = prefs.getBytes("state", out.blob, sizeof(out.blob));
        out.accuracy = prefs.getUChar("accuracy", 0);
        out.savedEpoch = prefs.getULong("saved", 0);
        // A copy saved without its rate is from before there was a choice: 3 s.
        out.sampleS = prefs.getUShort("rate", IBsec::kLpSampleS);
        // And one without its history is from Bosch's 4-day configuration.
        out.historyDays = prefs.getUChar("days", 4);
        prefs.end();
        return out.len > 0;
    }
    bool save(const BsecState& state) override {
        Preferences prefs;
        if (!prefs.begin(kBsecNamespace, false)) return false;
        const bool ok = prefs.putBytes("state", state.blob, state.len) == state.len;
        prefs.putUChar("accuracy", state.accuracy);
        prefs.putULong("saved", state.savedEpoch);
        prefs.putUShort("rate", state.sampleS);
        prefs.putUChar("days", state.historyDays);
        prefs.end();
        return ok;
    }
};

static BsecLibrary  bsecLibrary;
static NvsBsecStore bsecStore;
static BsecRunner   bsecRunner(bsecLibrary, bmeDriver, wallClock, bsecStore, syncedEpoch);
static BsecBme688   bmeImpl(bsecRunner);

// Above the loop's priority, so a post cannot make a sample late. Wire locks
// each transaction, so the task and the loop share the bus without a lock of
// their own.
static const uint32_t    kBsecStackBytes = 8192;
static const UBaseType_t kBsecPriority = 2;

static void bsecTask(void*) {
    for (;;) {
        const uint32_t waitMs = bsecRunner.step();
        vTaskDelay(pdMS_TO_TICKS(waitMs ? waitMs : 1));
    }
}

// The state NVS gave BSEC at boot, to weigh against the server's copy.
static BsecState nvsState;

static void startBsec() {
    const bool running = bsecRunner.begin(&nvsState);
    const BsecRunner::Status bsec = bsecRunner.status();
    if (!bsec.started) {
        log(LOG_WARNING, "[bsec] start: failed; retry in 3 s");
    } else {
        if (bsec.restored) {
            logf(LOG_INFO, "[bsec] start: NVS state (accuracy %u)", (unsigned)nvsState.accuracy);
        } else if (nvsState.len > 0) {
            logf(LOG_INFO, "[bsec] start: NVS state learned at %u s with %u days of history; starting from nothing",
                 (unsigned)nvsState.sampleS, (unsigned)nvsState.historyDays);
        } else {
            log(LOG_INFO, "[bsec] start: no saved state");
        }
        if (!running) log(LOG_WARNING, "[bsec] BME688: not answering; retry in 3 s");
    }
    xTaskCreatePinnedToCore(bsecTask, "bsec", kBsecStackBytes, nullptr, kBsecPriority, nullptr, 1);
}

static void fillBsecStatus(ClientStatus& s) {
    const BsecRunner::Status bsec = bsecRunner.status();
    s.bsecRunning = bsec.running;
    s.bsecRestored = bsec.restored;
    s.iaqAccuracy = bsec.accuracy;
    s.bsecLateCalls = bsec.lateCalls;
    s.bsecSavedEpoch = bsec.savedEpoch;
    s.bsecSampleS = bsec.sampleS;
}

// The state as of BSEC's last copy, as the calibration block, and when BSEC
// took it.
static size_t calibrationBlock(char* buf, size_t len, uint32_t& takenAt) {
    BsecState state;
    if (!bsecRunner.current(state)) return 0;
    takenAt = state.savedEpoch;
    return calibrationJson(state.blob, state.len, state.accuracy, state.savedEpoch, state.sampleS,
                           state.historyDays, buf, len);
}

// Asked once a boot, after the server has taken a batch of readings, so a failed
// request means the server holds no copy, not that it is down.
static bool askedServerForState = false;

static void restoreFromServer() {
    if (askedServerForState || !bootEpoch || !calibrationURL[0]) return;
    askedServerForState = true;

    const uint16_t rate = bsecRunner.sampleS();
    char url[400];
    snprintf(url, sizeof(url), "%s?device=%s&before=%lu&sample_s=%u&history_days=%u", calibrationURL,
             CLIENT_NAME, (unsigned long)bootEpoch, (unsigned)rate, (unsigned)IBsec::kHistoryDays);
    int32_t size = 1024;
    uint8_t* answer = downloadFile(url, clientUserAgent(CLIENT_NAME), &size, nullptr);
    // A copy BSEC cannot start from counts as none.
    const SavedCopy ours = {nvsState.len > 0 && learnedFor(nvsState, rate), nvsState.accuracy,
                            nvsState.savedEpoch};
    char why[80];
    if (!answer) {
        const SavedCopy none = {};
        if (describeChoice(ours, none, chooseCopy(ours, none), why, sizeof(why))) {
            logf(LOG_INFO, "[bsec] state: %s", why);
        }
        return;
    }
    char text[1024];
    const size_t n = size > 0 && (size_t)size < sizeof(text) ? (size_t)size : sizeof(text) - 1;
    memcpy(text, answer, n);
    text[n] = '\0';
    free(answer);

    BsecState theirs = {};
    if (!parseBme688Calibration(text, theirs.blob, sizeof(theirs.blob), theirs.len,
                                theirs.accuracy, theirs.savedEpoch, theirs.sampleS,
                                theirs.historyDays) ||
        !learnedFor(theirs, rate)) {
        logf(LOG_WARNING, "[bsec] state: %s selected (server state unreadable)",
             ours.present ? "NVS" : "none");
        return;
    }
    const SavedCopy server = {true, theirs.accuracy, theirs.savedEpoch};
    const CopyChoice choice = chooseCopy(ours, server);
    if (describeChoice(ours, server, choice, why, sizeof(why))) {
        logf(choice.takeServer ? LOG_NOTICE : LOG_INFO, "[bsec] state: %s", why);
    }
    if (choice.takeServer) bsecRunner.restartWith(theirs);
}

// A new rate starts BSEC again from nothing, then asks the server once more
// for a copy learned at that rate.
static void setBsecSampleS(uint16_t sampleS) {
    if (!IBsec::knownRate(sampleS) || sampleS == bsecRunner.sampleS()) return;
    const bool running = bsecRunner.status().started;
    bsecRunner.setSampleS(sampleS);
    askedServerForState = false;
    if (running) logf(LOG_NOTICE, "[bsec] a sample every %u s: starting again", (unsigned)sampleS);
}

// The readings come from the room itself, so there is nothing to advance.
static void advanceSimulation(uint32_t) {}
static void logSensorBanner() {
    logf(LOG_INFO, "sensors up; PM fan SET line driven high on IO%u", (unsigned)kPmSetPin);
}
static const bool kMockSensors = false;
#endif

// ─── Everything below is implementation-agnostic ──────────────────────────

// Until the server names a slot: five minutes.
static const uint32_t kFirstIntervalMs = 300000;

// Wi-Fi needs 80 MHz, and below it the APB clock follows the processor,
// which would move the serial baud rate. So 80 is both the floor and the
// choice: the bench board ran warm at 240. Power management holds it there
// between light sleeps.
static const uint32_t kCpuMhz = 80;

// Once a second is soon enough for everything the loop does: the fan's margin
// covers a slot reached a second late. Between passes the chip light-sleeps.
static const uint32_t kLoopMs = 1000;

// The fan settles in 30 s (Pmsa003iDriver::kWarmupMs), Plantower's figure;
// the margin covers a slot the loop reaches a little late. Each reading
// records how long the fan had actually run, so the database can show
// whether 30 s is enough. The settings can lengthen it, or keep the fan on.
static const uint32_t kFanWarmupMs = 30000;
static const uint32_t kFanMarginMs = 5000;
static FanWindow fanWindow(kFanWarmupMs + kFanMarginMs);
// Set at the pre-warm before a slot, cleared by the reading at it.
static bool prewarmed = false;
static bool fanRunning = true;    // the module's own pull-up holds it on until told otherwise
static uint32_t fanOnSinceMs = 0;

static PostTimer postTimer(kFirstIntervalMs);

static SensorSuite sensors(wallClock, shtc3Impl, scd41Impl, pmImpl, bmeImpl);

// One of the ESP32-S3's eight LEDC channels, and a timer. Nothing else on
// this board uses either, so the first will do.
static const ledc_mode_t    kLedMode = LEDC_LOW_SPEED_MODE;
static const ledc_channel_t kLedChannel = LEDC_CHANNEL_0;
static const ledc_timer_t   kLedTimer = LEDC_TIMER_0;
static StatusLed statusLed;

// Set once setup() has connected and started the sensors.
static volatile bool running = false;
// Set by a post the server would not take, and by having nowhere to post.
static volatile bool postFailed = false;
// Set while readings wait in the queue that should have gone.
static volatile bool backlogged = false;
// Keys of the server's settings the dock could not use, a bit each.
static volatile uint32_t settingsRefused = 0;
// From the latest reading: the air over a limit, a sensor calibrating.
static volatile bool poorAirNow = false;
static volatile bool calibratingNow = false;
// Set while a new image is written, with how much of it, in thousandths.
static volatile bool     updating = false;
static volatile uint16_t updatePermille = 0;

static_assert(kLedTriggers == StatusLed::kLooks, "a look for each state but UPDATING");
static_assert(kLedPatterns == StatusLed::kPatterns, "BoardSettings numbers the patterns as StatusLed");
static_assert(kLedNoLook == StatusLed::NONE, "BoardSettings marks no look as StatusLed does");

// The states that hold. While booting, the others are not known yet; once
// booted, RUNNING always holds, so a state with no look passes the light to it.
static uint8_t ledStates() {
    if (updating) return StatusLed::flag(StatusLed::UPDATING);
    if (!running) return StatusLed::flag(StatusLed::BOOTING);
    uint8_t holding = StatusLed::flag(StatusLed::RUNNING);
    const bool sensed = sensors.shtc3Present() && sensors.scd41Present() &&
                        sensors.pmPresent() && sensors.bme688Present();
    if (WiFi.status() != WL_CONNECTED || postFailed || backlogged || settingsRefused || !sensed) {
        holding |= StatusLed::flag(StatusLed::ERROR);
    }
    if (poorAirNow) holding |= StatusLed::flag(StatusLed::POOR_AIR);
    if (calibratingNow) holding |= StatusLed::flag(StatusLed::CALIBRATING);
    return holding;
}

// The longest the LED task waits for the pattern's next step, so a change of
// state shows within it.
static const uint32_t kLedWaitMaxMs = 250;
static const uint32_t kLedStackBytes = 2048;

// A task of its own, because setup() blocks for as long as the network takes
// and the starting pattern has to run through it.
static void ledTask(void*) {
    uint16_t written = 0xFFFF;
    for (;;) {
        const uint32_t nowMs = millis();
        statusLed.show(ledStates(), nowMs);
        statusLed.progress(updatePermille);
        const uint16_t duty = statusLed.dutyAt(nowMs);
        if (duty != written) {
            written = duty;
            ledc_set_duty(kLedMode, kLedChannel, duty);
            ledc_update_duty(kLedMode, kLedChannel);
        }
        vTaskDelay(pdMS_TO_TICKS(statusLed.msUntilChange(nowMs, kLedWaitMaxMs)));
    }
}

// The IDF's driver rather than Arduino's ledcAttachChannel(), which leaves the
// channel no output in light sleep. RC_FAST keeps running there, and the
// channel keeps its PWM.
static void startLed() {
    const ledc_timer_config_t timer = {
        .speed_mode = kLedMode,
        .duty_resolution = (ledc_timer_bit_t)StatusLed::kResolutionBits,
        .timer_num = kLedTimer,
        .freq_hz = StatusLed::kFrequencyHz,
        .clk_cfg = LEDC_USE_RC_FAST_CLK,
    };
    const ledc_channel_config_t channel = {
        .gpio_num = kLedPin,
        .speed_mode = kLedMode,
        .channel = kLedChannel,
        .intr_type = LEDC_INTR_DISABLE,
        .timer_sel = kLedTimer,
        .duty = 0,
        .hpoint = 0,
        .sleep_mode = LEDC_SLEEP_MODE_KEEP_ALIVE,
    };
    if (ledc_timer_config(&timer) != ESP_OK || ledc_channel_config(&channel) != ESP_OK) {
        log(LOG_ERROR, "status LED: LEDC setup failed");
    }
    // Core 0: the loop and the BSEC task both run on core 1.
    xTaskCreatePinnedToCore(ledTask, "led", kLedStackBytes, nullptr, 1, nullptr, 0);
}

// ─── The settings the server gives the dock ─────────────────────────────────

// What the dock runs: the defaults, then the copy in NVS, then each answer.
static BoardSettings boardSettings = defaultBoardSettings();
// Until the next reading, from the last answer; not kept across a restart.
static bool          ledDark = false;

// The last recalibration run, kept so a restart neither runs it again nor
// forgets to report it.
struct Recalibrated {
    uint32_t id;
    uint16_t ppm;
    bool     ok;
    int16_t  correction;
};
static Recalibrated recalibrated = {};

static const char kSettingsNamespace[] = "settings";
static char       settingsText[1024];

static void loadSettings() {
    Preferences prefs;
    if (!prefs.begin(kSettingsNamespace, true)) return;
    const size_t n = prefs.getString("doc", settingsText, sizeof(settingsText));
    if (prefs.getBytesLength("frc") == sizeof(recalibrated)) {
        prefs.getBytes("frc", &recalibrated, sizeof(recalibrated));
    }
    prefs.end();
    SettingsAnswer answer;
    if (n > 1 && parseBoardSettings(settingsText, strlen(settingsText), boardSettings, answer)) {
        boardSettings = answer.settings;
        settingsRefused = answer.refused;
        logf(LOG_INFO, "settings %s from NVS", boardSettings.version);
    }
}

static void saveSettings(const char* text) {
    Preferences prefs;
    if (!prefs.begin(kSettingsNamespace, false)) return;
    prefs.putString("doc", text);
    prefs.end();
}

static void saveRecalibrated() {
    Preferences prefs;
    if (!prefs.begin(kSettingsNamespace, false)) return;
    prefs.putBytes("frc", &recalibrated, sizeof(recalibrated));
    prefs.end();
}

// Each setting where it takes effect. Unchanged ones cost nothing, so this
// runs on every answer.
// The newest samples of the last reading, which the light's air and
// calibration triggers are judged from, and whether a recalibration waits for
// the SCD41.
static Readings latestReading = {};
static bool     scd41Recalibrating = false;

static void judgeReading() {
    const AirLimits limits = {boardSettings.scd41PoorPpm, boardSettings.pmPoorUgM3,
                              boardSettings.bsecPoorIaq};
    poorAirNow = poorAir(latestReading, limits);
    calibratingNow = calibrating(latestReading, scd41Recalibrating);
}

static void applySettings() {
    fanWindow.setLeadMs((uint32_t)boardSettings.pmWarmupS * 1000);
    sensors.setScd41Options(boardSettings.scd41OffsetC, boardSettings.scd41SelfCalibration);
    sensors.setScd41WarmupS(boardSettings.scd41WarmupS);
    sensors.setShtc3LowPower(boardSettings.shtc3LowPower);
    statusLed.brightness(ledDark ? 0 : boardSettings.ledBrightnessPct);
    for (uint8_t t = 0; t < kLedTriggers; ++t) {
        statusLed.look((StatusLed::State)t, (StatusLed::Pattern)boardSettings.ledPattern[t],
                       boardSettings.ledLengthMs[t]);
    }
    statusLed.smoothness(boardSettings.ledSmoothness);
    setBsecSampleS(boardSettings.bsecSampleS);
    setLogLevel(boardSettings.logLevel);
    judgeReading();
}

static void logSensorChanges();
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
void loop() {
    keepWiFiConnected();
    keepMQTTConnected();
    const uint32_t nowMs = millis();
    askForTime(nowMs);
    prewarmWhenDue(nowMs);
    driveFan(nowMs);
    sensors.poll();
    logScd41Polls();
    sampleWhenDue(nowMs);
    sendQueued();
    backlogged = queue->count() >= kBackloggedAt;
    delay(kLoopMs);
}

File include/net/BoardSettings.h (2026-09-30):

#pragma once
#include <cstddef>
#include <cstdint>

// The status light's triggers that have a look, in StatusLed::State's order,
// and its patterns, in StatusLed::Pattern's.
static const uint8_t kLedTriggers = 5;
static const uint8_t kLedPatterns = 11;
// The pattern of a trigger the server gives no look: StatusLed::NONE.
static const uint8_t kLedNoLook = 0xFF;

// The dock's settings as the server's GET /board-settings gives them, held to
// the dock's own limits whatever the server says.
struct BoardSettings {
    char     version[12];        // "" until the server has given any
    uint16_t pmWarmupS;          // 0 keeps the fan on
    float    scd41OffsetC;
    bool     scd41SelfCalibration;
    bool     shtc3LowPower;
    uint8_t  ledBrightnessPct;
    uint8_t  logLevel;           // log_utils.h's numbering: 1 error to 5 debug
    uint16_t bsecSampleS;        // IBsec::kLpSampleS or kUlpSampleS
    uint8_t  ledPattern[kLedTriggers];   // kLedNoLook for a trigger with none
    uint16_t ledLengthMs[kLedTriggers];  // one cycle of the pattern
    uint8_t  ledSmoothness;      // a stop of StatusLed's, 1 to 6
    // The limits over which the air is poor, for the light's trigger.
    uint16_t scd41PoorPpm;
    float    pmPoorUgM3;         // PM2.5
    uint16_t bsecPoorIaq;
    uint16_t scd41WarmupS;       // 0 keeps every SCD41 temperature and humidity
};

// The server's defaults, which the dock runs until the server has said anything.
BoardSettings defaultBoardSettings();

// The keys the dock can refuse, each a bit of SettingsAnswer::refused.
enum SettingKey : uint8_t {
    kPmWarmup,
    kScd41Offset,
    kScd41SelfCalibration,
    kShtc3LowPower,
    kLedBrightness,
    kLogLevel,
    kBsecSampleS,
    kLedLooks,
    kLedSmoothness,
    kScd41PoorPpm,
    kPmPoorUgM3,
    kBsecPoorIaq,
    kScd41Warmup,
    kSettingKeys,
};

// The key as the server names it, e.g. "pm.warmup_s".
const char* settingKeyName(uint8_t key);

struct SettingsAnswer {
    BoardSettings settings;
    uint32_t refused;            // a bit per SettingKey out of range or of the wrong kind
    bool     dark;               // the light stays dark until the next reading
    uint32_t recalibrateId;      // 0 for none
    uint16_t recalibratePpm;
};

// The server's answer on top of `current`: a key in range replaces current's
// value, one out of range keeps it and is marked refused, and one the answer
// lacks keeps it. False when the text is not a JSON object with a version.
bool parseBoardSettings(const char* json, size_t len, const BoardSettings& current,
                        SettingsAnswer& out);

// The refused keys as a JSON array. Returns the length written, or 0 when it
// does not fit.
size_t refusedJson(uint32_t refused, char* buf, size_t len);

// The room refusedJson needs with every key refused, and its terminator.
static const size_t kRefusedJsonBytes = 512;

static const uint16_t kPmWarmupMinS = 30;
static const uint16_t kPmWarmupMaxS = 600;
static const uint16_t kScd41WarmupMaxS = 600;
static const float    kScd41OffsetMaxC = 20.0f;
static const uint16_t kRecalibrateMinPpm = 400;
static const uint16_t kRecalibrateMaxPpm = 2000;
static const uint16_t kPoorPpmMin = 400;
static const uint16_t kPoorPpmMax = 5000;
static const float    kPoorUgM3Min = 1.0f;
static const float    kPoorUgM3Max = 500.0f;
static const uint16_t kPoorIaqMin = 1;
static const uint16_t kPoorIaqMax = 500;

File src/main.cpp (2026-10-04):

// The display's program.
//
// The Inkplate and nothing else: it fetches the page the server names, draws
// it, and deep-sleeps until the server says to come back. E-paper keeps its
// image without power, so the display wakes only for the next page, or for its
// next sync when that comes first. Every wake posts the display's own state —
// network, memory, panel, fetch counts — to the server's /sensor-readings,
// where the dock's readings also go; the display carries no sensors, so its
// document holds the client object and nothing else. A failed fetch leaves
// the last image on the panel and backs off before the next try.
//
// A freshly written image stays awake until a page proves it, since the
// bootloader takes back an image that is not confirmed.
//
// Two things replace the page with a notice the firmware draws itself: a
// server whose version this display cannot work with, and a server that has
// not answered three fetches in a row. The firmware also draws the splash
// screen: from the start until the first page, and while it writes an update,
// with a progress bar.
#include <Arduino.h>
#include <WiFi.h>

#include "epd.h"
#include "InkplateBoard.h"
#include "backoff.h"
#include "image.h"
#include "log_utils.h"
#include "network_utils.h"
#include "ota.h"
#include "settings.h"
#include "sleep_utils.h"
#include "wake.h"
#include "time_utils.h"
#include "user_agent.h"
#include "version.h"

#include "version_compat.h"

#include "display/AfterFetch.h"
#include "display/Notice.h"
#include "display/Splash.h"
#include "display/WakePlan.h"
#include "net/Backlog.h"        // postResult: what an HTTP status means for the sender
#include "net/ClientStatus.h"
#include "net/ResetReason.h"
#include "net/Url.h"

// The settings this image was built with, from src/defaults.cpp. epd declares
// no settings symbols of its own, so this one is the project's.
ClientConfig builtInSettings();

static InkplateBoard inkplateBoard;

static const uint8_t  kRotation = 0;             // landscape, as the board comes: the USB-C port on the right
// Buffer size when the server sends no Content-Length. An eight-grey
// 1280x720 PNG is under 200 KB.
static const int32_t  kDownloadFallbackBytes = 512 * 1024;
// A shorter wait is spent awake: a wake costs a boot and Wi-Fi.
static const uint32_t kShortestSleepS = 10;
static const uint32_t kWifiRetryS = 30;

static ClientConfig config;          // this board's own server URL and wifi
// True until this boot proves a freshly written image works.
static bool     onTrial = false;
static int      trialFailures = 0;

// Three failures in a row is enough to call a new image broken.
static const int kTrialFailureLimit = 3;

// Fetches the server has not answered, in a row. The back-off makes three of
// them about 26 minutes, long enough that a blip never replaces the page.
static const int kUnreachableAfter = 3;

// What outlasts deep sleep. A real start clears it, so the display then
// fetches a page at once and counts from zero.
static RTC_DATA_ATTR WakePlan plan;
static RTC_DATA_ATTR char     nextURL[256];      // from Canary-Next-URL; empty means the server URL
static RTC_DATA_ATTR int      unanswered;
static RTC_DATA_ATTR char     lastPageAt[32];    // when the last page arrived, in RFC 3339, for the unreachable notice
static RTC_DATA_ATTR uint32_t fetchOk;
static RTC_DATA_ATTR uint32_t fetchFailed;
// The last real start, which a wake from deep sleep is not: when, in UTC
// seconds by the server's clock (0 until it has answered), and why.
static RTC_DATA_ATTR uint32_t startedAt;
static RTC_DATA_ATTR int      startReason;

static const char kReadingsPath[] = "/sensor-readings";
static char     readingsURL[300];    // the server's /sensor-readings; empty disables posting
// Room for a next URL of up to 256 characters.
static char     clientJson[768];
static char     body[768 + 96];
static char     ipText[16];

// UTC seconds: the server's clock once it has answered, the RTC's until then.
static uint32_t epochNow() { return (uint32_t)time(nullptr); }

// Deep sleep until `at`, in UTC seconds, which the RTC holds. The ESP32's
// own timer stands behind the RTC's alarm, a little later, so a missed alarm
// costs a late page rather than a display that never wakes.
static void sleepUntil(uint32_t at) {
    const uint32_t seconds = secondsUntil(at, epochNow());
    enableWakeOnTimer(seconds + seconds / 20 + 60);
    logf(LOG_INFO, "sleeping %u s", seconds);
    sleep((time_t)at);
}

// A new image that cannot complete a cycle is not worth keeping. Mains
// power means a failure here is the image's fault, not a flat battery.
static void abandonTrialAfterRepeatedFailures(const char* why) {
    if (!onTrial) return;
    if (++trialFailures < kTrialFailureLimit) return;
    otaRollback(why);   // reboots into the previous image
}

// A freshly written image waits awake for the network, since proving itself
// is all it may do, and each failed join counts towards giving it up. Any
// other wake sleeps between tries.
static void connectNetworkOrSleep() {
    while (connectNetwork(config) != ESP_OK) {
        abandonTrialAfterRepeatedFailures("wifi connect timeout");
        logf(LOG_ERROR, "wifi connect timeout; trying again in %u s", kWifiRetryS);
        if (!onTrial) sleepUntil(epochNow() + kWifiRetryS);
        delay(kWifiRetryS * 1000);
    }
}

// Count the failure, arm the next try, and give up on an image on trial.
static void failedFetch(const char* why) {
    ++fetchFailed;
    uint32_t wait = pageFailed(plan, epochNow(), computeBackoffSeconds);
    logf(LOG_ERROR, "%s (back-off step %d): next try in %u s", why, plan.step, wait);
    abandonTrialAfterRepeatedFailures(why);
}

// The fetch afterFetch() is working on. Its steps are plain functions, so
// they find the page here.
static PageFetch*  fetched = nullptr;
static const char* drawError = nullptr;

// The image is freed as soon as it is drawn, or skipped, so the memory is
// there for an update's download.
static void releaseImage() {
    free(fetched->data);
    fetched->data = nullptr;
}

static bool drawFetchedPage() {
    // Nothing over the page: this board has no battery to report.
    const bool drawn = drawPage(*fetched, nullptr, 0, nullptr, &drawError);
    releaseImage();
    if (drawn) noticeReplaced();
    return drawn;
}

static bool drawVersionNotice() {
    releaseImage();
    const PageResponse& rsp = fetched->response;
    const bool offered = updateOffered(CLIENT_VERSION, rsp.firmwareVersion, rsp.firmwareURL,
                                       otaRejectedVersion());
    return showVersionNotice(CLIENT_VERSION, rsp.serverVersion, offered);
}
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

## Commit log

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2026-09-05 Offer and take firmware updates over the air
    The server offers an image from its firmware folder. The head applies it
    after a successful draw, confirms it with a page on the panel, and rolls
    back after three failures. The loop is built from epd's wake steps.
    CONTRIBUTING gives the bench procedure, with a rollback tested against an
    address that never answers.
    [main.cpp]
2026-09-06 Build on epd's kit and server core
    The head hands epd its board and a builtInSettings() ClientConfig, and
    the example defaults leave the MQTT broker as a placeholder. The firmware
    block sits under client, and the server pins epd-server to a release tag.
    Samples and tests use addresses that belong to no one.
    [main.cpp]
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2026-09-09 Version from git, CI, SD card settings and a larger partition
    CLIENT_VERSION comes from git describe, and CI builds every environment and
    runs the tests. Settings can come from an SD card. The partition table
    gives the firmware slots it can grow into. BATTERY.md holds a preliminary
    plan for battery power.
    [partitions.csv]
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2026-09-12 Add the desk enclosure
    The display head on a sensor base: four printed parts as STL and STEP, and
    the Fusion script that builds them. The BME688's JP2 is not a regulator
    bypass.
    [base-chassis.step, base-chassis.stl, base-shell.step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]
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2026-09-14 Revise the enclosure after its first print, and join the head on a pogo pair
    The first print and the real cables corrected the model, and the chain's
    ground is starred. The head joins the base on an 8-pin magnetic pogo pair
    and holds the Inkplate turned 180 degrees, so the image turns to match.
    3MF exports join STL and STEP.
    [base-chassis.3mf, base-chassis.step, base-chassis.stl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]
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2026-09-19 Show the dock's state on its LED, and stop its fan between posts
    The LED on IO6 pulses while the dock starts and works, and flashes while
    anything is wrong. The dock runs at 80 MHz, and the PM fan runs only for
    the 35 s before each post.
    [main.cpp]
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2026-09-19 Report how the dock's sensors are faring, and draw it
    Each dock document carries a health object: restarts, damaged answers,
    the BME688's flags and the SCD41's settings. A page draws it over the day.
    Chart outlines draw without a fill.
    [Scd41Driver.h, SensirionI2c.cpp]
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2026-09-23 Build the dock with Serial on the ESP32-S3's own USB controller
    The ESP32-S3 can drive its USB pins two ways: a built-in USB-Serial/JTAG
    controller, which works from the ROM onwards, or TinyUSB, a software
    stack the app starts. The um_tinys3 board definition picks TinyUSB.
    Built with TinyUSB, the dock stopped starting after a flash: no USB
    device came up, it never joined Wi-Fi, and no core dump was written.
    The same sources built with ARDUINO_USB_MODE=1, which puts Serial on
    the built-in controller, start normally. Why the TinyUSB build fails is
    not known yet.
    The built-in controller also keeps the boot log and any panic across a
    reset, and an upload needs no 1200-baud reset to reach the b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
2026-09-23 Wait for the SCD41 to take the pressure before the next command
    Before each reading the dock sends the SCD41 the ambient pressure, so the
    part can correct its CO2 value, and then asks whether data is ready. The
    part needs 1 ms to carry out the pressure command and ignores a command
    that arrives sooner, so the question went unanswered and the reading
    went out without CO2: 16 of 24 readings in one two-hour stretch.
    The driver now waits kCommandMs after the pressure command. The fake
    SCD41 in the host tests refuses a command sent inside that window, and
    a test sends the two back to back.
    [Scd41Driver.h]
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2026-09-23 Recalibrate the SCD41 and change its settings while it measures
    The SCD41 driver and mock take self-calibration on or off and run a forced
    recalibration, which answers with the correction the part made.
    SensorSuite sets the SCD41's temperature offset and self-calibration at
    each start of the part, since it keeps them only until a power cycle, and
    a change while it measures stops it for half a second to set them. A
    recalibration waits until the part has measured for the three minutes the
    datasheet asks for, and stops it for about a second. The SHTC3's low-power
    mode is a setting of the suite rather than a constant.
    [MockScd41.h, Scd41Driver.h, SensorSuite.h]
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2026-09-23 Set the status light's look for each of the dock's states
    The dock's states are now Starting, No Wi-Fi, Post failed, Sensor
    missing and Well, shown highest first, and the server's dock.led block
    gives each a look: off, solid, a pulse or a flash, repeating every 0.25
    to 10 s. The defaults keep a slow pulse while the dock works. Updating
    keeps its own pulse. The Dock tab sets the looks under Status light,
    and shows a look's interval only for a pulse or a flash.
    [BoardSettings.h, main.cpp]
2026-09-24 Put each board's own report fields under head or dock
    The client object keeps network, memory and version at the top, and
    each board's own fields in a block named for it: the head's panel and
    fetches under "head", the dock's sensors, queue, BSEC, settings and
    recalibration under "dock". A board no longer sends the other board's
    fields filled with zeros, so the head's report stops saying every
    sensor is missing, and the Boards page picks each card by its block.
    Sensors are judged from the newest report that has a dock block.
    [main.cpp]
2026-09-24 Hold the board reports' lock while a request reads or adds to them
    The server answers each request on a thread of its own, so two requests
    can read and add to the board reports at once. A read that ran while a
    post added a device failed with "dictionary changed size during
    iteration". Each method now holds the reports' lock, and the status page
    holds it across its reads so they agree.
2026-09-24 Escape the text boards post before a page shows it
    Airium writes a tag's text as given, so a report whose board name or
    version held markup put it into the Diagnostics pages, where it ran in the
    browser beside /web/config. Every page is now built with Html, which
    escapes each tag's text and attribute values unless they are Markup. The
    Config page's own escaping is no longer needed and is gone.
2026-09-24 Build on epd 0.7.4
    epd 0.7.4 answers each request on a thread of its own, so a browser's idle
    connection or a firmware download no longer holds up a board's post. A
    board whose store has no MQTT prefix logs to its image's, and the dock no
    longer warns that a response has no refresh time.
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2026-09-25 Say why each board last started, and count the faults apart
    The client object now carries "reset", the chip's own record of why the
    board last started: a power-on, a restart the firmware asked for, a wake
    from deep sleep, or a fault such as a crash, a watchdog or a brownout.
    The Diagnostics trace counts a restart a fault caused apart from the
    others, and does not count a wake from deep sleep as a restart.
    [main.cpp]
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2026-09-25 Lay the Diagnostics cards out by what each board is
    Client holds version, uptime and the chip's temperature. The head gets a
    Panel card: the next page, with a countdown the browser runs on, its
    fetches, back-off and the panel's temperature. The dock's Sensors card
    starts with its next report, from the server's own post schedule, and
    sets the PM fan's mode and BSEC's accuracy under the sensor each belongs
    to. The rows for a version change, the panel's pixels and the device name
    are gone, and the server no longer keeps the record of version changes.
    The columns are sized to their longest rows, so both boards line up.
2026-09-25 Draw a splash screen on the head at start and during an update
    The head holds the logo in its firmware and draws it at every start but
    a wake from deep sleep, before it joins the network; it stays until the
    first page or notice replaces it. While the head writes an update, it
    draws the logo with a progress bar under it and "Installing firmware"
    and the version under that. The bar fills in ten steps, each a partial
    update of the panel, so it is drawn in black and white.
    The logo is a trace of the drawing without the changes made for
    printing: trace.py also writes canary-logo-screen.svg, and
    scripts/notices.py renders it as include/head/splash.png. The line under
    the bar is in the pages' ital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
    [main.cpp]
2026-09-25 Leave the chip temperature out of the head's reports
    The head's classic ESP32 has no working temperature sensor: the call
    reads a fixed 53 °C. The head no longer sends chip_temp_c, and a status
    left without a chip temperature holds kNoTemp, so it never sends 0. The
    dock still sends its ESP32-S3's.
    [main.cpp]
2026-09-25 Sync the dock on ranges round the clock
    The dock's posts schedule is now dock.sync: up to 8 ranges covering the
    whole day, each from its start until the next range's, the last running
    past midnight to the first, each with an interval and 0 for off. A
    schedule with no range that syncs is refused, since the dock would take
    no readings. The dock is offline after two missed syncs, and a range
    that is off lengthens the silence it may keep.
    The Dock tab edits the ranges as rows beside the dial: a range splits in
    two or gives its hours to the one before, and its start drags round the
    dial, which hatches the ranges that are off. The light's dark hours are
    dock.led.dark, a window of their own. The e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
2026-09-26 Sync the head every so often, and change the page on time ranges
    head.sync is {every: seconds}, every half hour by default, on the wall
    clock from midnight, and 0 syncs only beside each page the head fetches.
    Each board is sent its own next slot in Canary-Next-Sensor-Poll-Seconds,
    by the name it states, and is offline after two missed slots of its own
    schedule, so the fixed two minutes for the head are gone. /about gives
    both boards' ranges.
    The page changes on time ranges round the clock: display.schedule of
    type timeranges, which epd has in place of interval, and canary refuses
    times. The time ranges themselves moved into epd as TimeRanges, and the
    dock's sync uses them from there.
    The D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
2026-09-26 Make the status light say what the dock needs
    The light's triggers are Booting, Error, Poor air quality, Calibrating and
    Running. Error takes in every fault the dock knows: no Wi-Fi, a post the
    server did not take, readings piling up, a missing sensor or a refused
    setting. Poor air quality holds while CO2, PM2.5 or a calibrated IAQ is
    at or over its limit, a setting in each sensor's section of the Dock
    tab. Calibrating holds while BSEC is below accuracy 2 or a recalibration
    waits for the SCD41. Running holds once the dock has booted.
    The patterns gain a blip, a swell and a ramp, and the light a smoothness
    of 4 to 64 steps a fade, or none, set by a slider in stops. The Dock tab
    previews one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
    [BoardSettings.h, main.cpp]
2026-09-27 Sleep the display between wakes
    E-paper keeps its image without power, so the display now deep-sleeps
    until its next page, or its next sync when that comes first, instead of
    staying awake. Every wake posts its state, which is its sync; the answer
    names the next sync and any update on offer. The RTC's alarm wakes it,
    with the ESP32's timer a little later as a backstop. What must outlast
    the sleep is in RTC memory. A freshly written image stays awake until a
    page confirms it, and uptime and reset reason count from the last real
    start, so a wake is not a restart.
    [main.cpp]
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2026-09-27 Say the dock is a TinyS3
    The dock sent its own name as its board, where the display sends its
    hardware, so the Boards page read "Dock, canary-dock". It now sends
    TinyS3. READINGS.md also no longer lists deep_sleep as a reset: the
    display sends the reset and uptime of its last real start.
    [main.cpp]
2026-09-27 Build the dock in a PlatformIO folder of its own
    The dock's automatic light sleep needs power management and tickless
    idle, which the core's precompiled IDF libraries leave out. env:dock now
    sets them in custom_sdkconfig, and pioarduino compiles the libraries
    again, into a package every build in the PlatformIO folder shares; the
    display then fails to build there. So the dock builds in
    ~/.platformio-canary-dock locally and in CI, and in /platformio/dock in
    the builder, in the volume it already has. scripts/dock_core.py stops a
    dock build in ~/.platformio before it changes anything.
    The firmware does not sleep yet: nothing calls esp_pm_configure.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
2026-09-27 Wait for the sensors by the clock, not by one delay
    While the dock light-sleeps, delay() can return up to 51 ms early by
    millis(), and the BME688 driver refuses a read before its conversion
    time. At BSEC's 300 s rate one refused read left five minutes without a
    cycle, and the dock marked the BME688 stopped at every reading.
    ArduinoClock::waitMs now delays again until millis() has passed the
    deadline (delayForMs, host-tested against a delay that runs short).
2026-09-28 Print the firmware builds in the builder's log
    build.sh sent PlatformIO's output only to a file, so a first dock build
    showed nothing in the container's log for about 13 minutes. The output
    now goes through tee to the log as it builds, and to the file the
    version check reads; pipefail keeps pio's exit status, and the tail of
    the file on failure goes, since the log already holds it all.
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2026-09-29 Give a builder a path, and split the docs by reader
    The README is now the path for a person who builds one: Bosch's licence,
    run the server, flash each board once, build it. CONTRIBUTING is for
    developers: an index, setup, tests and the dock's build folder, with the
    rest in docs/simulator.md, pages.md, boards.md, firmware-updates.md and
    releases.md, and hardware/wiring/README.md. bom.md keeps what to buy;
    the datasheet facts move to hardware/parts.md. enclosure.md is for a
    person who changes the model. docs/ARCHITECTURE.md and READINGS.md are
    lowercase, as the other docs are.
    CLAUDE.md no longer has an agent read CONTRIBUTING first: a table names
    the doc for each kind of task, and the two c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
    [main.cpp]
2026-09-29 Split the architecture doc by topic, in the present tense
    docs/architecture.md described CANARY as where it departs from the
    weather calendar, in one 490-line file. It is now the overview: the two
    boards and the server, why there are two boards, what comes from epd,
    and the repo tree. Each topic has its own doc: dock.md, display.md,
    schedules.md, led.md, versions.md and dock-settings.md, and the mocks'
    design joins simulator.md. CLAUDE.md names each one for its task.
    Stale facts fixed on the way: readings come at the server's slots, not
    every minute or every few seconds, and neither board stays awake between
    tasks; the header table lacks Canary-Server-Timezone; only the dock asks
    /about, un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
2026-09-29 Say when each board takes a saved config
    The config page waited for a poll of /about to fail and then succeed. A
    restart takes about 2 s and the page polled every 2 s, so it often never saw
    the server go down and said the server had not come back. /about now names
    the version of the config.yaml the server started on, the save answers with
    the new file's version, and the page reloads when the two match.
    The display holds none of its settings, so the server stamps each display
    report with a version of the display and image blocks. The Display tab shows
    the same Synchronized / Not synchronized banner as the Dock tab, and the save
    bar says when each board takes the new settings.
    Co-Authored-By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
2026-09-30 Count a post just before a slot as that slot's
    Since light sleep the dock's uptime runs about 350 ppm fast, so after a
    30-minute wait its post can reach the server a second before the slot. The
    answer was then "next slot in 1 s", and the dock took a second reading at
    once, mostly without CO2. A post up to 5 s before a slot now counts as that
    slot's, and the answer names the slot after it. Each answer sets the dock's
    timer again, so the error does not add up.
2026-09-30 Log why a reading has no CO2, and the kind of each damaged particle frame
    On 30 Sep the SCD41 gave no CO2 at 07:55 and 08:00, and the log could not
    say whether the part did not answer, sent a bad checksum, or had no data.
    The particle sensor's 3 to 7 damaged frames a day are counted as one
    number. The dock now logs the reason for a missing CO2 value, whether a
    restarted SCD41 was idle (as a reset leaves it) or still measuring, and
    each particle read of a sample with a damaged frame. Nothing else changes.
    [Scd41Driver.h, SensorSuite.h, main.cpp]
2026-10-01 Show the air quality index only at high accuracy
    BSEC's index swung between 86 and 200 on 1 Oct at accuracy 1 while the
    gas resistance, CO2, dust and humidity stayed level. Bosch rates the
    index at its best only at accuracy 3. The pages now hold the index back
    below 3, say "Calibrating.", and leave those readings out of the charts.
    The store keeps every reading as the dock posted it. The rule sits with
    the sea-level pressure in sources/corrections.py, whose source is now
    CorrectedSource.
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2026-10-01 Log the bytes of each damaged particle frame
    The PMSA003I sends 3 to 7 damaged frames a day, and the log says only
    what kind: a bad start or a bad checksum. A frame read while the module
    writes its next one holds parts of two frames; noise changes single
    bits. The dock now logs the 32 bytes of each damaged frame, 16 to a line,
    so the damage itself can be read.
    [SensorSuite.h, main.cpp]
2026-10-01 Show BSEC's static index, which Bosch recommends for a fixed device
    BSEC's IAQ stretches its scale to the last few days' air, so in a quiet
    room it swung between 86 and 200 while the gas resistance moved 5 %.
    Bosch's datasheet recommends that index for devices that move, and the
    static one for devices that stay in one place. The dock now posts the
    static index and its accuracy beside the other, and the pages show it,
    each index held back by its own accuracy. The other stays in the store
    for comparison. The stored history has no static index before this, so
    the IAQ charts fill in over three days.
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2026-10-02 Say that the PMSA003I damages a few frames a day by itself
    The logged bytes of damaged frames show the module stopping partway
    through a read: the frame keeps its start and reads FF from there on.
    The second read is good each time, so a few such frames a day do not
    point to a bad wire.
2026-10-03 Log a run of failed SCD41 polls
    The dock polls the SCD41 every second and ignored a poll that failed,
    so a fault that a later poll covered left no trace. Keep the run of
    polls that got no answer or a bad checksum, and log its first poll and
    the poll that ends it: two lines a run, not one a second. The times
    show whether faults come with the readings or at any time.
    [SensorSuite.h, main.cpp]
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2026-10-04 Roll back an update that cannot join Wi-Fi
    A board on its trial boot waited for Wi-Fi with no limit, so an image
    that could not join was never given up. Each failed join now counts
    as a trial failure, with the failed fetches on the display and the
    failed posts on the dock: three in a row roll the image back, about
    1.5 minutes. The dock's connectNetworkForever is waitForNetwork.
    [main.cpp]
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2026-10-08 Set what boards get at install on the Settings page
    The Server tab's Network group holds the server address and the HTTPS
    port; the Firmware tab's new Install group holds the Wi-Fi name, the
    Wi-Fi password (with Show beside its label) and the MQTT broker. The
    boards' broker defaults to the server's own, unless that is a local
    address no board can reach. A field can word the server's refusal of
    its value, so the page names no config key. An empty field leaves a key
    the file holds empty as it is.
2026-10-08 Install a board's firmware from canary's own page, with its network settings above the boards
    /web/install draws epd's install page in canary's layout, with an Install
    link in the menu. The server address, the Wi-Fi name and password and the
    boards' MQTT broker move there from the Settings page, since nothing but
    an install uses them. Each saves as a person leaves its field, through
    /web/config, and takes effect without a restart; the Install buttons
    wait until it has. A hand-drawn sketch of the device beside the board
    list points from each row to its part.
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2026-10-08 Renew the install page in place after a save
    After a save the page writes the fresh values into epd's config element
    and sends install:refresh, so epd's page names what is missing and sets
    the Install buttons itself, with no reload.
2026-10-08 Set up canary with setup.sh and the install page
    The README's first steps are now ./setup.sh and the install page, with
    install-firmware.sh for a browser that has no serial port and a note for
    a reverse proxy. PlatformIO stays for development, in docs/boards.md.
2026-10-09 Roll back a dock update that cannot get the server's time
    On a trial boot, an answer from /about without the server's time now
    counts as a trial failure, so an image that cannot reach the server is
    rolled back after three asks instead of staying on trial forever. A Wi-Fi
    join or the server's time starts the count again. The count moves into
    include/dock/Trial.h, with a host test.
    [main.cpp]
2026-10-16 Put a sign-in in front of the site, with a password from CANARY_PASSWORD
    With CANARY_PASSWORD set, every route needs a sign-in except the boards'
    routes and the files a page loads, so a new route stays closed until it
    is opened on purpose. /network.bin needs it, since it holds the Wi-Fi
    password. A sign-in lasts 30 days; 5 wrong passwords make an address
    wait 15 minutes. Without the variable the site stays open, so a new
    install has no step to do; the Server tab says so.
    Other apps read /history, /logs, /status and /sensor-readings with one
    access token, shown in the Server tab behind Show, with Replace. Every
    change whose Origin is another site gets 403, with a password or
    without. server.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
2026-10-23 Show CI, image and coverage badges in the README
    The Coverage workflow runs scripts/coverage_report.py --badges on each push
    to main and writes the server and firmware figures to a public gist, which
    the README's shields.io badges read. The firmware figure counts what the
    native environment compiles, src/sensors and src/net. The workflow stands
    apart from PlatformIO CI, so a failed write never stops the images.
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2026-10-30 Hold the dock build's PlatformIO core at 6.2.0
    The dock's build runs PlatformIO twice, the second time with a core the platform
    installs for itself, at the newest version. pioarduino 6.2.0.post1 fails the
    platform's own check for ">=6.2.0", so a dock build in a new folder stopped. It
    was the one version in the build with no pin.
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
